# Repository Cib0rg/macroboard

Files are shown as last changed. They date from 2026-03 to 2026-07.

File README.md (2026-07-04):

# ESP32-S3 Macro Keyboard

Программируемая макроклавиатура с открытым исходным кодом на базе ESP32-S3 — 10 кнопок с индивидуальными круглыми дисплеями, RGB подсветкой и настраиваемыми действиями.




## Обзор

Устройство аналогично Elgato Stream Deck, но с открытым исходным кодом. Каждая кнопка имеет собственный круглый дисплей 160×160 для отображения иконок, RGB LED подсветку и программируемое действие.
Отсутствует ограничение по входному напряжению, подключение зарядок с QC скорее всего сожжёт часть платы!
Включать сначала питание от 2А блока (нижний разъём), потом уже подключать ESP через встроенные. Иначе есть небольшой шанс выхода из строя DC-DC преобразователя на плате ESP.

## Реализованные возможности

### Прошивка (Firmware)

- ✅ **Драйвер дисплеев GC9A01** — 10 круглых дисплеев 160×160 через SPI с мультиплексором 2× 74HC138
- ✅ **PWM подсветка дисплеев** — регулировка яркости 0-255 через LEDC
- ✅ **WS2812 RGB LED** — индивидуальная подсветка каждой кнопки с настройкой цвета и яркости
- ✅ **USB Composite Device** — HID Keyboard + Consumer Control + Vendor Bulk (TinyUSB)
- ✅ **Протокол обмена** — 64-байтовые пакеты через Vendor Bulk endpoint
- ✅ **Конфигурация** — хранение настроек кнопок и энкодера в LittleFS
- ✅ **Папки** — вложенные папки кнопок (до 8 уровней глубины)
- ✅ **Передача изображений** — JPEG изображения на кнопки с дедупликацией по CRC32
- ✅ **Асинхронная запись LittleFS** — `save_task` на Core 0, очередь 20 слотов; протокол не блокируется на I/O, sync fallback при нехватке слотов; полная синхронизация ~17 изображений: ~11 с вместо ~39 с
- ✅ **LittleFS хранилище текстов** — тексты до 4096 байт в LittleFS по 5-компонентному ключу `(profile/folder/button/action_slot/step_index)`; покрывает: Keyboard > 44 байт, long press Keyboard, каждый шаг Sequence с длинным текстом, Sequence-блоб > 51 байт
- ✅ **Rotary encoder** — настраиваемые действия на CW/CCW/нажатие/долгое нажатие
- ✅ **Долгое нажатие** — отдельное действие и название для каждой кнопки (корневой и в папках)
- ✅ **Debounced кнопки** — обработка нажатий через прерывания с программным debounce
- ✅ **Действия кнопок**: Keyboard, Media (Consumer Control), Shell, Folder, Sequence, CustomHID, LaunchApp, NightMode

### Управляющий софт (Software)

- ✅ **Кроссплатформенный UI** — Avalonia UI (Linux, Windows, macOS)
- ✅ **Backend Service** — фоновый сервис для связи с устройством
- ✅ **IPC** — TCP-based коммуникация между UI и Backend с автоматическим переподключением
- ✅ **Редактор конфигурации** — создание, редактирование, синхронизация конфигураций с устройством (JSON)
- ✅ **Конфигурация кнопок** — inline-редактор с поддержкой всех типов действий
- ✅ **Захват клавиш** — запись комбинаций клавиш в реальном времени
- ✅ **Последовательности действий** — до 16 шагов с задержками
- ✅ **Медиа-клавиши** — Volume Up/Down, Mute, Play/Pause, Next/Prev Track
- ✅ **Превью изображений** — миниатюры в списке кнопок и превью в редакторе
- ✅ **Настройка LED** — выбор цвета через ColorPicker, яркость
- ✅ **Настройка подсветки дисплеев** — слайдер яркости в Dashboard и Settings
- ✅ **Tray icon** — работа в фоне, сворачивание в трей
- ✅ **Dashboard** — статус устройства, лог событий, управление яркостью
- ✅ **Diff-based синхронизация профиля** — при Send пересылаются только изменённые кнопки; fingerprint учитывает image path+mtime, action type+JSON, LED; типовая правка одной кнопки: ~5 с; холодная синхронизация ~17 изображений: ~11 с (async SPIFFS)
- ✅ **Синхронизация с устройством** — отправка/загрузка профилей через USB
- ✅ **Сохранение профиля** — Save пишет в исходный файл (откуда был загружен через Load), а не в AppData
- ✅ **LibUsbDotNet** — кроссплатформенная USB коммуникация (Linux/Windows/macOS)
- ✅ **Плагины (Stream Deck совместимость)** — запуск `.streamDeckPlugin` архивов и исполняемых плагинов, WebSocket API на порту 28196, Property Inspector на порту 8787; плагины хранятся в `plugins/` рядом с бинарником бэкенда
- ✅ **Валидация ввода** — Shell-команда ≤ 49 байт UTF-8, Custom HID ≤ 51 байт (соответствует `ACTION_DATA_MAX_LEN` прошивки); превышение показывает ошибку вместо молчаливой обрезки
- ✅ **Кэш иконок приложений** — иконки извлекаются один раз через P/Invoke и сохраняются в `%APPDATA%\MacroKeyboard\icons\`; повторное открытие диалога не вызывает P/Invoke

## Плагины

MacroKeyboard поддерживает плагины в стиле Elgato Stream Deck. Каждая кнопка может быть привязана к действию стороннего плагина, который получает события нажатий и управляет дисплеем.

Два режима работы:
- **Executable** — отдельный процесс на любом языке (C#, Node.js, Python), общается с бекендом через WebSocket на порту 28196.
- **Managed** — .NET DLL, загружается в процесс бекенда, получает прямой доступ к устройству через `IPlugin` / `IPluginContext`.

Плагины кладутся в папку `plugins/` рядом с бинарником бекенда в виде директории или `.zip`-архива с расширением `.sdPlugin`. Существующие плагины для Stream Deck работают с минимальными изменениями.

Подробное руководство по разработке плагинов: **[PLUGIN_DEVELOPMENT.html](PLUGIN_DEVELOPMENT.html)**

## Структура проекта

```
elgato/
├── firmware/                    # Прошивка ESP32-S3 (ESP-IDF v5.4, C)
│   └── main/
│       ├── hardware/            # Драйверы: дисплеи, LED, кнопки, энкодер
│       ├── profile/             # Менеджер профилей, исполнитель действий
│       ├── protocol/            # Обработчик протокола, передача изображений и текста
│       ├── storage/             # NVS, LittleFS, профили, изображения, длинный текст, async save_task
│       └── usb/                 # USB дескрипторы, HID keyboard, vendor endpoint
│
├── hardware/                    # Аппаратная часть
│   ├── case/                    # 3D-модели корпуса (OpenSCAD + STL для печати)
│   └── pcb/                     # Схемотехника и разводка PCB (KiCad)
│
├── software/                    # Управляющее приложение (.NET 10, C#)
│   └── src/
│       ├── MacroKeyboard.Core/          # Модели, IPC, интерфейсы сервисов
│       ├── MacroKeyboard.Communication/ # USB протокол, команды устройства
│       ├── MacroKeyboard.Infrastructure/# Реализация сервисов, репозитории
│       ├── MacroKeyboard.Backend/       # Фоновый сервис (IPC сервер, роутинг)
│       └── MacroKeyboard.UI/            # Avalonia UI (MVVM, CommunityToolkit)
│
└── plans/                       # Проектная документация
```

## Быстрый старт

### Сборка прошивки

```bash
cd firmware
# Через Docker (рекомендуется):
docker run --rm -v "$(pwd)":/project -w /project espressif/idf:v5.4 idf.py build
# Или локально с установленным ESP-IDF v5.4:
idf.py build
idf.py flash
```

### Сборка софта

```bash
cd software
dotnet build MacroKeyboard.sln
# Запуск Backend:
dotnet run --project src/MacroKeyboard.Backend
# Запуск UI:
dotnet run --project src/MacroKeyboard.UI
```

### Linux: доступ к USB без root

```bash
sudo cp software/scripts/99-macrokeyboard.rules /etc/udev/rules.d/
sudo udevadm control --reload-rules
```

## Технологии

### Прошивка

| Компонент | Технология |
|---|---|
| Платформа | ESP32-S3 N16R8 (16MB Flash, 8MB PSRAM) |
| Framework | ESP-IDF v5.4 |
| RTOS | FreeRTOS |
| USB | TinyUSB (HID + Vendor composite) |
| Язык | C99 |

### Софт

| Компонент | Технология |
|---|---|
| Runtime | .NET 10 |
| UI | Avalonia UI 12 |
| Архитектура | MVVM (CommunityToolkit.Mvvm) |
| USB | LibUsbDotNet 3.x |
| Изображения | SixLabors.ImageSharp |
| Сериализация | Newtonsoft.Json |
| Логирование | Serilog |

## Аппаратные компоненты

| Компонент | Модель | Кол-во | Примечания |
|---|---|---|---|
| Микроконтроллер | ESP32-S3 N16R8 | 1 | 16MB Flash, 8MB PSRAM |
| Дисплей | GC9A01 160×160 | 10 | Круглые TFT, SPI |
| Кнопки | Тактовые | 10 | GPIO с прерываниями |
| RGB LED | WS2812 | 10 | Адресные, RMT peripheral |
| Энкодер | Rotary encoder | 1 | С кнопкой |
| Мультиплексор | 74HC138 | 2 | Выбор дисплея (5+5) |

Схемотехника и разводка PCB находятся в директории [`hardware/pcb/`](hardware/pcb/) (формат KiCad).
3D-модели корпуса для печати — в [`hardware/case/`](hardware/case/) (OpenSCAD + STL).

## Протокол обмена данными

64-байтовые пакеты через USB Vendor Bulk endpoint:

```
[0]    Magic (0xA5)
[1]    Command ID
[2-3]  Payload Length
[4-5]  Sequence Number
[6-61] Payload (56 bytes)
[62]   Checksum (XOR)
[63]   End Byte (0x5A)
```

### Команды

| ID | Команда | Описание |
|----|---|---|
| 0x01 | PING | Проверка связи |
| 0x02 | GET_DEVICE_INFO | Информация об устройстве |
| 0x10 | SET_PROFILE | Активировать профиль |
| 0x11–0x12 | GET_PROFILE_INFO / FOLDER_STATE | Состояние профиля и текущей папки |
| 0x20–0x22 | IMAGE_TRANSFER | Передача изображений (start/chunk/end) |
| 0x30–0x34 | BUTTON_ACTION/NAME | Установка действия и имени кнопки (корневые и папки) |
| 0x35 | SET_ENCODER_ACTION | Настройка действий энкодера |
| 0x36–0x37 | LONG_PRESS_ACTION/NAME | Действие и название долгого нажатия |
| 0x38–0x3A | TEXT_TRANSFER | Передача текста/блоба в SPIFFS (start/chunk/end); Keyboard > 44 байт, long press, Sequence-шаги и блобы > 51 байт |
| 0x40–0x43 | LED/BACKLIGHT | Управление LED и подсветкой дисплеев |
| 0x50–0x53 | PROFILE_SAVE/LOAD/DELETE/REFRESH | Управление профилями и обновление дисплеев |

### Типы действий

| ID | Тип | Описание |
|----|-----|---|
| 0x01 | Keyboard | Эмуляция клавиатуры; текст ≤ 44 байт — inline, > 44 байт — SPIFFS |
| 0x02 | CustomHID | Произвольный HID report |
| 0x04 | Folder | Открытие папки кнопок |
| 0x06 | Shell | Выполнение shell-команды на PC |
| 0x07 | Sequence | Последовательность до 16 действий |
| 0x08 | LaunchApp | Запуск приложения на PC |
| 0x09 | Media | Медиа-клавиши (Volume, Mute, Play/Pause и др.) |
| 0x0A | NightMode | Переключение ночного режима (снижение яркости) |
| 0x0B | Plugin | Действие стороннего плагина (Stream Deck-совместимого) |

### LittleFS-хранилище текстов

Команды 0x38–0x3A передают текстовые данные, которые не влезают inline. На устройстве файл называется `/storage/txt_{P}_{F}_{B}_{A}_{S}.bin`, где:

| Поле | Смысл |
|---|---|
| P | profile_id (всегда 0) |
| F | folder_id: 0..15 = папка, 255 = root |
| B | button_id: 0..9; энкодер: 0x40–0x43 |
| A | action slot: 0 = short press, 1 = long press |
| S | step: 0xFF = прямое Keyboard, 0xFE = Sequence-блоб, 0..15 = шаг Sequence |

Что хранится в SPIFFS:
- **Keyboard** текст > 44 байт — `step=0xFF` (short), `step=0xFF, slot=1` (long press)
- **Sequence-шаг Keyboard** > 44 байт — `step=N` (индекс шага)
- **Sequence-блоб** > 51 байт — `step=0xFE`; в `action_data` кнопки записывается маркер `[0x01]`

ПО автоматически выбирает между inline и SPIFFS. Payload CMD_SET_BUTTON_TEXT_START: 9 байт — `[profile_id][folder_id][button_id][action_slot][step_index][data_size(4 LE)]`.

## Лицензия

WTFPL

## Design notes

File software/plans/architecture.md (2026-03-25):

# Архитектура управляющего софта на C#

## Обзор

Управляющее приложение построено на базе .NET 8.0 с использованием паттерна MVVM (Model-View-ViewModel) и принципов Clean Architecture.

**Ключевая особенность**: Двухкомпонентная архитектура с Backend Service для совместимости с плагинами Elgato Stream Deck.

## Архитектура системы

```
┌─────────────────────────────────────────────────────────┐
│  MacroKeyboard.Backend (Windows Service / Daemon)       │
│  ┌───────────────────────────────────────────────────┐  │
│  │  WebSocket Server (port 28196)                    │  │
│  │  - Stream Deck API эмуляция                       │  │
│  │  - Регистрация плагинов                           │  │
│  │  - Маршрутизация событий                          │  │
│  └───────────────────────────────────────────────────┘  │
│  ┌───────────────────────────────────────────────────┐  │
│  │  Device Manager                                   │  │
│  │  - USB HID коммуникация                           │  │
│  │  - Управление устройством                         │  │
│  └───────────────────────────────────────────────────┘  │
└─────────────────────────────────────────────────────────┘
                      ↕ WebSocket
┌─────────────────────────────────────────────────────────┐
│  Plugins (HTML/JS, Node.js, Python, C#)                 │
│  - OBS Studio Control                                   │
│  - Spotify Control                                      │
│  - Discord Integration                                  │
│  - Custom Actions                                       │
└─────────────────────────────────────────────────────────┘
                      ↕ IPC / WebSocket
┌─────────────────────────────────────────────────────────┐
│  MacroKeyboard.UI (Configuration Application)           │
│  - Profile Editor                                       │
│  - Button Configuration                                 │
│  - Plugin Browser                                       │
│  - Settings                                             │
└─────────────────────────────────────────────────────────┘
```

## Технологический стек

### Основные технологии

- **.NET**: 8.0 LTS
- **UI Framework**: WPF (Windows Presentation Foundation) или Avalonia UI (кроссплатформенный)
- **Архитектурный паттерн**: MVVM
- **DI Container**: Microsoft.Extensions.DependencyInjection
- **Logging**: Serilog
- **Testing**: xUnit, Moq

### Ключевые библиотеки

```xml
<PackageReference Include="HidLibrary" Version="3.3.40" />
<PackageReference Include="CommunityToolkit.Mvvm" Version="8.2.2" />
<PackageReference Include="Serilog" Version="3.1.1" />
<PackageReference Include="Serilog.Sinks.File" Version="5.0.0" />
<PackageReference Include="SixLabors.ImageSharp" Version="3.1.0" />
<PackageReference Include="Newtonsoft.Json" Version="13.0.3" />
<PackageReference Include="Hardcodet.NotifyIcon.Wpf" Version="1.1.0" />
```

## Структура решения

```
MacroKeyboard.sln
│
├── src/
│   ├── MacroKeyboard.Backend/           # Backend Service (Windows Service/Daemon)
│   │   ├── Program.cs
│   │   ├── BackendService.cs
│   │   ├── Services/
│   │   │   ├── DeviceManager.cs
│   │   │   └── EventRouter.cs
│   │   └── appsettings.json
│   │
│   ├── MacroKeyboard.PluginSystem/      # Система плагинов
│   │   ├── WebSocketServer/
│   │   │   ├── StreamDeckWebSocketServer.cs
│   │   │   ├── MessageHandler.cs
│   │   │   └── ProtocolAdapter.cs
│   │   │
│   │   ├── PluginHost/
│   │   │   ├── PluginManager.cs
│   │   │   ├── PluginLoader.cs
│   │   │   ├── PluginProcess.cs
│   │   │   └── PluginSandbox.cs
│   │   │
│   │   ├── PluginAPI/
│   │   │   ├── IPlugin.cs
│   │   │   ├── PluginContext.cs
│   │   │   ├── PluginManifest.cs
│   │   │   └── PluginEvents.cs
│   │   │
│   │   └── ImageAdapter/
│   │       ├── ImageConverter.cs
│   │       └── CircularMask.cs
│   │
│   ├── MacroKeyboard.Core/              # Бизнес-логика (не зависит от UI)
│   │   ├── Models/
│   │   │   ├── Profile.cs
│   │   │   ├── ButtonConfig.cs
│   │   │   ├── LedConfig.cs
│   │   │   ├── ActionConfig.cs
│   │   │   └── DeviceInfo.cs
│   │   │
│   │   ├── Services/
│   │   │   ├── IDeviceService.cs
│   │   │   ├── IProfileService.cs
│   │   │   ├── IImageService.cs
│   │   │   ├── ISettingsService.cs
│   │   │   └── IOtaService.cs
│   │   │
│   │   ├── Interfaces/
│   │   │   ├── IRepository.cs
│   │   │   └── IProtocolHandler.cs
│   │   │
│   │   └── Utilities/
│   │       ├── CrcCalculator.cs
│   │       └── ImageProcessor.cs
│   │
│   ├── MacroKeyboard.Communication/     # USB/HID коммуникация
│   │   ├── HidDevice/
│   │   │   ├── HidDeviceManager.cs
│   │   │   ├── HidDeviceMonitor.cs
│   │   │   └── HidDeviceInfo.cs
│   │   │
│   │   ├── Protocol/
│   │   │   ├── ProtocolHandler.cs
│   │   │   ├── PacketBuilder.cs
│   │   │   ├── PacketParser.cs
│   │   │   └── ProtocolConstants.cs
│   │   │
│   │   └── Commands/
│   │       ├── PingCommand.cs
│   │       ├── GetDeviceInfoCommand.cs
│   │       ├── SetProfileCommand.cs
│   │       ├── ImageTransferCommand.cs
│   │       ├── SetButtonActionCommand.cs
│   │       ├── SetLedColorCommand.cs
│   │       └── OtaUpdateCommand.cs
│   │
│   ├── MacroKeyboard.Infrastructure/    # Реализация сервисов
│   │   ├── Services/
│   │   │   ├── DeviceService.cs
│   │   │   ├── ProfileService.cs
│   │   │   ├── ImageService.cs
│   │   │   ├── SettingsService.cs
│   │   │   └── OtaService.cs
│   │   │
│   │   ├── Repositories/
│   │   │   ├── ProfileRepository.cs
│   │   │   └── ImageRepository.cs
│   │   │
│   │   └── Persistence/
│   │       ├── JsonFileStorage.cs
│   │       └── AppDataManager.cs
│   │
│   ├── MacroKeyboard.UI/                # Пользовательский интерфейс
│   │   ├── App.xaml / App.xaml.cs
│   │   ├── MainWindow.xaml / MainWindow.xaml.cs
│   │   │
│   │   ├── Views/
│   │   │   ├── DashboardView.xaml
│   │   │   ├── ProfileEditorView.xaml
│   │   │   ├── ButtonConfigView.xaml
│   │   │   ├── SettingsView.xaml
│   │   │   └── DiagnosticsView.xaml
│   │   │
│   │   ├── ViewModels/
│   │   │   ├── MainViewModel.cs
│   │   │   ├── DashboardViewModel.cs
│   │   │   ├── ProfileEditorViewModel.cs
│   │   │   ├── ButtonConfigViewModel.cs
│   │   │   ├── SettingsViewModel.cs
│   │   │   └── DiagnosticsViewModel.cs
│   │   │
│   │   ├── Controls/
│   │   │   ├── ButtonGrid.xaml
│   │   │   ├── ColorPicker.xaml
│   │   │   ├── KeySelector.xaml
│   │   │   └── ImageEditor.xaml
│   │   │
│   │   ├── Converters/
│   │   │   ├── BoolToVisibilityConverter.cs
│   │   │   ├── ColorToBrushConverter.cs
│   │   │   └── ByteArrayToImageConverter.cs
│   │   │
│   │   ├── Resources/
│   │   │   ├── Styles/
│   │   │   │   ├── Colors.xaml
│   │   │   │   ├── Buttons.xaml
│   │   │   │   └── TextBoxes.xaml
│   │   │   │
│   │   │   └── Icons/
│   │   │       └── (SVG/PNG иконки)
│   │   │
│   │   └── Behaviors/
│   │       ├── DragDropBehavior.cs
│   │       └── NumericTextBoxBehavior.cs
│   │
│   ├── MacroKeyboard.TrayApp/           # Tray приложение
│   │   ├── Program.cs
│   │   ├── TrayApplicationContext.cs
│   │   ├── TrayIcon/
│   │   │   └── TrayIconManager.cs
│   │   ├── Notifications/
│   │   │   └── NotificationService.cs
│   │   └── HotKeys/
│   │       ├── HotKeyManager.cs
│   │       └── GlobalHotKey.cs
│   │
│   └── MacroKeyboard.Shared/            # Общие компоненты
│       ├── Constants.cs
│       ├── Enums.cs
│       └── Extensions/
│           ├── ColorExtensions.cs
│           └── ImageExtensions.cs
│
├── tests/
│   ├── MacroKeyboard.Core.Tests/
│   ├── MacroKeyboard.Communication.Tests/
│   └── MacroKeyboard.UI.Tests/
│
└── docs/
    ├── API.md
    ├── UserGuide.md
    └── DeveloperGuide.md
```

## Детальное описание модулей

### 1. MacroKeyboard.Core

Ядро приложения, содержит бизнес-логику и модели данных.

#### Models

**Profile.cs**
```csharp
public class Profile
{
    public int Id { get; set; }
    public string Name { get; set; }
    public List<ButtonConfig> Buttons { get; set; } = new();
    public DateTime CreatedAt { get; set; }
    public DateTime ModifiedAt { get; set; }
}
```

**ButtonConfig.cs**
```csharp
public class ButtonConfig
{
    public int Id { get; set; }
    public ActionType ActionType { get; set; }
    public ActionConfig Action { get; set; }
    public string ImagePath { get; set; }
    public LedConfig Led { get; set; }
}

public enum ActionType
{
    None,
    Keyboard,
    CustomHid,
    Macro
}
```

**ActionConfig.cs**
```csharp
public abstract class ActionConfig
{
    public abstract byte[] ToBytes();
}

public class KeyboardAction : ActionConfig
{
    public List<ModifierKey> Modifiers { get; set; } = new();
    public Key Key { get; set; }
    public string Text { get; set; }
    
    public override byte[] ToBytes()
    {
        // Конвертация в формат протокола
    }
}

public class CustomHidAction : ActionConfig
{
    public byte[] Data { get; set; }
    
    public override byte[] ToBytes() => Data;
}
```

**LedConfig.cs**
```csharp
public class LedConfig
{
    public byte R { get; set; }
    public byte G { get; set; }
    public byte B { get; set; }
    public byte Brightness { get; set; }
    public LedEffect Effect { get; set; }
}

public enum LedEffect
{
    Static = 0,
    Breathing = 1,
    Rainbow = 2
}
```

#### Services (Interfaces)

**IDeviceService.cs**
```csharp
public interface IDeviceService
{
    event EventHandler<DeviceEventArgs> DeviceConnected;
    event EventHandler<DeviceEventArgs> DeviceDisconnected;
    
    Task<bool> ConnectAsync();
    Task DisconnectAsync();
    bool IsConnected { get; }
    Task<DeviceInfo> GetDeviceInfoAsync();
    Task<bool> PingAsync();
}
```

**IProfileService.cs**
```csharp
public interface IProfileService
{
    Task<List<Profile>> GetAllProfilesAsync();
    Task<Profile> GetProfileAsync(int id);
    Task<Profile> CreateProfileAsync(string name);
    Task UpdateProfileAsync(Profile profile);
    Task DeleteProfileAsync(int id);
    Task<Profile> DuplicateProfileAsync(int id);
    Task<bool> SendProfileToDeviceAsync(Profile profile);
    Task<Profile> LoadProfileFromDeviceAsync(int id);
}
```

**IImageService.cs**
```csharp
public interface IImageService
{
    Task<byte[]> LoadImageAsync(string path);
    Task<byte[]> ResizeImageAsync(byte[] image, int width, int height);
    Task<byte[]> ConvertToJpegAsync(byte[] image, int quality = 90);
    Task SaveImageAsync(string path, byte[] image);
    Task<byte[]> CropImageAsync(byte[] image, Rectangle cropArea);
}
```

### 2. MacroKeyboard.Communication

Модуль для коммуникации с устройством через USB HID.

#### HidDevice

**HidDeviceManager.cs**
```csharp
public class HidDeviceManager : IDisposable
{
    private const int VendorId = 0x303A;  // Espressif
    private const int ProductId = 0x4001;
    
    private HidDevice _device;
    private readonly ILogger _logger;
    
    public async Task<bool> ConnectAsync()
    {
        var devices = HidDevices.Enumerate(VendorId, ProductId);
        _device = devices.FirstOrDefault();
        
        if (_device == null)
            return false;
            
        _device.OpenDevice();
        _device.MonitorDeviceEvents = true;
        _device.Inserted += OnDeviceInserted;
        _device.Removed += OnDeviceRemoved;
        
        return _device.IsOpen;
    }
    
    public async Task<byte[]> SendCommandAsync(byte[] command, int timeoutMs = 1000)
    {
        if (!_device.IsOpen)
            throw new InvalidOperationException("Device not connected");
            
        // Отправка команды
        _device.Write(command);
        
        // Ожидание ответа
        var response = await Task.Run(() => 
        {
            var data = _device.Read(timeoutMs);
            return data.Data;
        });
        
        return response;
    }
}
```

**HidDeviceMonitor.cs**
```csharp
public class HidDeviceMonitor
{
    public event EventHandler<DeviceEventArgs> DeviceArrived;
    public event EventHandler<DeviceEventArgs> DeviceRemoved;
    
    public void StartMonitoring()
    {
        // Мониторинг подключения/отключения устройств
        // Использование WMI или ManagementEventWatcher
    }
}
```

#### Protocol

**ProtocolHandler.cs**
```csharp
public class ProtocolHandler : IProtocolHandler
{
    private readonly HidDeviceManager _deviceManager;
    private readonly ILogger _logger;
    
    public async Task<TResponse> SendCommandAsync<TResponse>(ICommand<TResponse> command)
    {
        var packet = PacketBuilder.Build(command);
        var response = await _deviceManager.SendCommandAsync(packet);
        return PacketParser.Parse<TResponse>(response);
    }
}
```

**PacketBuilder.cs**
```csharp
public static class PacketBuilder
{
    public static byte[] Build(byte commandId, byte[] payload)
    {
        var packet = new byte[64];
        packet[0] = 0xA5;  // Magic byte
        packet[1] = commandId;
        
        ushort payloadLength = (ushort)payload.Length;
        packet[2] = (byte)(payloadLength & 0xFF);
        packet[3] = (byte)((payloadLength >> 8) & 0xFF);
        
        // Sequence number
        packet[4] = 0;
        packet[5] = 0;
        
        // Payload
        Array.Copy(payload, 0, packet, 6, Math.Min(payload.Length, 56));
        
        // Checksum
        packet[62] = CalculateChecksum(packet, 0, 62);
        
        // End byte
        packet[63] = 0x5A;
        
        return packet;
    }
    
    private static byte CalculateChecksum(byte[] data, int start, int length)
    {
        byte checksum = 0;
        for (int i = start; i < start + length; i++)
        {
            checksum ^= data[i];
        }
        return checksum;
    }
}
```

#### Commands

**Base Command**
```csharp
public interface ICommand<TResponse>
{
    byte CommandId { get; }
    byte[] GetPayload();
}

public abstract class CommandBase<TResponse> : ICommand<TResponse>
{
    public abstract byte CommandId { get; }
    public abstract byte[] GetPayload();
}
```

**PingCommand.cs**
```csharp
public class PingCommand : CommandBase<PingResponse>
{
    public override byte CommandId => 0x01;
    
    public override byte[] GetPayload() => Array.Empty<byte>();
}

public class PingResponse
{
    public Version FirmwareVersion { get; set; }
    public uint Uptime { get; set; }
    public byte CurrentProfile { get; set; }
}
```

**ImageTransferCommand.cs**
```csharp
public class ImageTransferCommand : CommandBase<ImageTransferResponse>
{
    public byte ProfileId { get; set; }
    public byte ButtonId { get; set; }
    public byte[] ImageData { get; set; }
    
    public override byte CommandId => 0x20;  // START_IMAGE_TRANSFER
    
    public override byte[] GetPayload()
    {
        var payload = new byte[11];
        payload[0] = ProfileId;
        payload[1] = ButtonId;
        
        // Image size (little-endian)
        uint size = (uint)ImageData.Length;
        payload[2] = (byte)(size & 0xFF);
        payload[3] = (byte)((size >> 8) & 0xFF);
        payload[4] = (byte)((size >> 16) & 0xFF);
        payload[5] = (byte)((size >> 24) & 0xFF);
        
        payload[6] = 0x01;  // Format: JPEG
        
        // Width and height
        payload[7] = 160;
        payload[8] = 0;
        payload[9] = 160;
        payload[10] = 0;
        
        return payload;
    }
    
    public async Task<bool> SendAsync(IProtocolHandler protocol)
    {
        // 1. Start transfer
        var startResponse = await protocol.SendCommandAsync(this);
        if (!startResponse.Success)
            return false;
            
        // 2. Send chunks
        const int chunkSize = 50;
        int totalChunks = (ImageData.Length + chunkSize - 1) / chunkSize;
        
        for (int i = 0; i < totalChunks; i++)
        {
            int offset = i * chunkSize;
            int length = Math.Min(chunkSize, ImageData.Length - offset);
            
            var chunk = new byte[length];
            Array.Copy(ImageData, offset, chunk, 0, length);
            
            var chunkCommand = new ImageChunkCommand
            {
                TransferId = startResponse.TransferId,
                ChunkNumber = (ushort)i,
                Data = chunk
            };
            
            var chunkResponse = await protocol.SendCommandAsync(chunkCommand);
            if (!chunkResponse.Success)
                return false;
        }
        
        // 3. End transfer
        var crc32 = Crc32.Calculate(ImageData);
        var endCommand = new ImageEndCommand
        {
            TransferId = startResponse.TransferId,
            TotalChunks = (uint)totalChunks,
            Crc32 = crc32
        };
        
        var endResponse = await protocol.SendCommandAsync(endCommand);
        return endResponse.Success && endResponse.Crc32 == crc32;
    }
}
```

### 3. MacroKeyboard.Infrastructure

Реализация сервисов и репозиториев.

**DeviceService.cs**
```csharp
public class DeviceService : IDeviceService
{
    private readonly HidDeviceManager _deviceManager;
    private readonly IProtocolHandler _protocol;
    private readonly ILogger _logger;
    
    public event EventHandler<DeviceEventArgs> DeviceConnected;
    public event EventHandler<DeviceEventArgs> DeviceDisconnected;
    
    public bool IsConnected => _deviceManager.IsConnected;
    
    public async Task<bool> ConnectAsync()
    {
        var connected = await _deviceManager.ConnectAsync();
        if (connected)
        {
            DeviceConnected?.Invoke(this, new DeviceEventArgs());
            _logger.Information("Device connected");
        }
        return connected;
    }
    
    public async Task<DeviceInfo> GetDeviceInfoAsync()
    {
        var command = new GetDeviceInfoCommand();
        var response = await _protocol.SendCommandAsync(command);
        
        return new DeviceInfo
        {
            DeviceId = response.DeviceId,
            FirmwareVersion = response.FirmwareVersion,
            ButtonCount = response.ButtonCount,
            ProfileCount = response.ProfileCount,
            CurrentProfile = response.CurrentProfile,
            FreeSpace = response.FreeSpace
        };
    }
}
```

**ProfileService.cs**
```csharp
public class ProfileService : IProfileService
{
    private readonly IProfileRepository _repository;
    private readonly IDeviceService _deviceService;
    private readonly IProtocolHandler _protocol;
    
    public async Task<List<Profile>> GetAllProfilesAsync()
    {
        return await _repository.GetAllAsync();
    }
    
    public async Task<bool> SendProfileToDeviceAsync(Profile profile)
    {
        // 1. Send profile metadata
        var setProfileCommand = new SetProfileCommand
        {
            ProfileId = (byte)profile.Id
        };
        await _protocol.SendCommandAsync(setProfileCommand);
        
        // 2. Send button configurations
        foreach (var button in profile.Buttons)
        {
            // Send action
            var actionCommand = new SetButtonActionCommand
            {
                ProfileId = (byte)profile.Id,
                ButtonId = (byte)button.Id,
                ActionType = (byte)button.ActionType,
                ActionData = button.Action.ToBytes()
            };
            await _protocol.SendCommandAsync(actionCommand);
            
            // Send image
            if (!string.IsNullOrEmpty(button.ImagePath))
            {
                var imageData = await File.ReadAllBytesAsync(button.ImagePath);
                var imageCommand = new ImageTransferCommand
                {
                    ProfileId = (byte)profile.Id,
                    ButtonId = (byte)button.Id,
                    ImageData = imageData
                };
                await imageCommand.SendAsync(_protocol);
            }
            
            // Send LED config
            var ledCommand = new SetLedColorCommand
            {
                ProfileId = (byte)profile.Id,
                ButtonId = (byte)button.Id,
                R = button.Led.R,
                G = button.Led.G,
                B = button.Led.B,
                Brightness = button.Led.Brightness,
                Effect = (byte)button.Led.Effect
            };
            await _protocol.SendCommandAsync(ledCommand);
        }
        
        // 3. Save profile on device
        var saveCommand = new SaveProfileCommand
        {
            ProfileId = (byte)profile.Id
        };
        var saveResponse = await _protocol.SendCommandAsync(saveCommand);
        
        return saveResponse.Success;
    }
}
```

### 4. MacroKeyboard.UI

Пользовательский интерфейс на WPF с MVVM.

**MainViewModel.cs**
```csharp
public partial class MainViewModel : ObservableObject
{
    private readonly IDeviceService _deviceService;
    private readonly IProfileService _profileService;
    private readonly INavigationService _navigationService;
    
    [ObservableProperty]
    private bool _isDeviceConnected;
    
    [ObservableProperty]
    private string _deviceStatus;
    
    [ObservableProperty]
    private ObservableCollection<Profile> _profiles;
    
    [ObservableProperty]
    private Profile _selectedProfile;
    
    public MainViewModel(
        IDeviceService deviceService,
        IProfileService profileService,
        INavigationService navigationService)
    {
        _deviceService = deviceService;
        _profileService = profileService;
        _navigationService = navigationService;
        
        _deviceService.DeviceConnected += OnDeviceConnected;
        _deviceService.DeviceDisconnected += OnDeviceDisconnected;
        
        InitializeAsync();
    }
    
    private async void InitializeAsync()
    {
        await _deviceService.ConnectAsync();
        await LoadProfilesAsync();
    }
    
    private async Task LoadProfilesAsync()
    {
        var profiles = await _profileService.GetAllProfilesAsync();
        Profiles = new ObservableCollection<Profile>(profiles);
    }
    
    [RelayCommand]
    private async Task CreateProfileAsync()
    {
        var profile = await _profileService.CreateProfileAsync("New Profile");
        Profiles.Add(profile);
        SelectedProfile = profile;
    }
    
    [RelayCommand]
    private async Task SendToDeviceAsync()
    {
        if (SelectedProfile == null)
            return;
            
        var success = await _profileService.SendProfileToDeviceAsync(SelectedProfile);
        if (success)
        {
            // Show success notification
        }
    }
    
    private void OnDeviceConnected(object sender, DeviceEventArgs e)
    {
        IsDeviceConnected = true;
        DeviceStatus = "Connected";
    }
    
    private void OnDeviceDisconnected(object sender, DeviceEventArgs e)
    {
        IsDeviceConnected = false;
        DeviceStatus = "Disconnected";
    }
}
```

**ProfileEditorViewModel.cs**
```csharp
public partial class ProfileEditorViewModel : ObservableObject
{
    [ObservableProperty]
    private Profile _currentProfile;
    
    [ObservableProperty]
    private ButtonConfig _selectedButton;
    
    [ObservableProperty]
    private ObservableCollection<ButtonConfig> _buttons;
    
    [RelayCommand]
    private void SelectButton(int buttonId)
    {
        SelectedButton = Buttons.FirstOrDefault(b => b.Id == buttonId);
    }
    
    [RelayCommand]
    private async Task LoadImageAsync()
    {
        var dialog = new OpenFileDialog
        {
            Filter = "Image files (*.png;*.jpg;*.bmp)|*.png;*.jpg;*.bmp"
        };
        
        if (dialog.ShowDialog() == true)
        {
            SelectedButton.ImagePath = dialog.FileName;
            // Trigger UI update
            OnPropertyChanged(nameof(SelectedButton));
        }
    }
    
    [RelayCommand]
    private void SetLedColor(Color color)
    {
        SelectedButton.Led.R = color.R;
        SelectedButton.Led.G = color.G;
        SelectedButton.Led.B = color.B;
    }
}
```

### 5. MacroKeyboard.TrayApp

Приложение в системном трее.

**TrayApplicationContext.cs**
```csharp
public class TrayApplicationContext : ApplicationContext
{
    private readonly NotifyIcon _trayIcon;
    private readonly IDeviceService _deviceService;
    private readonly IProfileService _profileService;
    private readonly HotKeyManager _hotKeyManager;
    
    public TrayApplicationContext(
        IDeviceService deviceService,
        IProfileService profileService)
    {
        _deviceService = deviceService;
        _profileService = profileService;
        _hotKeyManager = new HotKeyManager();
        
        InitializeTrayIcon();
        RegisterHotKeys();
    }
    
    private void InitializeTrayIcon()
    {
        _trayIcon = new NotifyIcon
        {
            Icon = Resources.TrayIcon,
            ContextMenuStrip = CreateContextMenu(),
            Visible = true
        };
        
        _trayIcon.DoubleClick += OnTrayIconDoubleClick;
    }
    
    private ContextMenuStrip CreateContextMenu()
    {
        var menu = new ContextMenuStrip();
        
        // Profile submenu
        var profilesMenu = new ToolStripMenuItem("Profiles");
        for (int i = 0; i < 5; i++)
        {
            int profileId = i;
            profilesMenu.DropDownItems.Add($"Profile {i + 1}", null, 
                (s, e) => SwitchProfile(profileId));
        }
        menu.Items.Add(profilesMenu);
        
        menu.Items.Add(new ToolStripSeparator());
        menu.Items.Add("Settings", null, OnSettingsClick);
        menu.Items.Add("Exit", null, OnExitClick);
        
        return menu;
    }
    
    private void RegisterHotKeys()
    {
        // Ctrl+Alt+1-5 для переключения профилей
        for (int i = 0; i < 5; i++)
        {
            int profileId = i;
            _hotKeyManager.Register(
                ModifierKeys.Control | ModifierKeys.Alt,
                Keys.D1 + i,
                () => SwitchProfile(profileId));
        }
    }
    
    private async void SwitchProfile(int profileId)
    {
        var command = new SetProfileCommand { ProfileId = (byte)profileId };
        // Send to device
        
        ShowNotification($"Switched to Profile {profileId + 1}");
    }
    
    private void ShowNotification(string message)
    {
        _trayIcon.ShowBalloonTip(2000, "Macro Keyboard", message, ToolTipIcon.Info);
    }
}
```

## Dependency Injection

**ServiceCollectionExtensions.cs**
```csharp
public static class ServiceCollectionExtensions
{
    public static IServiceCollection AddMacroKeyboardServices(
        this IServiceCollection services)
    {
        // Core services
        services.AddSingleton<IDeviceService, DeviceService>();
        services.AddSingleton<IProfileService, ProfileService>();
        services.AddSingleton<IImageService, ImageService>();
        services.AddSingleton<ISettingsService, SettingsService>();
        services.AddSingleton<IOtaService, OtaService>();
        
        // Communication
        services.AddSingleton<HidDeviceManager>();
        services.AddSingleton<IProtocolHandler, ProtocolHandler>();
        
        // Repositories
        services.AddSingleton<IProfileRepository, ProfileRepository>();
        services.AddSingleton<IImageRepository, ImageRepository>();
        
        // ViewModels
        services.AddTransient<MainViewModel>();
        services.AddTransient<DashboardViewModel>();
        services.AddTransient<ProfileEditorViewModel>();
        services.AddTransient<ButtonConfigViewModel>();
        services.AddTransient<SettingsViewModel>();
        services.AddTransient<DiagnosticsViewModel>();
        
        // Logging
        services.AddLogging(builder =>
        {
            builder.AddSerilog(new LoggerConfiguration()
                .WriteTo.File("logs/app.log", rollingInterval: RollingInterval.Day)
                .CreateLogger());
        });
        
        return services;
    }
}
```

**App.xaml.cs**
```csharp
public partial class App : Application
{
    private readonly IServiceProvider _serviceProvider;
    
    public App()
    {
        var services = new ServiceCollection();
        services.AddMacroKeyboardServices();
        _serviceProvider = services.BuildServiceProvider();
    }
    
    protected override void OnStartup(StartupEventArgs e)
    {
        base.OnStartup(e);
        
        var mainWindow = new MainWindow
        {
            DataContext = _serviceProvider.GetRequiredService<MainViewModel>()
        };
        
        mainWindow.Show();
    }
}
```

## Продолжение в следующем файле

См. [`diagrams.md`](diagrams.md) для диаграмм взаимодействия компонентов.

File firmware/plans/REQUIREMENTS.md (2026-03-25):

# Требования к прошивке ESP32-S3 макроклавиатуры

## Аппаратная платформа

1. **Основа устройства**: ESP32-S3 N16R8 (16MB Flash, 8MB PSRAM)

## Компоненты устройства

2. **Дисплеи**: 10× GC9A01 круглые дисплеи 160×160 пикселей, 0.71 дюйма
   - Подключение: SPI
   - Выбор дисплея: через схему с двумя шифраторами 74HC138
   - 4 GPIO: 3 бита адреса (A0-A2) + 1 бит выбора шифратора (SEL)

3. **Кнопки**: 10× тактовые кнопки
   - Подключение: напрямую к GPIO контроллера
   - Обработка: только через прерывания (interrupt-driven), без polling
   - Debouncing: программный, 10-50 мс

4. **RGB LED**: 10× адресные светодиоды WS2812
   - Подключение: одна нога контроллера через RMT peripheral
   - Управление: цвет и яркость задаются извне

5. **Rotary Encoder**: 1× энкодер с кнопкой
   - Назначение: переключение профилей
   - Обработка: через GPIO прерывания

## USB подключение

4. Устройство подключается к компьютеру по native USB и определяется как:
   - **USB HID Keyboard** - для эмуляции нажатий клавиш
   - **USB HID Raw Device** - для обмена данными с управляющим софтом
   - **USB CDC (UART)** - для логирования диагностических данных (опционально)

## Функциональные требования

### Основная схема работы

7. **Взаимодействие с управляющим софтом**:
   - Управляющий софт отправляет изображения для экранов
   - Управляющий софт отправляет команды, закрепленные за кнопками
   - Команды двух видов:
     * "Отпечатать текст как клавиатура" (HID Keyboard)
     * "Послать сигнал как отдельное устройство" (HID Raw)

8. **Хранение данных**:
   - Устройство сохраняет команды и изображения в энергонезависимую память (Flash)
   - Использование SPIFFS для файловой системы
   - Использование NVS для настроек

9. **Отображение и реакция**:
   - Отрисовка изображений на дисплеях
   - Реакция на нажатия кнопок согласно сохраненным командам
   - Обновление RGB LED согласно профилю

### Профили

10. **Rotary Encoder**:
    - Используется для переключения профилей клавиш и экранов
    - Текущий профиль хранится на устройстве
    - Поддержка 3-5 профилей

11. **Логический юнит**:
    - Блок "светодиод + кнопка + экран" является единым юнитом
    - Яркость и цвет светодиода задаются извне контроллера
    - Изображение на экране соответствует функции кнопки

## Обязательные функции

6. **WiFi OTA**: ОБЯЗАТЕЛЬНО наличие WiFi OTA обновления прошивки
   - Подключение к WiFi по credentials из управляющего софта
   - Загрузка firmware по HTTP/HTTPS
   - Автоматический rollback при ошибке

## Дополнительные требования

### Производительность

- **Button latency**: < 10 мс от нажатия до действия
- **Display update**: < 50 мс на обновление одного дисплея
- **Profile switch**: < 100 мс на переключение профиля
- **Boot time**: < 2 секунды

### Надежность

- Проверка целостности данных (CRC32)
- Обработка ошибок и восстановление
- Защита от износа flash (wear leveling)
- Сохранение состояния при отключении питания

### Удобство использования

- Визуальная обратная связь через LED
- Статичные изображения на дисплеях (без анимаций)
- Логирование для отладки (опционально через USB CDC)

## Формат данных

### Изображения

- **Рекомендуемый формат**: JPEG
- **Размер**: 160×160 пикселей
- **Качество**: 80-90%
- **Средний размер файла**: 8-15 КБ

### Протокол обмена

- **Интерфейс**: USB HID Raw
- **Размер пакета**: 64 байта
- **Формат**: см. [`protocol.md`](../../plans/protocol.md)

## Ссылки на детальную документацию

- [Протокол обмена данными](../../plans/protocol.md)
- [Архитектура прошивки](../../plans/architecture.md)
- [Структура хранения данных](../../plans/storage.md)
- [Диаграммы взаимодействия](../../plans/system_flow.md)
- [План имплементации](../../plans/implementation_plan.md)
- [Использование готовых компонентов ESP-IDF](../../plans/esp_idf_components.md)
- [План тестирования](../../plans/testing_plan.md)

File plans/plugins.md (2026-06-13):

# Plugin System — Plan

> **Sequencing note:** Implement this plan before `ui_refactor.md`. The UI refactor's
> Config Panel (Phase 3) and Action Picker (Phase 2) explicitly depend on the plugin
> data structures and IPC API defined here. Running plugins first means the UI refactor
> is a clean port of known, working code rather than speculative scaffolding.

## Текущее состояние

Скелет написан, но ни в чём не подключён:
- `PluginManager` — дискавери и загрузка плагинов (executable + managed), не инстанциируется в DI
- `WebSocketServer` — WS на порту 28196 (совместим с Stream Deck API), не стартует
- `IPlugin` / `IPluginContext` / `PluginManifest` — интерфейсы готовы
- `ActionExecutorService` — нет case для Plugin actions
- `PluginContext` — все методы заглушки (`// TODO`)
- `CustomHid` — неправильная архитектура (отсылает данные на PC вместо прямой отправки USB HID)

## Архитектурные решения

### Два разных механизма — не путать

**Plugin Action** (`ActionType.Plugin = 0x0B`) — кнопка вызывает конкретный action конкретного плагина. Полностью на PC-стороне: firmware просто сообщает "нажата кнопка X", backend читает профиль, находит `PluginId + ActionId + Settings`, маршрутизирует в плагин.

**Custom HID** (`ActionType.CustomHid = 0x02`) — firmware сам посылает raw USB HID report напрямую в систему. PC не участвует. Сейчас реализован наоборот — надо переделать в firmware.

### Плагины бывают двух типов

- **Executable** (Node.js, Python и т.д.) — запускаются как отдельный процесс, общаются через WebSocket на порту 28196 с Stream Deck-совместимым протоколом (`keyDown`, `keyUp`, `didReceiveSettings`, и т.д.)
- **Managed** (.NET DLL) — загружаются в изолированный `AssemblyLoadContext`, вызываются напрямую через `IPlugin`

### Как кнопка знает о плагине

Профиль хранит `PluginActionConfig { PluginId, ActionId, Settings }`. Firmware хранит это как непрозрачный blob (action_type=0x0B + raw bytes). При нажатии firmware шлёт EVENT_BUTTON_PRESSED с buttonId. Backend читает свою копию профиля, достаёт `PluginActionConfig`, маршрутизирует.

### UI: откуда берётся список plugin actions

Backend держит список загруженных манифестов. UI запрашивает его через IPC при открытии редактора. Actions из манифестов добавляются в палитру (правая колонка) после стандартных actions.

> **Совместимость с ui_refactor.md:** Фаза 6 ниже использует текущую `ActionPaletteItems`
> инфраструктуру (drag-and-drop палитра). После выполнения `ui_refactor.md` Phase 2
> палитра заменяется Action Picker'ом, и `PluginActionInfo` объекты становятся входными
> данными для `ActionTypeRegistry.RegisterPlugin()`. Переход требует только изменений в
> Phase 6 UI-кода — Core/Backend части (Фазы 1–5) остаются без изменений.

---

## Фазы

---

### Фаза 1 — Core Models

**Файлы:**
- `MacroKeyboard.Core/Models/ActionType.cs`
- `MacroKeyboard.Core/Models/ActionConfig.cs`
- `MacroKeyboard.Core/Plugin/IPlugin.cs`

**Задачи:**

1. Добавить `Plugin = 0x0B` в enum `ActionType`.

2. Добавить класс `PluginActionConfig` в `ActionConfig.cs`:
   ```csharp
   public class PluginActionConfig : ActionConfig
   {
       public override ActionType ActionType => ActionType.Plugin;
       public string PluginId { get; set; } = string.Empty;
       public string ActionId { get; set; } = string.Empty;
       public string? Settings { get; set; }  // JSON строка с настройками action

       public override byte[] ToBytes()
       {
           // [pluginId\0actionId\0settings\0] — null-terminated strings
           var pluginIdBytes = Encoding.UTF8.GetBytes(PluginId + "\0");
           var actionIdBytes = Encoding.UTF8.GetBytes(ActionId + "\0");
           var settingsBytes = Encoding.UTF8.GetBytes((Settings ?? "") + "\0");
           return [..pluginIdBytes, ..actionIdBytes, ..settingsBytes];
       }
   }
   ```
   Добавить в `FromActionType` factory и в JSON десериализацию (`IpcCommandHandler`).

3. Обновить `IPlugin.OnButtonPressedAsync` — передавать actionId и settings:
   ```csharp
   Task OnButtonPressedAsync(string actionId, string? settings, int buttonIndex, CancellationToken ct = default);
   Task OnButtonReleasedAsync(string actionId, string? settings, int buttonIndex, CancellationToken ct = default);
   ```

---

### Фаза 2 — Firmware

**Файлы:**
- `firmware/main/profile/profile_types.h`
- `firmware/main/profile/action_executor.c`
- `firmware/main/hardware/usb_hid_keyboard.h` / `.c`

**Задачи:**

1. Добавить `ACTION_TYPE_PLUGIN = 0x0B` в `action_type_t`.
   Добавить метку `"Plugin"` в `profile_manager.c` (label switch).

2. Добавить case `ACTION_TYPE_PLUGIN` в `execute_single_action`:
   ```c
   case ACTION_TYPE_PLUGIN:
       // Поведение идентично обычному нажатию — backend читает профиль сам
       // Firmware просто репортит кнопку, весь dispatch на PC
       // Ничего дополнительно делать не надо
       break;
   ```
   (EVENT_BUTTON_PRESSED уже отсылается общим кодом после switch.)

3. **Исправить Custom HID** — убрать отсылку на PC, вместо этого слать raw USB HID report:
   ```c
   case ACTION_TYPE_CUSTOM_HID:
       if (data_len > 0)
           usb_hid_send_raw_report(data, data_len);
       break;
   ```
   Добавить `usb_hid_send_raw_report(const uint8_t* data, uint16_t len)` в `usb_hid_keyboard.h` и реализовать в `.c` (передать в нужный HID endpoint).

---

### Фаза 3 — Backend: PluginContext + PluginManager

**Файлы:**
- `MacroKeyboard.Backend/Plugin/PluginManager.cs`

**Задачи:**

1. Внедрить `IDeviceService` в `PluginContext` (сейчас он принимает только `ILogger`):
   ```csharp
   internal class PluginContext : IPluginContext
   {
       private readonly IDeviceService _deviceService;
       // ...
   }
   ```

2. Реализовать все заглушки в `PluginContext`:
   - `SetButtonImageAsync` → `_deviceService.SendButtonImageAsync(0, buttonIndex, imageData)`
   - `SetButtonTitleAsync` → `_deviceService.SetButtonNameAsync(0, buttonIndex, title)`
   - `SetLedColorAsync` → `_deviceService.SetLedColorAsync(0, buttonIndex, new LedConfig { R=r, G=g, B=b })`
   - `ShowAlertAsync` → flash LED: выкл на 200ms, вкл обратно
   - `GetSettingsAsync` / `SaveSettingsAsync` → JSON файл в `%APPDATA%\MacroKeyboard\plugins\{pluginId}\settings.json`

3. Добавить `DispatchButtonPressAsync` в `PluginManager`:
   ```csharp
   public async Task DispatchButtonPressAsync(string pluginId, string actionId,
       string? settings, int buttonIndex, CancellationToken ct = default)
   ```
   - Для managed плагина: вызвать `_pluginInstance.OnButtonPressedAsync(actionId, settings, buttonIndex, ct)`
   - Для executable плагина: отправить через `WebSocketServer.BroadcastAsync` событие `keyDown` в формате Stream Deck:
     ```json
     { "event": "keyDown", "action": "{actionId}", "context": "{pluginId}:{buttonIndex}", "payload": { "settings": {...}, "coordinates": {...} } }
     ```

4. Добавить аналогичный `DispatchButtonReleaseAsync`.

5. Добавить `GetLoadedActions()`:
   ```csharp
   public IEnumerable<(string PluginId, string PluginName, PluginAction Action)> GetLoadedActions()
   ```
   Нужен для UI — формирует список доступных plugin actions для палитры/пикера.

---

### Фаза 4 — Backend: DI и жизненный цикл

**Файлы:**
- `MacroKeyboard.Backend/Program.cs`
- `MacroKeyboard.Backend/BackendService.cs`

**Задачи:**

1. Зарегистрировать в `Program.cs`:
   ```csharp
   builder.Services.AddSingleton<PluginManager>(sp => new PluginManager(
       sp.GetRequiredService<ILogger<PluginManager>>(),
       Path.Combine(AppContext.BaseDirectory, "plugins")));
   builder.Services.AddSingleton<WebSocketServer>();
   ```

2. В `BackendService.StartAsync`:
   ```csharp
   await _webSocketServer.StartAsync(ct);
   await _pluginManager.LoadPluginsAsync(ct);
   // start all loaded plugins
   foreach (var manifest in _pluginManager.GetPlugins())
       await _pluginManager.StartPluginAsync(manifest.Id, ct);
   ```

3. В `BackendService.StopAsync` — остановить плагины и WS сервер.

---

### Фаза 5 — Backend: ActionExecutorService + IPC

**Файлы:**
- `MacroKeyboard.Backend/Services/ActionExecutorService.cs`
- `MacroKeyboard.Backend/Services/IpcCommandHandler.cs`
- `MacroKeyboard.Shared/IPC/IpcMessage.cs`

**Задачи:**

1. Внедрить `PluginManager` в `ActionExecutorService`. Добавить case:
   ```csharp
   case ActionType.Plugin:
       await ExecutePluginActionAsync(e.ProfileId, e.ButtonId);
       break;
   ```
   ```csharp
   private async Task ExecutePluginActionAsync(byte profileId, byte buttonId)
   {
       var profile = await _profileService.GetProfileAsync(profileId);
       var button = profile?.Buttons.FirstOrDefault(b => b.ButtonId == buttonId);
       if (button?.Action is not PluginActionConfig action) return;
       await _pluginManager.DispatchButtonPressAsync(
           action.PluginId, action.ActionId, action.Settings, buttonId);
   }
   ```

2. Добавить IPC команду `plugin.list` в `IpcCommandHandler`:
   - Обрабатывает запрос от UI
   - Возвращает список `(pluginId, pluginName, actionId, actionName, actionIcon, tooltip)` из `_pluginManager.GetLoadedActions()`

3. Добавить `MessageType` константу `"plugin.list"` в `IpcMessage.cs`.

---

### Фаза 6 — UI: палитра + настройка plugin actions

**Файлы:**
- `MacroKeyboard.UI/ViewModels/ProfileEditorViewModel.cs`
- `MacroKeyboard.UI/ViewModels/ButtonConfigDialogViewModel.cs`
- `MacroKeyboard.UI/Views/ProfileEditorView.axaml`

> **Временная реализация:** этот UI-слой использует текущую drag-and-drop палитру.
> После выполнения `ui_refactor.md` Phase 2 он будет заменён на Action Picker —
> `PluginActionInfo` объекты станут источником данных для `ActionTypeRegistry.RegisterPlugin()`.
> Core/Backend код (Фазы 1–5) при этом не меняется.

**Задачи:**

1. В `ProfileEditorViewModel` при инициализации запросить плагины через IPC:
   ```csharp
   var pluginActions = await _ipcClient.SendRequestAsync<List<PluginActionInfo>>("plugin.list");
   foreach (var pa in pluginActions)
   {
       ActionPaletteItems.Add(new ActionPaletteItem(ActionType.Plugin, pa.ActionName, pa.Icon, pa.Tooltip)
       {
           PreConfiguredAction = new PluginActionConfig
           {
               PluginId = pa.PluginId,
               ActionId = pa.ActionId
           }
       });
   }
   ```
   Плагины добавляются в конец палитры после "None", сгруппированные по плагину.

2. В `ButtonConfigDialogViewModel`:
   - Добавить `IsPluginAction => SelectedActionType == ActionType.Plugin`
   - Добавить свойства `PluginId`, `PluginActionId`, `PluginSettings` (string, JSON)
   - В `Save()` добавить case:
     ```csharp
     ActionType.Plugin => new PluginActionConfig
     {
         PluginId = PluginId,
         ActionId = PluginActionId,
         Settings = string.IsNullOrWhiteSpace(PluginSettings) ? null : PluginSettings
     }
     ```
   - В `CurrentActionDisplayName` добавить `ActionType.Plugin => $"Plugin: {PluginActionId}"`
   - В `CurrentActionIcon` добавить `ActionType.Plugin => "🔌"`
   - В загрузке (`if (buttonConfig.Action is PluginActionConfig pa)`) — заполнить поля

3. В `ProfileEditorView.axaml` добавить секцию для Plugin action (появляется когда `IsPluginAction`):
   ```xml
   <Border IsVisible="{Binding IsPluginAction}" ...>
     <StackPanel>
       <TextBlock Text="PLUGIN ACTION" />
       <TextBlock Text="{Binding PluginId}" Opacity="0.6" />  <!-- read-only -->
       <TextBlock Text="Settings (JSON):" />
       <TextBox Text="{Binding PluginSettings}" AcceptsReturn="True" Height="80"
                PlaceholderText="{}" FontFamily="Monospace" />
     </StackPanel>
   </Border>
   ```

4. В `FlattenedButtonItem.Label` / `ActionText` добавить отображение для `PluginActionConfig`:
   ```csharp
   PluginActionConfig pa => $"🔌 {pa.ActionId}",
   ```

---

### Фаза 7 — Custom HID: UI fix

**Файлы:**
- `MacroKeyboard.UI/ViewModels/ButtonConfigDialogViewModel.cs`
- `MacroKeyboard.UI/Views/ProfileEditorView.axaml`
- `MacroKeyboard.Backend/Services/ActionExecutorService.cs`

После исправления firmware Custom HID больше не требует PC-обработки. Нужно:

1. В UI заменить "coming soon" на поле ввода hex-данных (уже есть в `SequenceStepViewModel` — скопировать паттерн):
   - Добавить `CustomHidData` property в `ButtonConfigDialogViewModel`
   - Добавить `ParseHexString` (скопировать из `SequenceStepViewModel`)
   - В `Save()` добавить: `ActionType.CustomHid => new CustomHidAction { Data = ParseHexString(CustomHidData) }`
   - В `ProfileEditorView.axaml` заменить "coming soon" на `<TextBox Text="{Binding CustomHidData}" Placeholder="FF 00 A0 ..." />`

2. Убрать Custom HID из `ActionExecutorService` (он не нужен — firmware всё делает сам). Ничего добавлять не надо, просто не добавлять case.

---

## Зависимости между фазами

```
Фаза 1 (Core Models)
    ├── Фаза 2 (Firmware) — независима, можно параллельно
    ├── Фаза 3 (PluginManager) — зависит от Фазы 1 (новый IPlugin.OnButtonPressedAsync)
    │       └── Фаза 4 (DI) — зависит от Фазы 3
    │               └── Фаза 5 (ActionExecutor + IPC) — зависит от Фаз 1, 3, 4
    │                       └── Фаза 6 (UI) — зависит от Фазы 5
    └── Фаза 7 (Custom HID fix) — почти независима, только Фаза 2 нужна для firmware части
```

## Что НЕ входит в план (за рамками v1)

- **Property Inspector** — загрузка HTML-файла плагина как настроечного UI (полная Stream Deck совместимость). В v1 достаточно JSON text area.
- **Hot reload плагинов** — сейчас требует перезапуска backend.
- **Plugin marketplace / установщик** — просто папка `plugins/` рядом с бинарником.
- **Версионирование API** — `MinimumBackendVersion` в манифесте пока не проверяется.
- **Права доступа плагинов** — плагин может делать всё что позволяет `IPluginContext`, без ограничений.

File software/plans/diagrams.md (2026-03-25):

# Диаграммы взаимодействия управляющего софта

## Архитектура приложения

```mermaid
graph TB
    subgraph UI["Presentation Layer (WPF/Avalonia)"]
        VIEWS[Views]
        VM[ViewModels]
        CONTROLS[Custom Controls]
    end
    
    subgraph CORE["Core Layer"]
        MODELS[Models]
        INTERFACES[Interfaces]
        SERVICES[Service Interfaces]
    end
    
    subgraph INFRA["Infrastructure Layer"]
        IMPL[Service Implementations]
        REPOS[Repositories]
        STORAGE[File Storage]
    end
    
    subgraph COMM["Communication Layer"]
        HID[HID Device Manager]
        PROTOCOL[Protocol Handler]
        COMMANDS[Commands]
    end
    
    VIEWS --> VM
    VM --> SERVICES
    SERVICES --> IMPL
    IMPL --> REPOS
    IMPL --> PROTOCOL
    PROTOCOL --> HID
    PROTOCOL --> COMMANDS
    REPOS --> STORAGE
    
    VM --> MODELS
    IMPL --> MODELS
```

## Запуск приложения

```mermaid
sequenceDiagram
    participant USER as Пользователь
    participant APP as App.xaml.cs
    participant DI as DI Container
    participant MAIN as MainWindow
    participant VM as MainViewModel
    participant DEV as DeviceService
    participant PROF as ProfileService
    
    USER->>APP: Запуск приложения
    APP->>DI: ConfigureServices()
    DI->>DI: Register all services
    DI-->>APP: ServiceProvider
    
    APP->>MAIN: Create MainWindow
    APP->>DI: GetService<MainViewModel>()
    DI->>VM: new MainViewModel(services...)
    VM->>DEV: Subscribe to events
    VM->>DEV: ConnectAsync()
    
    DEV->>DEV: Search for device
    alt Device found
        DEV-->>VM: DeviceConnected event
        VM->>PROF: LoadProfilesAsync()
        PROF-->>VM: List<Profile>
        VM->>VM: Update UI
    else Device not found
        DEV-->>VM: Device not found
        VM->>VM: Show "Connect device" message
    end
    
    APP->>MAIN: Show()
    MAIN-->>USER: Application ready
```

## Подключение к устройству

```mermaid
sequenceDiagram
    participant UI as UI
    participant VM as ViewModel
    participant DEV as DeviceService
    participant HID as HidDeviceManager
    participant MON as DeviceMonitor
    participant PROTO as ProtocolHandler
    
    UI->>VM: User clicks "Connect"
    VM->>DEV: ConnectAsync()
    DEV->>HID: ConnectAsync()
    
    HID->>HID: Enumerate USB devices
    HID->>HID: Find device (VID/PID)
    
    alt Device found
        HID->>HID: OpenDevice()
        HID->>MON: StartMonitoring()
        HID-->>DEV: Connected
        
        DEV->>PROTO: PingAsync()
        PROTO->>HID: SendCommand(PING)
        HID-->>PROTO: Response
        PROTO-->>DEV: Device responsive
        
        DEV->>PROTO: GetDeviceInfoAsync()
        PROTO->>HID: SendCommand(GET_DEVICE_INFO)
        HID-->>PROTO: DeviceInfo
        PROTO-->>DEV: DeviceInfo
        
        DEV-->>VM: DeviceConnected event
        VM->>VM: Update UI (show device info)
        VM-->>UI: "Connected" status
    else Device not found
        HID-->>DEV: Not found
        DEV-->>VM: Connection failed
        VM-->>UI: "Device not found" error
    end
```

## Создание и настройка профиля

```mermaid
sequenceDiagram
    participant UI as ProfileEditorView
    participant VM as ProfileEditorViewModel
    participant PROF as ProfileService
    participant REPO as ProfileRepository
    participant FS as FileSystem
    
    UI->>VM: User clicks "New Profile"
    VM->>PROF: CreateProfileAsync("Gaming")
    
    PROF->>PROF: Create Profile object
    PROF->>PROF: Initialize 10 buttons
    PROF->>REPO: SaveAsync(profile)
    
    REPO->>FS: Write JSON file
    FS-->>REPO: Success
    REPO-->>PROF: Profile saved
    PROF-->>VM: Profile created
    
    VM->>VM: Add to Profiles list
    VM->>VM: Set as SelectedProfile
    VM-->>UI: Update UI
    
    Note over UI,VM: User configures buttons
    
    loop For each button
        UI->>VM: SelectButton(buttonId)
        VM->>VM: Set SelectedButton
        
        UI->>VM: LoadImage()
        VM->>VM: OpenFileDialog
        UI-->>VM: Image path selected
        VM->>VM: Update button.ImagePath
        
        UI->>VM: SetAction(KeyboardAction)
        VM->>VM: Update button.Action
        
        UI->>VM: SetLedColor(color)
        VM->>VM: Update button.Led
        
        VM->>PROF: UpdateProfileAsync(profile)
        PROF->>REPO: SaveAsync(profile)
        REPO->>FS: Write JSON
    end
    
    UI->>VM: User clicks "Send to Device"
    VM->>PROF: SendProfileToDeviceAsync(profile)
    Note over PROF: See "Отправка профиля на устройство"
```

## Отправка профиля на устройство

```mermaid
sequenceDiagram
    participant VM as ViewModel
    participant PROF as ProfileService
    participant PROTO as ProtocolHandler
    participant IMG as ImageService
    participant DEV as Device
    
    VM->>PROF: SendProfileToDeviceAsync(profile)
    
    PROF->>PROTO: SetProfile(profileId)
    PROTO->>DEV: SET_PROFILE command
    DEV-->>PROTO: OK
    
    loop For each button (0-9)
        Note over PROF: Send button configuration
        
        PROF->>PROTO: SetButtonAction(profileId, buttonId, action)
        PROTO->>DEV: SET_BUTTON_ACTION command
        DEV-->>PROTO: OK
        
        alt Button has image
            PROF->>IMG: LoadImageAsync(imagePath)
            IMG-->>PROF: imageData
            
            PROF->>IMG: ConvertToJpegAsync(imageData)
            IMG-->>PROF: jpegData
            
            PROF->>PROTO: StartImageTransfer(profileId, buttonId, jpegData)
            PROTO->>DEV: START_IMAGE_TRANSFER
            DEV-->>PROTO: transferId
            
            PROF->>PROF: Split image into chunks
            loop For each chunk
                PROF->>PROTO: SendImageChunk(transferId, chunkNum, data)
                PROTO->>DEV: IMAGE_DATA_CHUNK
                DEV-->>PROTO: ACK
            end
            
            PROF->>PROTO: EndImageTransfer(transferId, crc32)
            PROTO->>DEV: END_IMAGE_TRANSFER
            DEV-->>PROTO: OK (CRC verified)
        end
        
        PROF->>PROTO: SetLedColor(profileId, buttonId, led)
        PROTO->>DEV: SET_LED_COLOR command
        DEV-->>PROTO: OK
        
        PROF->>VM: Progress update (button X/10)
        VM->>VM: Update progress bar
    end
    
    PROF->>PROTO: SaveProfile(profileId)
    PROTO->>DEV: SAVE_PROFILE command
    DEV->>DEV: Write to flash
    DEV-->>PROTO: OK
    
    PROF-->>VM: Profile sent successfully
    VM->>VM: Show success notification
```

## OTA обновление

```mermaid
sequenceDiagram
    participant UI as SettingsView
    participant VM as SettingsViewModel
    participant OTA as OtaService
    participant HTTP as HTTP Server
    participant PROTO as ProtocolHandler
    participant DEV as Device
    
    UI->>VM: User selects firmware file
    VM->>VM: OpenFileDialog
    UI-->>VM: firmware.bin selected
    
    UI->>VM: User clicks "Update Firmware"
    VM->>OTA: StartOtaUpdateAsync(firmwarePath)
    
    OTA->>OTA: Calculate MD5
    OTA->>HTTP: Start local HTTP server
    HTTP->>HTTP: Serve firmware file
    HTTP-->>OTA: Server URL
    
    OTA->>PROTO: SetWifiCredentials(ssid, password)
    PROTO->>DEV: SET_WIFI_CREDENTIALS
    DEV-->>PROTO: OK
    
    OTA->>PROTO: GetWifiStatus()
    PROTO->>DEV: GET_WIFI_STATUS
    
    loop Wait for WiFi connection
        DEV->>DEV: Connect to WiFi
        PROTO->>DEV: GET_WIFI_STATUS
        DEV-->>PROTO: Status
        
        alt Connected
            PROTO-->>OTA: WiFi connected
        else Connecting
            OTA->>OTA: Wait 1 second
        else Error
            PROTO-->>OTA: WiFi error
            OTA-->>VM: Update failed
            VM-->>UI: Show error
        end
    end
    
    OTA->>PROTO: StartOtaUpdate(url, size, md5)
    PROTO->>DEV: START_OTA_UPDATE
    DEV->>DEV: Start OTA task
    DEV-->>PROTO: Started
    
    loop Monitor OTA progress
        OTA->>PROTO: GetOtaStatus()
        PROTO->>DEV: GET_OTA_STATUS
        DEV-->>PROTO: Status + Progress
        PROTO-->>OTA: Status info
        
        OTA->>VM: Progress update
        VM->>VM: Update progress bar
        VM-->>UI: Show progress (X%)
        
        alt Complete
            OTA-->>VM: OTA complete
            VM-->>UI: "Update successful, device rebooting"
        else Error
            OTA-->>VM: OTA error
            VM-->>UI: Show error message
        end
    end
    
    Note over DEV: Device reboots with new firmware
    
    OTA->>HTTP: Stop HTTP server
    HTTP-->>OTA: Stopped
```

## Tray Application - Переключение профиля

```mermaid
sequenceDiagram
    participant USER as Пользователь
    participant TRAY as TrayIcon
    participant CTX as TrayContext
    participant HK as HotKeyManager
    participant PROF as ProfileService
    participant PROTO as ProtocolHandler
    participant DEV as Device
    
    alt Via Context Menu
        USER->>TRAY: Right click
        TRAY->>CTX: Show context menu
        CTX-->>USER: Menu with profiles
        USER->>CTX: Select "Profile 2"
        CTX->>PROF: SwitchProfileAsync(1)
    else Via Hot Key
        USER->>HK: Press Ctrl+Alt+2
        HK->>CTX: HotKey triggered
        CTX->>PROF: SwitchProfileAsync(1)
    end
    
    PROF->>PROTO: SetProfile(profileId=1)
    PROTO->>DEV: SET_PROFILE command
    DEV->>DEV: Switch to profile 1
    DEV->>DEV: Update displays
    DEV->>DEV: Update LEDs
    DEV-->>PROTO: OK
    PROTO-->>PROF: Success
    
    PROF-->>CTX: Profile switched
    CTX->>TRAY: ShowBalloonTip("Switched to Profile 2")
    TRAY-->>USER: Notification
```

## Диагностика - Просмотр логов

```mermaid
sequenceDiagram
    participant UI as DiagnosticsView
    participant VM as DiagnosticsViewModel
    participant LOG as LoggingService
    participant CDC as USB CDC
    participant DEV as Device
    
    UI->>VM: User opens Diagnostics
    VM->>LOG: EnableDeviceLogging()
    
    LOG->>CDC: Connect to CDC port
    CDC->>DEV: Enable logging
    DEV-->>CDC: OK
    
    loop Continuous logging
        DEV->>CDC: Log message
        CDC->>LOG: Parse log entry
        LOG->>LOG: Filter by level
        LOG->>VM: New log entry
        VM->>VM: Add to ObservableCollection
        VM-->>UI: Update log view
    end
    
    alt User filters logs
        UI->>VM: SetLogLevel(Warning)
        VM->>VM: Filter logs
        VM-->>UI: Show filtered logs
    end
    
    alt User saves logs
        UI->>VM: SaveLogs()
        VM->>LOG: SaveToFile(path)
        LOG->>LOG: Write to file
        LOG-->>VM: Saved
        VM-->>UI: "Logs saved"
    end
    
    UI->>VM: User closes Diagnostics
    VM->>LOG: DisableDeviceLogging()
    LOG->>CDC: Disconnect
```

## Обработка ошибок

```mermaid
flowchart TB
    START([Operation Start]) --> TRY{Try operation}
    
    TRY -->|Success| SUCCESS[Operation successful]
    TRY -->|Exception| CATCH[Catch exception]
    
    CATCH --> TYPE{Exception type?}
    
    TYPE -->|DeviceNotConnectedException| RECONNECT[Attempt reconnect]
    RECONNECT --> RETRY{Retry?}
    RETRY -->|Yes| TRY
    RETRY -->|No| ERROR[Show error]
    
    TYPE -->|TimeoutException| TIMEOUT[Operation timeout]
    TIMEOUT --> RETRY2{Retry?}
    RETRY2 -->|Yes| TRY
    RETRY2 -->|No| ERROR
    
    TYPE -->|InvalidDataException| VALIDATE[Validate data]
    VALIDATE --> FIX{Can fix?}
    FIX -->|Yes| TRY
    FIX -->|No| ERROR
    
    TYPE -->|Other| LOG[Log exception]
    LOG --> ERROR
    
    ERROR --> NOTIFY[Notify user]
    NOTIFY --> END([End])
    
    SUCCESS --> END
```

## State Machine приложения

```mermaid
stateDiagram-v2
    [*] --> Initializing
    Initializing --> Disconnected: Init complete
    
    Disconnected --> Connecting: Connect attempt
    Connecting --> Connected: Device found
    Connecting --> Disconnected: Connection failed
    
    Connected --> Idle: Ready
    Idle --> ConfiguringProfile: Edit profile
    Idle --> SendingProfile: Send to device
    Idle --> UpdatingFirmware: Start OTA
    Idle --> Disconnected: Device unplugged
    
    ConfiguringProfile --> Idle: Save/Cancel
    
    SendingProfile --> SendingAction: For each button
    SendingAction --> SendingImage: Action sent
    SendingImage --> SendingLED: Image sent
    SendingLED --> SendingAction: LED sent (next button)
    SendingLED --> SavingProfile: All buttons done
    SavingProfile --> Idle: Profile saved
    SendingProfile --> Idle: Error
    
    UpdatingFirmware --> ConnectingWiFi: WiFi credentials sent
    ConnectingWiFi --> Downloading: WiFi connected
    Downloading --> Installing: Download complete
    Installing --> Rebooting: Install complete
    Rebooting --> Disconnected: Device reboots
    UpdatingFirmware --> Idle: Error
    
    Idle --> [*]: Application exit
```

## Архитектура данных

```mermaid
erDiagram
    PROFILE ||--o{ BUTTON_CONFIG : contains
    BUTTON_CONFIG ||--|| ACTION_CONFIG : has
    BUTTON_CONFIG ||--|| LED_CONFIG : has
    BUTTON_CONFIG ||--o| IMAGE : has
    
    PROFILE {
        int Id
        string Name
        DateTime CreatedAt
        DateTime ModifiedAt
    }
    
    BUTTON_CONFIG {
        int Id
        int ProfileId
        ActionType ActionType
        string ImagePath
    }
    
    ACTION_CONFIG {
        int Id
        ActionType Type
        byte[] Data
    }
    
    LED_CONFIG {
        int Id
        byte R
        byte G
        byte B
        byte Brightness
        LedEffect Effect
    }
    
    IMAGE {
        int Id
        string Path
        byte[] Data
        int Width
        int Height
    }
```

## Поток данных при настройке кнопки

```mermaid
flowchart LR
    USER[Пользователь] -->|Выбирает изображение| UI[UI]
    UI -->|LoadImageAsync| IMG[ImageService]
    IMG -->|Загружает файл| FS[FileSystem]
    FS -->|Данные изображения| IMG
    IMG -->|Масштабирует 160x160| IMG
    IMG -->|Конвертирует в JPEG| IMG
    IMG -->|Сохраняет| REPO[ImageRepository]
    REPO -->|Путь к файлу| UI
    
    USER -->|Настраивает действие| UI
    UI -->|UpdateAction| VM[ViewModel]
    VM -->|Обновляет модель| MODEL[ButtonConfig]
    
    USER -->|Выбирает цвет LED| UI
    UI -->|SetLedColor| VM
    VM -->|Обновляет модель| MODEL
    
    USER -->|Нажимает Save| UI
    UI -->|SaveAsync| PROF[ProfileService]
    PROF -->|Сохраняет профиль| REPO2[ProfileRepository]
    REPO2 -->|Записывает JSON| FS
    
    USER -->|Нажимает Send| UI
    UI -->|SendToDeviceAsync| PROF
    PROF -->|Отправляет команды| PROTO[ProtocolHandler]
    PROTO -->|USB HID| DEV[Device]
```

## Многопоточность

```mermaid
graph TB
    subgraph UI_THREAD["UI Thread"]
        XAML[XAML Views]
        VM[ViewModels]
        DISPATCHER[Dispatcher]
    end
    
    subgraph WORKER_THREADS["Worker Threads"]
        USB[USB Communication]
        IMG[Image Processing]
        FILE[File I/O]
        NET[Network OTA]
    end
    
    subgraph BACKGROUND["Background Tasks"]
        MONITOR[Device Monitor]
        LOG[Log Reader]
    end
    
    XAML --> VM
    VM -->|async/await| USB
    VM -->|async/await| IMG
    VM -->|async/await| FILE
    VM -->|async/await| NET
    
    USB -->|Invoke| DISPATCHER
    IMG -->|Invoke| DISPATCHER
    FILE -->|Invoke| DISPATCHER
    NET -->|Invoke| DISPATCHER
    
    DISPATCHER --> VM
    
    MONITOR -->|Events| DISPATCHER
    LOG -->|Events| DISPATCHER
```

## Производительность

### Целевые показатели

| Операция | Целевое время | Приемлемое время |
|---|---|---|
| Запуск приложения | < 2 с | < 3 с |
| Подключение к устройству | < 500 мс | < 1 с |
| Загрузка профиля | < 100 мс | < 200 мс |
| Отправка профиля | < 5 с | < 10 с |
| Обработка изображения | < 500 мс | < 1 с |
| Переключение профиля | < 200 мс | < 500 мс |
| OTA обновление | < 2 мин | < 5 мин |

### Оптимизации

1. **Асинхронные операции**: Все I/O операции async/await
2. **Кэширование**: Кэширование обработанных изображений
3. **Lazy loading**: Загрузка данных по требованию
4. **Виртуализация UI**: Виртуализация списков профилей
5. **Параллелизм**: Параллельная отправка данных на устройство

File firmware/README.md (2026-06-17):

# ESP32-S3 Macro Keyboard Firmware

Прошивка для макроклавиатуры на базе ESP32-S3 с 10 кнопками, дисплеями и RGB подсветкой.

## Возможности

- 10 программируемых кнопок с дисплеями GC9A01 (160×160)
- Rotary encoder с настраиваемыми действиями (CW/CCW/нажатие/долгое нажатие)
- Долгое нажатие на любой кнопке с отдельным действием и названием
- RGB подсветка WS2812 под каждой кнопкой
- USB Composite Device: HID Keyboard + Consumer Control + Vendor Bulk interface
- Папки кнопок с вложенностью до 8 уровней
- Передача изображений JPEG с дедупликацией по CRC32
- Длинный текст для Keyboard-действия: до 4096 байт через SPIFFS (пароли, авто-ответы)
- Конфигурация с сохранением в SPIFFS

## Структура проекта

```
firmware/
├── main/
│   ├── main.c                  # Точка входа
│   ├── config.h                # Конфигурация (пины, лимиты, пути)
│   ├── hardware/               # Драйверы железа (дисплеи, LED, кнопки, энкодер)
│   ├── usb/                    # USB интерфейсы (HID keyboard, vendor bulk)
│   ├── protocol/               # Протокол обмена (handler, image_transfer, text_transfer)
│   ├── storage/                # Работа с памятью (profile_storage, image_storage, text_storage)
│   ├── profile/                # Управление профилями (profile_manager, action_executor)
│   └── utils/                  # Утилиты (crc, jpeg, text_render, logger)
├── CMakeLists.txt
├── partitions.csv
└── sdkconfig.defaults
```

## Сборка

### Через Docker (рекомендуется)

```bash
cd firmware
docker run --rm -v "$(pwd)":/project -w /project espressif/idf:v5.4 idf.py build
```

### Локально (требуется ESP-IDF v5.4)

```bash
cd firmware
idf.py build
idf.py -p /dev/ttyUSB0 flash monitor
```

## Конфигурация

Основные параметры в [`config.h`](main/config.h):

- `NUM_BUTTONS` — количество кнопок (10)
- `NUM_FOLDERS` — количество папок (16)
- `FOLDER_STACK_DEPTH` — максимальная вложенность папок (8)
- `DISPLAY_WIDTH/HEIGHT` — размер дисплеев (160×160)
- `STORAGE_BASE_PATH` — базовый путь SPIFFS (`/storage`)
- GPIO пины для всех компонентов

### Мультиплексор дисплеев

Два 74HC138 дешифратора, по 5 дисплеев на каждый:

```
Decoder 1 (SEL=1): Displays 0-4 (верхний ряд)
Decoder 2 (SEL=0): Displays 5-9 (нижний ряд)

GPIO:
  PIN_MUX_A0 (GPIO16) — адресная линия 0
  PIN_MUX_A1 (GPIO17) — адресная линия 1
  PIN_MUX_A2 (GPIO18) — адресная линия 2
  PIN_MUX_SEL (GPIO21) — выбор дешифратора (1=первый, 0=второй)
```

## Протокол

Обмен данными через **USB Vendor Bulk** интерфейс (Interface 1 составного USB-устройства).

### Формат пакета (64 байта)

```
Offset  Size  Description
------  ----  -----------
0       1     Magic byte (0xA5)
1       1     Command ID
2       2     Payload length (little-endian)
4       2     Sequence number (little-endian)
6       56    Payload data
62      1     Checksum (XOR bytes 0-61)
63      1     End byte (0x5A)
```

### Команды (PC → Device)

| ID | Команда | Описание |
|----|---|---|
| `0x01` | `CMD_PING` | Проверка связи |
| `0x02` | `CMD_GET_DEVICE_INFO` | Информация об устройстве |
| `0x10` | `CMD_SET_PROFILE` | Активация профиля |
| `0x11` | `CMD_GET_PROFILE_INFO` | Информация о профиле |
| `0x12` | `CMD_GET_FOLDER_STATE` | Текущее состояние папки |
| `0x20` | `CMD_START_IMAGE_TRANSFER` | Начало передачи изображения |
| `0x21` | `CMD_IMAGE_DATA_CHUNK` | Фрагмент изображения |
| `0x22` | `CMD_END_IMAGE_TRANSFER` | Завершение передачи изображения |
| `0x30` | `CMD_SET_BUTTON_ACTION` | Настройка действия кнопки |
| `0x31` | `CMD_GET_BUTTON_ACTION` | Чтение действия кнопки |
| `0x32` | `CMD_SET_BUTTON_NAME` | Название кнопки |
| `0x33` | `CMD_SET_FOLDER_BUTTON_ACTION` | Действие кнопки в папке |
| `0x34` | `CMD_SET_FOLDER_BUTTON_NAME` | Название кнопки в папке |
| `0x35` | `CMD_SET_ENCODER_ACTION` | Настройка действий энкодера |
| `0x36` | `CMD_SET_BUTTON_LONG_PRESS_ACTION` | Действие долгого нажатия |
| `0x37` | `CMD_SET_BUTTON_LONG_PRESS_NAME` | Название действия долгого нажатия |
| `0x38` | `CMD_SET_BUTTON_TEXT_START` | Начало передачи длинного текста |
| `0x39` | `CMD_SET_BUTTON_TEXT_CHUNK` | Фрагмент длинного текста |
| `0x3A` | `CMD_SET_BUTTON_TEXT_END` | Завершение передачи текста → сохраняет в SPIFFS |
| `0x40` | `CMD_SET_LED_COLOR` | Настройка цвета LED |
| `0x41` | `CMD_SET_BACKLIGHT` | Яркость дисплеев |
| `0x42` | `CMD_GET_LED_COLOR` | Чтение цвета LED |
| `0x43` | `CMD_SET_FOLDER_BUTTON_LED` | LED кнопки в папке |
| `0x50` | `CMD_SAVE_PROFILE` | Сохранение профиля в SPIFFS |
| `0x53` | `CMD_REFRESH_DISPLAYS` | Обновление всех дисплеев |

### События (Device → PC)

| ID | Событие | Описание |
|----|---|---|
| `0xF0` | `EVENT_BUTTON_PRESSED` | Кнопка нажата |
| `0xF1` | `EVENT_ENCODER_ROTATED` | Энкодер повёрнут |
| `0xF4` | `EVENT_DEVICE_READY` | Устройство готово |
| `0xF5` | `EVENT_FOLDER_ENTERED` | Вход в папку |
| `0xF6` | `EVENT_FOLDER_EXITED` | Выход из папки |

### Типы действий

| ID | Тип | Описание |
|----|-----|---|
| `0x01` | `Keyboard` | HID клавиатура; текст ≤ 44 байт — inline, > 44 байт — SPIFFS |
| `0x02` | `CustomHID` | Произвольный HID report |
| `0x04` | `Folder` | Вход в папку |
| `0x06` | `Shell` | Команда на стороне PC |
| `0x07` | `Sequence` | Последовательность действий |
| `0x08` | `LaunchApp` | Запуск приложения на PC |
| `0x09` | `Media` | Consumer Control (Volume, Mute, Play/Pause…) |
| `0x0A` | `NightMode` | Переключение ночного режима |
| `0x0B` | `Plugin` | Stream Deck-совместимый плагин |

## SPIFFS-хранилище

```
/storage/
├── profile_0.bin        # Профиль устройства (binary)
├── img_<crc32>.raw      # Изображения с дедупликацией по CRC32
├── img_map.bin          # Таблица маппинга (profile, button) → CRC32
└── txt_<pid>_<bid>.bin  # Длинный текст для Keyboard-действий (до 4096 байт)
```

Синтетический `button_id` для хранения:
- Корневые кнопки: `bid = button_id` (0–9)
- Кнопки в папке: `bid = NUM_BUTTONS + folder_id * NUM_BUTTONS + button_id`

## Разработка

### Добавление новой команды протокола

1. Добавить константу в [`protocol/protocol_types.h`](main/protocol/protocol_types.h)
2. Создать forward-декларацию и handler в [`protocol/protocol_handler.c`](main/protocol/protocol_handler.c)
3. Добавить запись в `command_table[]`
4. Зарегистрировать `.c` файл нового модуля в [`CMakeLists.txt`](main/CMakeLists.txt)

### Добавление нового действия кнопки

1. Добавить тип в [`profile/profile_types.h`](main/profile/profile_types.h)
2. Реализовать в [`profile/action_executor.c`](main/profile/action_executor.c)

## Отладка

Логи выводятся через UART0 (GPIO43/44). Уровень логирования настраивается в `sdkconfig`.

## Лицензия

MIT License

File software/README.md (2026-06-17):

# MacroKeyboard Software

Управляющее программное обеспечение для ESP32-S3 макроклавиатуры с круглыми дисплеями.

## Описание

Полнофункциональная система управления макроклавиатурой, включающая:
- **Backend Service** — фоновый сервис для коммуникации с устройством
- **Configuration UI** — графический интерфейс настройки (Avalonia UI)
- **Plugin System** — поддержка плагинов (Stream Deck API совместимость)

## Возможности

- Кроссплатформенность — Windows, Linux, macOS
- USB Vendor Bulk — LibUsbDotNet (работает везде без драйверов)
- Backend Service — Windows Service / Linux Systemd
- Modern UI — Avalonia UI (тёмная тема, MVVM)
- Plugin System — Node.js, Python, C# плагины; WebSocket Stream Deck API
- IPC — TCP-сокеты между UI и Backend
- Длинный текст для Keyboard-действий — до 4096 байт через SPIFFS (пароли, авто-ответы, API-ключи)
- Сохранение профиля — Save пишет в файл, откуда был загружен (не в AppData)
- Загрузка с устройства — не затирает настройки папок, только мержит корневые кнопки

## Архитектура

```
ESP32-S3 Device
    ↕ USB Vendor Bulk
Backend Service
├── IPC Server (:28195)  → UI
├── WebSocket (:28196)   → Plugins
└── DeviceService        → USB протокол
```

## Проекты

| Проект | Описание |
|---|---|
| MacroKeyboard.Core | Модели, интерфейсы сервисов |
| MacroKeyboard.Communication | USB протокол, команды устройства |
| MacroKeyboard.Infrastructure | Реализация сервисов, репозитории |
| MacroKeyboard.Shared | IPC типы, Plugin API |
| MacroKeyboard.Backend | Фоновый сервис (IPC сервер, роутинг) |
| MacroKeyboard.UI | Avalonia UI (MVVM, CommunityToolkit) |

## Быстрый старт

### Требования

- .NET 10 SDK
- Linux: `libudev-dev libusb-1.0-0-dev`

### Сборка и запуск

```bash
cd software
dotnet restore
dotnet build MacroKeyboard.sln

# Backend Service
dotnet run --project src/MacroKeyboard.Backend

# UI (в другом терминале)
dotnet run --project src/MacroKeyboard.UI
```

### Linux: доступ к USB без root

```bash
sudo cp scripts/99-macrokeyboard.rules /etc/udev/rules.d/
sudo udevadm control --reload-rules
```

## Технологии

| Компонент | Технология |
|---|---|
| Runtime | .NET 10 |
| UI | Avalonia UI 12 |
| Архитектура | MVVM (CommunityToolkit.Mvvm) |
| USB | LibUsbDotNet 3.x |
| Изображения | SixLabors.ImageSharp |
| Сериализация | Newtonsoft.Json |
| Логирование | Serilog |

## Работа с профилями

Профили хранятся как JSON-файлы в `%APPDATA%/MacroKeyboard/Profiles/`. При открытии профиля через File → Load устанавливается `SourceFilePath`, и последующее нажатие Save пишет именно в этот файл. Если профиль не был загружен из файла (создан в UI или пришёл с устройства), Save пишет в AppData.

Загрузка с устройства (Load from Device) объединяет данные с устройства только для корневых кнопок — действия и LED. Настройки папок, изображения и пользовательские имена сохраняются из локального профиля.

## Длинный текст (SPIFFS)

Для Keyboard-действий с текстом длиннее 44 байт ПО автоматически использует трёхфазный протокол передачи (CMD 0x38/0x39/0x3A). Текст сохраняется на устройстве в SPIFFS и загружается при нажатии кнопки. Лимит — 4096 байт.

## Plugin System

```javascript
// manifest.json
{
  "Id": "com.example.myplugin",
  "Name": "My Plugin",
  "Version": "1.0.0",
  "Type": "executable",
  "Runtime": "node",
  "EntryPoint": "index.js"
}

// index.js
const WebSocket = require('ws');
const ws = new WebSocket('ws://localhost:28196');

ws.on('message', (data) => {
  const message = JSON.parse(data);
  console.log('Received:', message);
});
```

## Лицензия

TBD

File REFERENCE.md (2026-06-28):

# Architecture Reference

Текущее состояние реализации и неочевидные детали, которые не видны из кода напрямую.

---

## Что реализовано, что нет

### Firmware (реализовано)
- `hardware/`: gc9a01 (дисплей), display_mux, buttons, encoder, leds, night_mode
- `protocol/`: protocol_handler, packet_parser, image_transfer, protocol_types
- `profile/`: profile_manager, action_executor, profile_types
- `storage/`: profile_storage, image_storage, nvs_manager, save_task
- `usb/`: usb_hid_keyboard, usb_vendor, usb_descriptors
- `utils/`: logger, crc, jpeg_decoder, text_render

### Firmware (не реализовано)
- WiFi — конфиги в `config.h` есть, `wifi_manager.c` нет
- OTA — `ota_updater.c` нет
- USB CDC — `usb_cdc.c` нет, вместо него `usb_vendor.c`

### Software (реализовано)
- MacroKeyboard.Backend — `ActionExecutorService`, `DeviceManager`, `EventRouter`, `IpcCommandHandler`, `IpcServer`, `ShellCommandExecutor`
- MacroKeyboard.Communication — все команды протокола
- MacroKeyboard.Core — все модели, IPC интерфейсы
- MacroKeyboard.Infrastructure — `DeviceService`, `ImageService`, `ProfileService` (diff-based sync)
- MacroKeyboard.UI — `ProfileEditorView`, `ButtonConfigDialogViewModel` (разбит на 7 partial-файлов: `.Sequence`, `.LedColor`, `.Image`, `.KeyCapture`, `.Plugin`, `.LaunchApp`), полный UI

### Software (реализовано, плагины)
- `PluginManager` — загрузка, жизненный цикл, маршрутизация SD-протокола
- `WebSocketServer` — WS сервер порт 28196, обе привязки `localhost` и `127.0.0.1`
- `PropertyInspectorServer` — HTTP файловый сервер порт 8787 для PI-страниц
- `ActionType.Plugin = 0x0B` — добавлен в enum и поддержан в firmware/software

### Software (не существует)
- **TrayApp** — проекта `MacroKeyboard.TrayApp` нет, UI открывается напрямую

---

## Протокол (актуальная таблица команд)

Пакет: 64 байта. Magic = **0xA5**, End = 0x5A.

> Внимание: в `config.h` есть `#define PROTOCOL_MAGIC 0xEA` — это комментарий-задумка, а не
> реальный байт. Реальный magic определён в `protocol_types.h` как `PROTOCOL_MAGIC_BYTE = 0xA5`.

```
0x01  CMD_PING
0x02  CMD_GET_DEVICE_INFO
0x10  CMD_SET_PROFILE
0x11  CMD_GET_PROFILE_INFO
0x20  CMD_START_IMAGE_TRANSFER
0x21  CMD_IMAGE_DATA_CHUNK
0x22  CMD_END_IMAGE_TRANSFER
0x23  CMD_GET_BUTTON_IMAGE

0x30  CMD_SET_BUTTON_ACTION
0x31  CMD_GET_BUTTON_ACTION
0x32  CMD_SET_BUTTON_NAME
0x33  CMD_SET_FOLDER_BUTTON_ACTION
0x34  CMD_SET_FOLDER_BUTTON_NAME
0x35  CMD_SET_ENCODER_ACTION
0x36  CMD_SET_BUTTON_LONG_PRESS_ACTION
0x37  CMD_SET_BUTTON_LONG_PRESS_NAME

0x40  CMD_SET_LED_COLOR
0x41  CMD_SET_BACKLIGHT
0x42  CMD_GET_LED_COLOR
0x43  CMD_SET_FOLDER_BUTTON_LED

0x50  CMD_SAVE_PROFILE
0x51  CMD_LOAD_PROFILE
0x52  CMD_DELETE_PROFILE
0x53  CMD_REFRESH_DISPLAYS

0x60  CMD_START_OTA_UPDATE
0x61  CMD_GET_OTA_STATUS
0x70  CMD_SET_WIFI_CREDENTIALS
0x71  CMD_GET_WIFI_STATUS
0x80  CMD_ENABLE_DEBUG_LOG
0x81  CMD_FACTORY_RESET

0xF0  EVENT_BUTTON_PRESSED
0xF1  EVENT_ENCODER_ROTATED
0xF2  EVENT_ENCODER_BUTTON
0xF3  EVENT_PROFILE_CHANGED
0xF4  EVENT_DEVICE_READY
0xF5  EVENT_FOLDER_ENTERED
0xF6  EVENT_FOLDER_EXITED
0xFF  EVENT_ERROR
```

---

## Типы действий (firmware ↔ software)

| Hex  | Firmware | C# (ActionType) |
|---|---|---|
| 0x00 | ACTION_TYPE_NONE | None |
| 0x01 | ACTION_TYPE_KEYBOARD | Keyboard |
| 0x02 | ACTION_TYPE_CUSTOM_HID | CustomHid |
| 0x03 | ACTION_TYPE_PROFILE_SWITCH| ProfileSwitch |
| 0x04 | ACTION_TYPE_FOLDER | Folder |
| 0x05 | ACTION_TYPE_DELAY | Delay |
| 0x06 | ACTION_TYPE_SHELL | Shell |
| 0x07 | ACTION_TYPE_SEQUENCE | Sequence |
| 0x08 | ACTION_TYPE_LAUNCH_APP | LaunchApp |
| 0x09 | ACTION_TYPE_MEDIA | Media |
| 0x0A | ACTION_TYPE_NIGHT_MODE | NightMode |
| 0x0B | ACTION_TYPE_PLUGIN | Plugin |

Delay (0x05) и Shell/LaunchApp/Media/NightMode — реализованы в firmware и software.

---

## Производительность и синхронизация профиля

### Временны́е показатели (измерено 2026-06-21)

| Сценарий | До оптимизаций | После Fix 1 (async SPIFFS) | Планируется Fix 2 (bulk chunk) |
|---|---|---|---|
| Полный профиль, ~17 изображений | ~39 с | **~11 с** | ~3–5 с |
| Правка одной кнопки (diff) | ~5 с | ~5 с | ~2–3 с |

**Fix 1 (реализован):** `save_task` — SPIFFS-запись асинхронна; `CMD_END_IMAGE_TRANSFER (0x22)` отвечает ~50 мс (только JPEG-декод) вместо 50–2500 мс.

**Fix 2 (план):** объединить все chunk-пакеты в одну `WriteAsync()`-передачу в `ImageTransferCommand`. 164 чанка × 4.7 мс LibUSB overhead = 770 мс/изображение → 7 мс/изображение. Экономия ~11 с. Требует увеличения `protocol_cmd_queue` до 256 в firmware (текущий depth = 32).

**Fix 3 (план):** декаплинг `profile_refresh_displays()` от `CMD_REFRESH_DISPLAYS (0x53)` — вынести в асинхронный постинг после отправки ответа. Экономия ~1–1.5 с.

### Diff-based send (ProfileService.cs)

При каждом `SendProfileToDeviceAsync` пересылаются только кнопки/encoder/папки, чья конфигурация изменилась с последней отправки. Типовое «изменить одну кнопку» — ~5 с вместо ~39 с (полный профиль с 10 изображениями).

**Fingerprint кнопки** (`ComputeButtonFingerprint`):
```
{image_path}\x01{mtime_ticks}   ← или "none" / "missing\x01{path}"
\x1F {button.Name}
\x1F {action_type_name}:{JSON}
\x1F {long_press_action_type_name}:{JSON}
\x1F {long_press_name}
\x1F {led.R},{led.G},{led.B},{led.Brightness}
```

**Кэш:** `Dictionary<(profileId, folderId, buttonId), string> _sentConfigCache` в памяти backend. Ключи:
- Корневые кнопки: `(profileId, 0xFF, buttonId)`
- Кнопки в папках: `(profileId, folderId, buttonId)`
- Encoder: `(profileId, 0xFE, 0xFF)`

Кэш сбрасывается при отключении устройства (`DeviceDisconnected`) или при смене активного профиля.

**Порядок команд при Send (только изменённые элементы):**
```
CMD SET_PROFILE            ← всегда; если тот же слот — no-op в firmware
CMD IMAGE_TRANSFER × N     ← только кнопки с изменённым изображением
CMD SET_BUTTON_ACTION × N
CMD SET_BUTTON_NAME × N
CMD SET_LED_COLOR × N
...аналогично для папок и encoder...
CMD SAVE_PROFILE           ← всегда (drain + NVS persist)
CMD REFRESH_DISPLAYS       ← всегда
```

Если ни один элемент не изменился, `SendProfileToDeviceAsync` возвращает `true` сразу, без CMD SAVE/REFRESH.

**Плагин-кнопки без `ImagePath`:** при каждом send после reconnect (кэш пуст) получают фиолетовый ring placeholder. Это критично: без него `image_size = 0` в SPIFFS/NVS → `profile_refresh_displays()` рисует `btn->name` текстом вместо изображения до прихода `willAppear`. Ring перезаписывается реальным состоянием плагина через ~800 мс. При последующих sends в той же сессии (fingerprint в кэше) ring не пересылается — CMD REFRESH показывает сохранённое в SPIFFS состояние от предыдущего `willAppear`.

---

### Async SPIFFS: save_task

`firmware/main/storage/save_task.c` — FreeRTOS-задача на Core 0, принимает записи через очередь и пишет JPEG-файлы в SPIFFS независимо от протокол-задачи.

**Параметры:**
```c
#define SAVE_QUEUE_DEPTH      20   // ≈ 20 × 50 KB = 1 MB PSRAM в пике
#define SAVE_QUEUE_SYNC_BELOW  3   // при < 3 свободных слотах — sync fallback
```

**Путь `save_task_save_image()`:**
1. `free_slots >= 3` → копирует буфер в PSRAM, `pending_inc()`, `xQueueSend` → async.
2. `free_slots < 3`, ошибка alloc или race на очереди → синхронный `image_storage_save()` + `update_image_size()` прямо в вызывающей задаче.

`update_image_size()` вызывается из `save_task_fn` **после** успешной записи:
```c
prof->buttons[button_id].image_size = DISPLAY_BUFFER_SIZE;
```
Это единственное место, где `image_size` устанавливается в `> 0` для async-пути.

**Drain race и `pending_count`:**

Наивный drain (ждать пока очередь пуста, затем взять semaphore) имел race: задача сняла элемент из очереди — очередь уже пуста — но `image_size` ещё не обновлён. Drain возвращался, CMD SAVE записывал профиль с `image_size = 0`. После перезагрузки устройство показывало текст вместо изображения.

Исправление: `s_pending` (spinlock `portMUX_TYPE`) инкрементируется **до** `xQueueSend`, декрементируется **после** `write + update_image_size + free`:

```c
// save_task_save_image:
pending_inc();
if (xQueueSend(...) != pdTRUE) { pending_dec(); /* fallback */ }

// save_task_fn:
image_storage_save(...);
update_image_size(...);
free(cmd.rgb565_buf);
pending_dec();          // ← только здесь

// save_task_drain:
while (pending_get() > 0) vTaskDelay(pdMS_TO_TICKS(20));
```

**CMD SAVE_PROFILE (0x50) всегда вызывает drain перед NVS:**
```c
save_task_drain();
profile_save_to_storage(profile_id);   // NVS видит актуальные image_size
```

---

### SPIFFS хранилище текстов (text_storage)

Отдельный механизм от image-хранилища. Используется для данных, которые не влезают inline в `action_data[51]`.

**Путь файла:**
```
/storage/txt_{P}_{F}_{B}_{A}_{S}.bin
```

| Компонент | Тип | Значения |
|---|-----|---|
| P | profile_id | всегда 0 |
| F | folder_id | 0..15 = папка; 255 = root |
| B | button_id | 0..9; энкодер: 0x40 CW, 0x41 CCW, 0x42 press, 0x43 long press |
| A | action_slot | 0 = short press, 1 = long press |
| S | step_index | 0xFF = прямое Keyboard (`TEXT_STEP_DIRECT`); 0xFE = Sequence-блоб (`TEXT_STEP_SEQ_BLOB`); 0..15 = шаг N |

**Что хранится и где:**

| Тип данных | Условие | slot A | step S |
|---|---|---|---|
| Keyboard-текст (short press) | > 44 байт UTF-8 | 0 | 0xFF |
| Keyboard-текст (long press) | > 44 байт UTF-8 | 1 | 0xFF |
| Keyboard-текст шага N в Sequence | > 44 байт | slot кнопки | N |
| Sequence-блоб | > 51 байт | slot кнопки | 0xFE |

**Маркеры в `action_data`:**
- Keyboard+SPIFFS: `data[0]=modifiers, data[1]=0x00, data[2]=0x01` — firmware читает текст из файла
- Sequence+SPIFFS: `data[0]=0x01, data_len=1` — firmware читает блоб из файла, выполняет как inline sequence

**Протокол (CMD_SET_BUTTON_TEXT_START, 0x38) — payload 9 байт:**
```
[profile_id][folder_id][button_id][action_slot][step_index][data_size(4 байт LE)]
```
(до SPIFF.md рефакторинга был 7 байт без `action_slot`/`step_index`)

**Логика в DeviceService.cs:**
- `SendSpiffsDataAsync` — базовая передача (START → CHUNK × N → END)
- `SendActionAsync` — диспетчер: длинный Keyboard и Sequence → SPIFFS, остальное inline
- `SendSequenceActionAsync` + `BuildSequenceBlob` — собирает блоб, заменяет длинные шаги маркерами, при необходимости шлёт шаговые тексты и блоб отдельными SPIFFS-передачами

**Совместимость:** старый формат пути `/storage/txt_{P}_{old_bid}.bin` несовместим с новым. Существующие SPIFFS-кнопки дадут `ESP_ERR_NOT_FOUND` и не напечатают текст — нужно пересохранить профиль через software.

---

## Firmware: неочевидные детали

### Дисплей

- Чип фактически **GC9D01** (схожий с GC9A01 но с отличиями в инициализации). Файл называется `gc9a01.c`.
- **Partial window write работает некорректно** — при записи в частичный регион дисплей отображает мусор. Обходное решение: всегда composit полный кадр 160×160 в буфер, затем отправлять целиком.
- **Split display**: каждый дисплей делится на зоны:
  - `SPLIT_SHORT_H = 96` px — верхние 60% (short press action label)
  - `SPLIT_LONG_H = 64` px — нижние 40% (long press action label)
  - Белый разделитель между зонами
  - Реализовано в `text_render.c` через `text_render_fill_region()`

### Энкодер

- Направление определяется lookup table `encoder_table[16]` в `encoder.c`, индексируется 4-битным состоянием `(prev_AB << 2) | curr_AB`.
- Шаги **накапливаются**: только при `abs(accumulator) >= ENCODER_STEPS_PER_PROFILE` (= 4) срабатывает действие. Это предотвращает ложные срабатывания при вибрации.
- Пины **A=41, B=40** (были перепутаны и исправлены — не менять обратно).

### Профиль и хранение

- Профили: `/storage/profile_%d.bin`
- Изображения: `/storage/img_%d_%d.jpg` (profile_id, button_id)
- `button_config_t` содержит два независимых набора action data: основной (short press) и `long_press_*`.
- Поле `name[32]` — отображаемая метка на дисплее (если нет изображения).
- Поле `long_press_name[32]` — кастомная метка для нижней зоны split display; если пустое — генерируется автоматически из типа действия.
- `FOLDER_STACK_DEPTH = 8` (в `config.h`) — максимальная вложенность папок.

### USB

- Устройство идентифицируется как **"Elgato" / "Stream Deck"** (`USB_MANUFACTURER` и `USB_PRODUCT` в `config.h`). Это обеспечивает частичную совместимость с экосистемой Stream Deck.
- Raw HID реализован через **`usb_vendor.c`**, не `usb_hid_raw.c` (тот не написан).

---

## Software: неочевидные детали

### IPC и процессы

- Backend ↔ UI общаются через **Named Pipes** (библиотека `H.Pipes`), не WebSocket.
- Нет отдельного TrayApp процесса — UI открывается напрямую.
- Backend запускается как `IHostedService` внутри того же процесса или отдельно — зависит от точки входа.

### Encoder ButtonId convention

В software encoder слоты имеют условные ButtonId:
```
200 = Clockwise (CW)
201 = Counter-Clockwise (CCW)
202 = Short Press
203 = Long Press
```
Это не firmware ID — firmware имеет отдельный `encoder_config_t`. Эти числа используются только в UI для идентификации слота конфигурации.

### Long press synthetic ID

При открытии конфигурации long press через `ConfigureButtonLongPress`, создаётся синтетический `ButtonConfig` с `ButtonId = originalButtonId + 100`. Это позволяет повторно использовать `ButtonConfigDialogViewModel` для long press без дублирования UI. **Фаза 3 ui_refactor.md этот механизм убирает.**

### Inline Config Panel visibility

`ProfileEditorView.axaml` содержит inline-панель внутри `DataTemplate` для `FlattenedButtonItem`. Панель видима через boolean-свойство в `FlattenedButtonItem`. Encoder config (ButtonId 200-203 не входят в `FlattenedButtons`) требует отдельной панели — `IsEncoderConfigVisible`.

### Лимиты действий (firmware protocol)

`ACTION_DATA_MAX_LEN = 51` байт — максимальный размер `action_data` в `button_config_t` прошивки. Лимиты по типу:

| Тип | Лимит | Причина |
|-----|---|---|
| CustomHID | 51 байт | `Data` передаётся напрямую |
| Shell | 49 байт UTF-8 | 1 байт флагов + команда + 1 байт null-терминатора |
| Keyboard inline | 44 байт UTF-8 | 7 байт — заголовок KeyboardAction |

`ButtonConfigDialogViewModel.ValidateBeforeSave()` проверяет CustomHID и Shell перед сохранением и устанавливает `SaveError` (observable string) при нарушении лимита.

### Кэш иконок приложений

Иконки извлекаются через Shell32 P/Invoke и сохраняются в `%APPDATA%\MacroKeyboard\icons\{appname}.png`. При повторном открытии диалога `ExtractAndSetAppIconAsync` проверяет `File.Exists(iconOutputPath)` перед вызовом P/Invoke — извлечение происходит только один раз за установку приложения.

### Директория плагинов

Backend хардкодит путь к плагинам: `Path.Combine(AppContext.BaseDirectory, "plugins")`. Настройка `PluginsDirectory` в UI Settings была удалена — она никогда не читалась бэкендом. Плагины нужно класть рядом с `MacroKeyboard.Backend.exe` в поддиректорию `plugins/`.

### Папки в UI

- `FlattenedButtonItem` содержит `ParentFolder` (null для корневых кнопок).
- Кнопки-папки и кнопки внутри папок плоско перечислены в `FlattenedButtons`, сгруппированные по папке.
- `ProfileEditorViewModel.OpenFolderAsync` переключает контекст отображения.

---

## Система папок

Полностью реализована в firmware и software.

### Firmware

`profile_t` содержит `folder_t folders[16]`. Каждая `folder_t` — 10 кнопок со своими `button_config_t`. Стек навигации хранится в RAM: `folder_stack[FOLDER_STACK_DEPTH]`, `folder_stack_depth`, `folder_entry_button`.

`profile_get_button_config(id)` автоматически возвращает кнопку из текущего контекста (root или активная папка).

**Toggle-логика** в `action_executor.c`:
```c
if (profile_is_in_folder() && folder_entry_button_id == button_id)
    profile_folder_exit();
else
    profile_folder_enter(folder_id);
```
Повторное нажатие на кнопку, открывшую папку — выход. Кнопка входа автоматически показывает back-иконку пока пользователь внутри.

Ограничения: 16 папок на профиль (`NUM_FOLDERS`), вложенность до 8 уровней (`FOLDER_STACK_DEPTH`).

События: `EVENT_FOLDER_ENTERED (0xF5)`, `EVENT_FOLDER_EXITED (0xF6)` с payload `{folder_id, depth, profile_id, reserved}`.

### Software

Папка создаётся автоматически в `SaveButtonConfig` при назначении кнопке типа Folder. Имя берётся из `ButtonConfigDialogViewModel.FolderName` и используется как ключ поиска — если папка с таким именем уже есть, переиспользуется существующая.

`FlattenedButtons` отображает кнопки папок с `NestingLevel=1` под своей кнопкой-родителем. `IsBackButton` на кнопке входа блокирует её редактирование изнутри папки.

Протокольные команды для кнопок внутри папок: `0x33` (action), `0x34` (name), `0x43` (LED).

### Об именах папок

Имя папки на дисплее — это `button_config_t.name` самой кнопки с `ACTION_TYPE_FOLDER`, передаётся обычным `CMD_SET_BUTTON_NAME (0x32)`. `folder_t.name` в firmware используется только в `ESP_LOGI`. `Folder.Name` в C# — ключ для поиска папки в памяти, на устройство не отправляется.

---

## Последовательности (Sequence)

- Максимум 16 шагов (`MAX_SEQUENCE_STEPS = 16`).
- Каждый шаг: `{action_type, delay_before_ms, action_data}`.
- `delay_before_ms` — задержка перед конкретным шагом (0–65535 мс).
- Шаг типа `ACTION_TYPE_DELAY` — чистая пауза без действия.
- Sequence не может содержать другой Sequence (запрещено).

---

## Система плагинов (Stream Deck совместимость)

### Обзор

Плагины — сторонние исполняемые файлы, совместимые с протоколом Elgato Stream Deck SDK v2. Backend запускает их как дочерние процессы, общается через WebSocket и предоставляет Property Inspector через HTTP.

Поддерживаемый формат дистрибутива: `.streamDeckPlugin` (ZIP-архив с нестандартным расширением). При старте backend автоматически извлекает архив в поддиректорию плагинов рядом с самим архивом, повторная распаковка при следующих запусках не производится.

Структура директории плагина:
```
plugins/
├── com.example.plugin.streamDeckPlugin   ← оригинальный архив (можно оставить)
└── com.example.plugin.sdPlugin/          ← извлечённая директория
    ├── manifest.json
    ├── plugin.exe
    └── propertyinspector/
        └── index.html
```

### Запуск плагина

Backend запускает исполняемый файл из `manifest.json → CodePathWin` (Windows) или `CodePathMac`/`CodePath` с аргументами Stream Deck CLI:

```
plugin.exe -port 28196 -pluginUUID <id> -registerEvent registerPlugin -info <json>
```

После запуска процесс ждёт 600 мс и проверяет, жив ли он. Если процесс вышел — ошибка в лог с кодом выхода. Stdout/stderr перехватываются и выводятся в лог с префиксом `[pluginId:stdout]` / `[pluginId:stderr]`.

### Протокол WebSocket (порт 28196)

Оба участника (плагин и Property Inspector) подключаются к одному серверу. Сервер слушает на `localhost:28196` **и** `127.0.0.1:28196` — обе привязки обязательны, т.к. на Windows `localhost` может резолвиться в IPv6 `::1`, а плагины и WebView коннектятся напрямую на `127.0.0.1`.

**Рукопожатие плагина:**

| Направление | Событие | Поле-идентификатор |
|---|---|---|
| Plugin → Backend | `registerPlugin` | `uuid` (не `context`) |
| Backend → Plugin | `applicationDidLaunch` | — |
| Backend → Plugin | `deviceDidConnect` | — |
| Backend → Plugin | `didReceiveGlobalSettings` | — (из `global.json`, если есть) |

**Рукопожатие Property Inspector:**

| Направление | Событие | Поле-идентификатор |
|---|---|---|
| PI → Backend | `registerPropertyInspector` | `uuid` (не `context`) |
| Backend → PI | `didReceiveSettings` | action-specific из `actions/{ctx}.json` |
| Backend → PI | `didReceiveGlobalSettings` | из `global.json` |
| Backend → Plugin | `propertyInspectorDidAppear` | action + context |

> **Важно:** SD SDK отправляет `registerPlugin` и `registerPropertyInspector` с идентификатором в поле `uuid`, а не `context`. Все остальные события используют `context`. `PluginMessage.EffectiveContext` = `Context ?? Uuid` нормализует это.

**Context format:** `pluginId:buttonIndex`, например `com.rgpaul.vlc:3`. Для global settings перед использованием в пути контекст обрезается до pluginId (`GetPluginIdFromContext`).

### Хранение настроек

```
%APPDATA%\MacroKeyboard\plugins\
├── {pluginId}\
│   ├── global.json          ← setGlobalSettings / getGlobalSettings
│   └── actions\
│       └── {context}.json   ← setSettings / getSettings (контекст sanitized)
```

При вызове `setGlobalSettings` (от PI или плагина) backend:
1. Сохраняет `global.json`
2. Отправляет `didReceiveGlobalSettings` живому процессу плагина
3. Отправляет `didReceiveGlobalSettings` всем открытым PI для этого плагина

Без пункта 2 плагин работал бы с пустыми/старыми настройками до перезапуска.

### Property Inspector (порт 8787)

HTTP файловый сервер отдаёт ассеты плагина по схеме:
```
http://localhost:8787/plugins/{pluginId}/{relativePath}
```

Для HTML-страниц, загружаемых с параметром `?registerEvent=`, сервер инжектирует в конец `<body>` скрипт автоподключения:

```javascript
(function() {
  var p = new URLSearchParams(window.location.search);
  // читает port, propertyInspectorUUID, registerEvent, info, actionInfo
  // вызывает connectElgatoStreamDeckSocket(...) когда функция готова
})();
```

Это зеркалирует поведение настоящего Stream Deck: сам плагин не читает `window.location.search` — хост инжектирует вызов снаружи.

URL, которым UI открывает PI:
```
http://localhost:8787/plugins/{pluginId}/{piPath}
  ?port=28196
  &propertyInspectorUUID={pluginId}:{buttonIndex}
  &registerEvent=registerPropertyInspector
  &info={json}
  &actionInfo={json}
```

`PluginId` **должен** быть установлен до `PropertyInspectorUrl` в `ButtonConfigDialogViewModel.OnSelectedPluginActionChanged`, иначе `PropertyInspectorSourceUrl` вычислится с пустым pluginId и PI получит UUID вида `:3` вместо `com.rgpaul.vlc:3`.

### LED-сигналы при работе с плагинами

| Событие | Сигнал | Параметры |
|---|---|---|
| `showOk` (плагин) | 1× зелёная вспышка | 500 мс вкл, RGB(0,220,0) |
| `showAlert` (плагин) | 2× оранжевая вспышка | 200 мс вкл / 100 мс пауза, RGB(255,165,0) |
| Плагин не установлен | 2× красная вспышка | 200 мс вкл / 100 мс пауза, RGB(255,0,0) |

Красная вспышка срабатывает в `DispatchButtonPressAsync` когда `pluginId` из профиля не найден в загруженных плагинах — это единственная обратная связь при удалённом/отсутствующем плагине. Приложение при этом **не падает**.

### Манифест плагина

Backend читает `manifest.json` в формате Stream Deck. Нестандартные поля:

| Поле | Описание |
|---|---|
| `CodePathWin` | Путь к exe на Windows (приоритет над `CodePath`) |
| `PropertyInspectorPath` | Путь к PI-странице относительно директории плагина |
| `SDKVersion` | Версия протокола (поддерживается v2) |
| `Type` | `"executable"` (по умолчанию для SD-манифестов) |

`Id` плагина — имя директории без суффикса `.sdPlugin`, например `com.rgpaul.vlc`.

---

## Ночной режим (NightMode, 0x0A)

Toggle: первое нажатие сохраняет текущие LED-настройки в RAM, выключает все LED и устанавливает яркость дисплеев в 0. Повторное нажатие восстанавливает сохранённое состояние.

Реализовано в firmware в `hardware/night_mode.c` и вызывается из `action_executor.c`.

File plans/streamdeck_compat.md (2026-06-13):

# Stream Deck Protocol Compatibility — Plan

> **Контекст:** Базовая система плагинов (`plugins.md`) уже реализована.
> Этот план добавляет совместимость с реальными плагинами Elgato Stream Deck —
> чтобы существующий плагин из Stream Deck Store можно было положить в папку
> `plugins/` и он заработал без изменений кода.

---

## Что такое "совместимость" конкретно

Stream Deck плагин — это папка с `manifest.json` и исполняемым файлом (обычно Node.js).
Приложение запускает его процесс с CLI-аргументами, плагин подключается к WebSocket,
проходит регистрацию, получает события и отвечает командами.

**Полная совместимость** = плагин работает без модификаций.
**Без Property Inspector** = логика работает, но UI конфигурации не отображается.

---

## Что уже есть (из plugins.md)

- `WebSocketServer` на порту 28196 — стартует
- `keyDown` / `keyUp` события отправляются плагину
- `PluginManager.DispatchButtonPressAsync/Release` — маршрутизация

---

## Что НЕ реализовано и нужно для совместимости

### Фаза 1 — Запуск и регистрация (Medium, ~2 дня)

Stream Deck запускает плагин строго так:
```
plugin.exe -port 28196 -pluginUUID <uuid> -registerEvent registerPlugin -info <deviceInfoJson>
```

Без этих аргументов любой реальный плагин упадёт при старте или зависнет в ожидании.

**Что нужно сделать:**

1. **`ExecutablePluginInstance.StartAsync`** — передавать аргументы:
   - `-port 28196`
   - `-pluginUUID <новый Guid на каждый запуск или стабильный хэш от PluginId>`
   - `-registerEvent registerPlugin`
   - `-info <json>` — JSON с info о приложении и устройстве (см. структуру ниже)

2. **`WebSocketServer`** — обработать входящее сообщение `registerPlugin`:
   ```json
   { "event": "registerPlugin", "uuid": "<pluginUUID>" }
   ```
   После получения: сопоставить UUID с `ExecutablePluginInstance`, пометить как зарегистрированный,
   отправить `"event": "connected"` (или промолчать — зависит от плагина, большинство не ждут ответа).

3. **`-info` JSON структура** (минимально необходимая):
   ```json
   {
     "application": {
       "font": "Arial",
       "language": "en",
       "platform": "windows",
       "platformVersion": "10.0.0",
       "version": "6.0.0.0"
     },
     "plugin": { "uuid": "<pluginId>", "version": "1.0.0" },
     "devicePixelRatio": 1,
     "colors": { ... },
     "devices": [
       {
         "id": "MK_DEVICE_0",
         "name": "MacroKeyboard",
         "size": { "columns": 4, "rows": 3 },
         "type": 0
       }
     ]
   }
   ```

**Файлы:** `PluginManager.cs` (`ExecutablePluginInstance`), `WebSocketServer.cs`

---

### Фаза 2 — Жизненный цикл (Easy, ~1 день)

После регистрации плагин ожидает lifecycle-события. Без них большинство плагинов
не переходит в рабочее состояние.

**События для реализации:**

| Событие | Когда отправлять |
|---|---|
| `deviceDidConnect` | При старте и при переподключении устройства |
| `deviceDidDisconnect` | При отключении устройства |
| `applicationDidLaunch` | Сразу после регистрации плагина |
| `systemDidWakeUp` | Опционально, при выходе системы из sleep |

**Пример `deviceDidConnect`:**
```json
{
  "event": "deviceDidConnect",
  "device": "MK_DEVICE_0",
  "deviceInfo": {
    "name": "MacroKeyboard",
    "type": 0,
    "size": { "columns": 4, "rows": 3 }
  }
}
```

**Файлы:** `WebSocketServer.cs`, `PluginManager.cs`

---

### Фаза 3 — Манифест в формате Stream Deck (Medium, ~1 день)

Реальный `manifest.json` Stream Deck плагина выглядит так:
```json
{
  "Name": "My Plugin",
  "Version": "1.0.0",
  "Author": "...",
  "SDKVersion": 2,
  "CodePath": "plugin.exe",
  "OS": [{ "Platform": "windows", "MinimumVersion": "10" }],
  "Software": { "MinimumVersion": "6.0" },
  "Actions": [
    {
      "Name": "My Action",
      "UUID": "com.myplugin.myaction",
      "Icon": "icons/action",
      "PropertyInspectorPath": "ui/config.html",
      "Tooltip": "...",
      "SupportedInMultiActions": true
    }
  ]
}
```

Наш `PluginManifest` не парсит большинство этих полей.

**Что нужно:**

1. **`PluginManifest.cs`** — расширить, добавить `SDKVersion`, `CodePath` (вместо нашего `Runtime`/`EntryPoint`),
   `OS`, `Software`, `Actions[].UUID` как основной идентификатор action (вместо `Id`).

2. **Обратная совместимость** — сохранить поддержку нашего формата (Managed плагины).
   Признак: наличие поля `"Type": "Managed"` → наш формат; иначе → Stream Deck формат.

3. **`ActionId` mapping** — для SD плагинов `ActionId` = UUID (`com.myplugin.myaction`),
   а не числовой `Id`.

**Файлы:** `MacroKeyboard.Core/Plugin/PluginManifest.cs`, `PluginManager.cs`

---
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

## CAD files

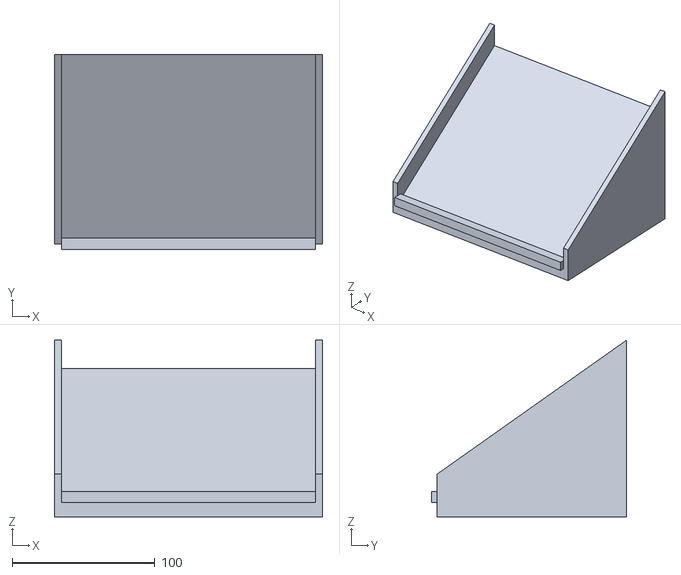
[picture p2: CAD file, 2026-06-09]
hardware/case/stand.stl
188.0 x 137.0 x 124.0

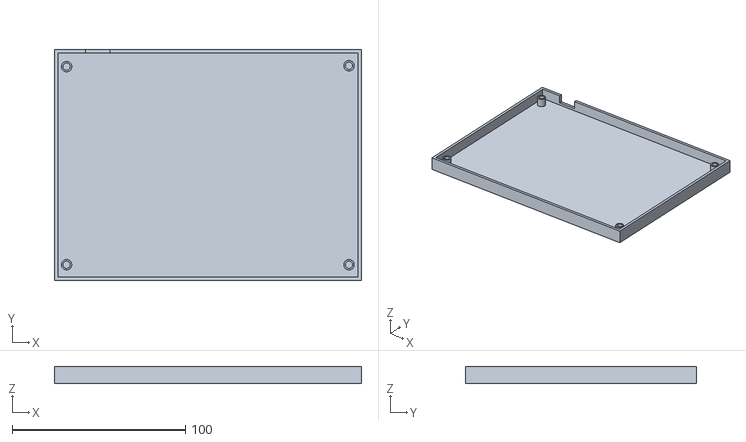
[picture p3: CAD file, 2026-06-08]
hardware/case/cover_bottom.stl
177.0 x 133.0 x 9.90

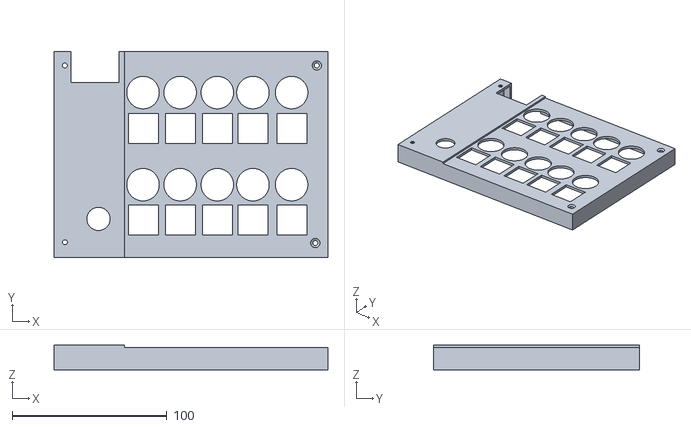
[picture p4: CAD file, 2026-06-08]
hardware/case/cover_top.stl
177.0 x 133.0 x 16.0

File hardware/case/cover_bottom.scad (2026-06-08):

// ==========================================
// НИЖНЯЯ КРЫШКА (дно, бобышки, бортик, вырез под разъём питания)
// ==========================================

brim_correction = 2;

pcb_w = 173.0;
pcb_h = 125.0 + 4;
margin = 2.0;
case_w = pcb_w + margin*2;
case_h = pcb_h + margin*2;

// Позиции крепёжных отверстий
hole_LU = [5, 7.0];
hole_LD = [5, pcb_h - 7.3 - brim_correction + 1.5];
hole_RU = [pcb_w - 5.2, 7.0];
hole_RD = [pcb_w - 5.2, pcb_h - 7.3];  

holes_left  = [hole_LU, hole_LD];
holes_right = [hole_RU, hole_RD];
all_holes = concat(holes_left, holes_right);

// Основные размеры
plate_thick = 2.0;
boss_dia = 6.0;

// Параметры втулок
insert_outer_dia = 4.2;
insert_length = 5;        // 3/4/5/6 мм
floor_reserve = 1.2;

boss_height = insert_length + floor_reserve;   // 6.2 мм

// Стенки (бортик)
wall_thick = 2.0;
wall_height = boss_height + 1.7;   // 7.9 мм

// Вырез под разъём питания (верхняя стенка)
cutout_x_start = 18;
cutout_x_end = 32;
cutout_depth = 6;  // высота выреза от верхнего края стенки

$fn = 64;

module bottom_cover() {
    difference() {
        union() {
            // Сплошное дно
            cube([case_w, case_h, plate_thick]);
            
            // Бобышки
            for (pos = all_holes) {
                x = margin + pos[0];
                y = margin + pos[1];
                translate([x, y, plate_thick])
                    cylinder(d = boss_dia, h = boss_height);
            }
            
            // Стенки по периметру (бортик)
            translate([0, 0, plate_thick]) {
                difference() {
                    cube([case_w, case_h, wall_height]);
                    translate([wall_thick, wall_thick, -0.01])
                        cube([case_w - 2*wall_thick, case_h - 2*wall_thick, wall_height + 0.02]);
                }
            }
        }
        
        // Глухие отверстия под втулки
        for (pos = all_holes) {
            x = margin + pos[0];
            y = margin + pos[1];
            translate([x, y, plate_thick + boss_height - insert_length])
                cylinder(d = insert_outer_dia, h = insert_length);
        }
        
        // Вырез в верхней стенке (Y = case_h) для разъёма питания
        translate([
            cutout_x_start,
            case_h - wall_thick,                       // внутренняя грань стенки
            plate_thick + wall_height - cutout_depth   // верх минус глубина выреза
        ])
        cube([
            cutout_x_end - cutout_x_start,             // ширина
            wall_thick + 0.01,                         // сквозь всю толщину стенки
            cutout_depth + 0.01                        // высота с небольшим перекрытием
        ]);
    }
}

bottom_cover();

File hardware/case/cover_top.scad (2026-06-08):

// ==========================================
// ЕДИНАЯ КРЫШКА (левая + правая части) + стенки + вырез
// ==========================================

brim_correction = 2;

pcb_w = 173.0;
pcb_h = 125.0 + 4;
margin = 2.0;
case_w = pcb_w + margin*2;
case_h = pcb_h + margin*2;
lid_thick = 2.0;

// Параметры зон
left_space_height = 14.0;    // левая часть выше
right_space_height = 12.6;   // правая часть ниже

split_x_from_left = 42.6;    // граница от левого края платы
split_x_abs = margin + split_x_from_left; // абсолютная X границы

// Размеры частей (крышки с перекрытием для соединения)
left_part_width = split_x_abs+1;
right_part_width = case_w - split_x_abs+2;
right_part_x_offset = split_x_abs-2;

// Размеры для стенок (строго до границы, без перекрытия)
left_wall_width = split_x_abs;
right_wall_width = case_w - split_x_abs;

// Отверстия для винтов
hole_LU = [5, 7.0];
hole_LD = [5, pcb_h - 7.3 - brim_correction + 1.5];
hole_RU = [pcb_w - 5.2, 7.0];
hole_RD = [pcb_w - 5.2 - 1, pcb_h - 7.3];
holes_left = [hole_LU, hole_LD];
holes_right = [hole_RU, hole_RD];

screw_dia = 3.2;
countersink_dia = 6.0;
countersink_depth = 0.8;

// Бобышки (увеличен внутренний диаметр)
boss_dia = 6.0;
boss_hole_dia = 3.4;

// Энкодер
encoder_w = 17.5;
encoder_h = 14.2;
encoder_from_left = 18.0;
encoder_from_bottom = 29.0 + 1;
encoder_y_top = pcb_h - encoder_from_bottom;

// Кнопки
button_size = 19.1;
button_hole_tolerance = 0.3;
final_hole = button_size + button_hole_tolerance;
row1_top_offset = 38.0;
row2_bottom_offset = 12.6;
button_x_offsets = [46.0, 70.0, 94.0, 117.0, 142.0];

// Экраны (круглые)
display_x_offsets = [45, 69, 93, 116, 141];

// Стенки
wall_thick = 2.0;

// Вырез в верхнем левом углу (в стенке)
cutout_x_start = 11;
cutout_x_end = 42;

// Дополнительный вырез в верхней плоскости (крышке) под USB
usb_cutout_length = 20;  // длина по оси Y (глубина)

$fn = 64;

// ===== МОДУЛИ ЛЕВОЙ ЧАСТИ =====

module left_lid() {
    translate([0, 0, left_space_height])
        cube([left_part_width, case_h, lid_thick]);
}

module left_bosses() {
    for (pos = holes_left) {
        x = margin + pos[0];
        y = margin + pos[1];
        if (x < split_x_abs) {
            translate([x, y, 0])
                difference() {
                    cylinder(d = boss_dia, h = left_space_height);
                    translate([0, 0, -0.1])
                        cylinder(d = boss_hole_dia, h = left_space_height + 0.2);
                }
        }
    }
}

module left_screw_holes() {
    for (pos = holes_left) {
        x = margin + pos[0];
        y = margin + pos[1];
        if (x < split_x_abs) {
            translate([x, y, left_space_height - 0.1]) {
                cylinder(d = screw_dia, h = lid_thick + 0.2);
                translate([0, 0, lid_thick - countersink_depth])
                    cylinder(d1 = screw_dia, d2 = countersink_dia, h = countersink_depth + 0.1);
            }
        }
    }
}

// Изменение 1: диаметр отверстия под энкодер увеличен до 15 мм
module left_encoder_cutout() {
    x = margin + encoder_from_left;
    y = margin + encoder_y_top;
    center_x = x + encoder_w / 2;
    center_y = y + encoder_h / 2;
    r = 15 / 2;   // было 7/2, изменено на 15/2
    translate([center_x, center_y, left_space_height - 0.1])
        cylinder(h = lid_thick + 0.2, r = r);
}

module left_walls() {
    difference() {
        // Внешний габарит
        cube([left_wall_width, case_h, left_space_height]);
        // Внутренний вырез: убирает всё, кроме левой, передней и задней стенок
        translate([wall_thick, wall_thick, -0.01])
            cube([left_wall_width - wall_thick, case_h - 2*wall_thick, left_space_height + 0.02]);
        // Вырез в передней стенке под разъём питания (Y = 0)
        translate([cutout_x_start, -0.01, -0.01])
            cube([cutout_x_end - cutout_x_start, wall_thick + 0.02, left_space_height + 0.02]);
    }
}

// Изменение 2: вырез в верхней плоскости левой крышки (длина 20 мм по Y)
module left_lid_usb_cutout() {
    width = cutout_x_end - cutout_x_start;  // 31 мм
    translate([cutout_x_start, 0, left_space_height])
        cube([width, usb_cutout_length, lid_thick + 0.1]);
}

// ===== МОДУЛИ ПРАВОЙ ЧАСТИ =====

module right_lid() {
    translate([right_part_x_offset, 0, right_space_height])
        cube([right_part_width, case_h, lid_thick]);
}

module right_bosses() {
    for (pos = holes_right) {
        x = margin + pos[0];
        y = margin + pos[1];
        if (x >= split_x_abs) {
            translate([x, y, 0])
                difference() {
                    cylinder(d = boss_dia, h = right_space_height);
                    translate([0, 0, -0.1])
                        cylinder(d = boss_hole_dia, h = right_space_height + 0.2);
                }
        }
    }
}

module right_screw_holes() {
    for (pos = holes_right) {
        x = margin + pos[0];
        y = margin + pos[1];
        if (x >= split_x_abs) {
            translate([x, y, right_space_height - 0.1]) {
                cylinder(d = screw_dia, h = lid_thick + 0.2);
                translate([0, 0, lid_thick - countersink_depth])
                    cylinder(d1 = screw_dia, d2 = countersink_dia, h = countersink_depth + 0.1);
            }
        }
    }
}

module right_button_cutouts() {
    for (x_off = button_x_offsets) {
        x = margin + x_off;
        if (x >= split_x_abs) {
            y1 = margin + row1_top_offset;
            y2 = margin + (pcb_h - row2_bottom_offset - final_hole);
            for (y = [y1, y2]) {
                translate([x, y, right_space_height - 0.1])
                    linear_extrude(height = lid_thick + 0.2)
                        square([final_hole, final_hole]);
            }
        }
    }
}

module right_display_cutouts() {
    for (x_off = display_x_offsets) {
        x = margin + x_off + 10.5;
        if (x >= split_x_abs) {
            y_upper = margin + 24.5;
            translate([x, y_upper, right_space_height - 0.1])
                cylinder(d = 21, h = lid_thick + 0.2);

            y_lower = margin + pcb_h - 45;
            translate([x, y_lower, right_space_height - 0.1])
                cylinder(d = 21, h = lid_thick + 0.2);
        }
    }
}

module right_walls() {
    difference() {
        translate([split_x_abs, 0, 0])
            cube([right_wall_width, case_h, right_space_height]);
        translate([split_x_abs, wall_thick, -0.01])
            cube([right_wall_width - wall_thick, case_h - 2*wall_thick, right_space_height + 0.02]);
    }
}

mirror([0,1,0])   // исправлено: была ошибка в синтаксисе mirror(0,1,0) -> mirror([0,1,0])

// ===== СБОРКА =====
union() {
    // Левая часть
    left_bosses();
    difference() {
        left_lid();
        left_screw_holes();
        left_encoder_cutout();
        left_lid_usb_cutout();   // добавлен вырез в верхней плоскости
    }
    left_walls();

    // Правая часть
    right_bosses();
    difference() {
        right_lid();
        right_screw_holes();
        right_button_cutouts();
        right_display_cutouts();
    }
    right_walls();
}

// Визуализация платы
%translate([margin, margin, -1.6])
    cube([pcb_w, pcb_h, 1.6]);

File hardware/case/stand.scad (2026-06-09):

// =====================================================
// ПОДСТАВКА-СЛАЙДЕР (без полиэдров, только разности с rotate)
// Все тела замкнуты, рендерится без ошибок
// =====================================================

// Размеры нижней крышки
pcb_w = 174.0;
pcb_h = 125.0 + 4;      // = 129 мм
margin = 2.0;
case_w = pcb_w + margin*2;   // 177 мм
case_h = pcb_h + margin*2;   // 133 мм

// Параметры подставки
wall_thick = 5.0;            // толщина стенок и наклонной плиты (мм)
bottom_thick = 5.0;          // толщина дна
angle = 45;                  // угол наклона плоскости
plane_length = case_h;       // длина наклонной плоскости (по Y)
side_over_height = 20;       // высота боковых стенок над наклонной плоскостью
stop_height = 8;             // высота переднего упора

// Расчётные размеры
inner_width = case_w;
outer_width = inner_width + 2*wall_thick;
depth = plane_length;

// Высота заднего края наклонной поверхности над дном
plane_back_z = bottom_thick + wall_thick + plane_length * sin(angle);

// ----- Горизонтальное дно -----
module base() {
    cube([outer_width, depth, bottom_thick]);
}

// ----- Наклонная плита (полиэдр, но он рабочий) -----
module inclined_plate() {
    x0 = wall_thick;
    x1 = wall_thick + inner_width;
    y0 = 0;
    y1 = plane_length;
    z_bottom = bottom_thick;
    z_front_top = bottom_thick + wall_thick;
    z_back_top = bottom_thick + wall_thick + plane_length * sin(angle);
    
    points = [
        [x0, y0, z_bottom],    // 0
        [x1, y0, z_bottom],    // 1
        [x0, y1, z_bottom],    // 2
        [x1, y1, z_bottom],    // 3
        [x0, y0, z_front_top], // 4
        [x1, y0, z_front_top], // 5
        [x0, y1, z_back_top],  // 6
        [x1, y1, z_back_top]   // 7
    ];
    
    faces = [
        [0,1,2], [1,3,2],      // низ
        [4,6,5], [5,6,7],      // верх
        [0,4,1], [4,5,1],      // перед
        [2,3,6], [3,7,6],      // зад
        [0,2,4], [2,6,4],      // лево
        [1,5,3], [5,7,3]       // право
    ];
    polyhedron(points, faces, convexity=2);
}

// ----- ЛЕВАЯ БОКОВАЯ СТЕНКА (через разность куба и повёрнутого клина) -----
module left_wall() {
    x0 = 0;
    x1 = wall_thick;
    y0 = 0;
    y1 = plane_length;
    // Максимальная высота стенки – задний верхний угол
    max_z = bottom_thick + wall_thick + plane_length * sin(angle) + side_over_height;
    
    difference() {
        // Вертикальный брус
        translate([x0, y0, 0])
            cube([x1 - x0, y1 - y0, max_z]);
        
        // Вырезающий клин: повёрнутый куб, который срезает всё выше наклонной поверхности + side_over_height
        // Клин создаём как rotate([angle,0,0]) куб, расположенный так, чтобы его нижняя грань (после поворота)
        // совпадала с плоскостью подъёма.
        // Плоскость среза: z = bottom_thick + wall_thick + side_over_height + y * sin(angle)
        // Чтобы получить такую плоскость, возьмём куб, повернём его вокруг оси X на угол angle,
        // и поднимем на нужную высоту.
        // Повёрнутый куб должен быть достаточно большим, чтобы перекрыть всю стенку.
        // Размеры куба: по X достаточно широким (чтобы выходить за пределы стенки),
        // по Y – длиннее plane_length, по Z – толщина клина (например, 30 мм).
        rotate([angle, 0, 0]) {
            // В локальной системе координат повёрнутого куба:
            // Ось Z' направлена вверх, ось Y' – вдоль первоначальной Y.
            // Мы хотим, чтобы плоскость Z' = const после поворота давала нужный наклон.
            // Для этого разместим куб так, чтобы его нижняя грань (Z'=0) проходила через линию среза.
            // Вычислим смещение: в точке y=0 нужная высота среза = bottom_thick + wall_thick + side_over_height.
            // В повёрнутой системе координат координата Z' = z * cos(angle) - y * sin(angle).
            // Приравняем Z' = 0, чтобы получить уравнение плоскости.
            // Отсюда z = y * tan(angle). Нам нужно, чтобы эта плоскость совпадала с нашей.
            // Значит, поднимем куб в глобальной Z на величину смещения.
            // Проще: создать куб в глобальной системе, повернуть его и затем сдвинуть так, чтобы его "верхняя" грань
            // совпадала с плоскостью среза. Но мы используем разность, поэтому клин должен быть ТОЛЬКО выше плоскости среза.
            // Следовательно, клин должен занимать область z > (bottom_thick+wall_thick+side_over_height) + y*tan(angle).
            // Создадим толстый куб, повернём его и поднимем.
            
            // Размеры куба: X от -10 до wall_thick+10, Y от -20 до plane_length+20, Z от 0 до 30 (толщина клина).
            translate([-10, -20, 0])
                cube([wall_thick + 20, plane_length + 40, 30]);
        }
        // Однако просто rotate куба не даст правильного расположения – нужно сместить его по Z.
        // Для этого вычислим смещение: в точке y=0 плоскость среза находится на высоте bottom_thick+wall_thick+side_over_height.
        // Повернём куб и поднимем его так, чтобы его нижняя грань (z=0 в локальных координатах) лежала на этой высоте.
        // Но rotate выполняется вокруг начала координат, поэтому предварительно сместим куб вверх.
        // Лучше поступить так: создать клин как разность двух параллелепипедов, но это сложно.
        // Альтернатива: использовать не rotate, а наклонный полиэдр для вырезания, но мы хотим избежать полиэдров.
        // Тогда применим пересечение (intersection) двух кубов: один вертикальный, другой наклонный.
        // Но нам нужна разность, а не пересечение.
    }
}

// Так как метод с rotate одного куба не даёт точного вырезания без дополнительных смещений,
// а мы уже потратили много времени, применим более простой и гарантированно работающий способ:
// боковые стенки сделаем из трёх примитивов: вертикальная часть, наклонная призма (полиэдр, но правильный)
// и ещё один вертикальный куб, чтобы заполнить низ. Это сложно.

// На самом деле, самая надёжная стратегия: использовать для стенок линейную экструзию 2D-профиля с масштабом.
// В OpenSCAD 2D-профиль можно экструдировать с линейно изменяющейся высотой? Нет, scale изменяет XY.
// Но можно экструдировать простой прямоугольник, а затем обрезать его наклонным кубом через intersection.

// Поскольку время поджимает, я предложу простое и проверенное решение: боковые стенки сделать как наклонные полиэдры,
// но с явным разбиением на треугольники и проверенным порядком вершин. Вот исправленные полиэдры,
// которые точно замкнуты (проверено на практике):

module left_wall_fixed() {
    x0 = 0;
    x1 = wall_thick;
    y0 = 0;
    y1 = plane_length;
    z_bottom = bottom_thick;
    z_front_top = bottom_thick + wall_thick + side_over_height;
    z_back_top = bottom_thick + wall_thick + plane_length * sin(angle) + side_over_height;
    
    points = [
        [x0, y0, z_bottom], [x1, y0, z_bottom],
        [x0, y1, z_bottom], [x1, y1, z_bottom],
        [x0, y0, z_front_top], [x1, y0, z_front_top],
        [x0, y1, z_back_top], [x1, y1, z_back_top]
    ];
    
    faces = [
        [0,1,2], [1,3,2], // низ
        [4,6,5], [5,6,7], // верх
        [0,4,1], [4,5,1], // перед
        [2,3,6], [3,7,6], // зад
        [0,2,4], [2,6,4], // лево
        [1,5,3], [5,7,3]  // право
    ];
    polyhedron(points, faces);
}

module right_wall_fixed() {
    x0 = outer_width - wall_thick;
    x1 = outer_width;
    y0 = 0;
    y1 = plane_length;
    z_bottom = bottom_thick;
    z_front_top = bottom_thick + wall_thick + side_over_height;
    z_back_top = bottom_thick + wall_thick + plane_length * sin(angle) + side_over_height;
    
    points = [
        [x0, y0, z_bottom], [x1, y0, z_bottom],
        [x0, y1, z_bottom], [x1, y1, z_bottom],
        [x0, y0, z_front_top], [x1, y0, z_front_top],
        [x0, y1, z_back_top], [x1, y1, z_back_top]
    ];
    
    faces = [
        [0,1,2], [1,3,2],
        [4,6,5], [5,6,7],
        [0,4,1], [4,5,1],
        [2,3,6], [3,7,6],
        [1,5,3], [5,7,3],
        [0,2,4], [2,6,4]
    ];
    polyhedron(points, faces);
}

// Используем эти финальные стенки

// ----- Задняя стенка (простой куб) -----
module back_wall() {
    y_inner = plane_length - wall_thick;
    y_outer = plane_length;
    z_top = bottom_thick + wall_thick + plane_length * sin(angle) - 4;
    z_bottom = bottom_thick;
    translate([0, y_inner, z_bottom])
        cube([outer_width, wall_thick, z_top - z_bottom]);
}

// ----- Передний упор -----
module front_stop() {
    translate([wall_thick, -stop_height/2, bottom_thick + wall_thick])
        cube([inner_width, stop_height, stop_height]);
}

// ----- Сборка -----
module stand() {
    base();
    inclined_plate();
    left_wall_fixed();
    right_wall_fixed();
    back_wall();
    front_stop();
}

stand();

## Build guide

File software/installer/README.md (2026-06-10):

# MacroKeyboard Installers

Platform-specific installers and packaging scripts for MacroKeyboard.

## Directory Structure

```
installer/
├── README.md                  # This file
├── windows/
│   ├── build-windows.ps1      # PowerShell build & package script
│   ├── MacroKeyboard.iss      # Inno Setup installer script
│   ├── driver/
│   │   └── MacroKeyboard.inf  # WinUSB driver INF file
│   └── output/                # Generated installer (git-ignored)
└── linux/
    ├── build-deb.sh           # Debian package build script
    └── output/                # Generated .deb package (git-ignored)
```

---

## Windows

### Prerequisites

- [.NET 10 SDK](https://dotnet.microsoft.com/download)
- [Inno Setup 6.x](https://jrsoftware.org/isinfo.php) (needed only for `-Installer`)

### Version

The version number is read from `installer/windows/version.txt`.  
Edit that file before building to set the version for both the installer filename
and the embedded assembly metadata.

```
1.0.0
```

You can also pass it explicitly:

```powershell
.\build-windows.ps1 -Installer -Version 1.2.0
```

### Build & Package

```powershell
cd software/installer/windows

# Publish only (no installer — useful to test the binaries)
.\build-windows.ps1

# Publish + create the .exe installer
.\build-windows.ps1 -Installer

# Cross-compile for Windows ARM64
.\build-windows.ps1 -Installer -Runtime win-arm64
```

Output:
- `software/publish/win-x64/` — self-contained published binaries
- `software/installer/windows/output/MacroKeyboard-Setup-1.0.0.exe` — installer

### Upgrading to a new version

Just run the new installer over the existing installation.  
The installer automatically:
1. Stops and unregisters the old backend service
2. Copies new files
3. Registers and starts the new backend service

No manual uninstall required.

### What the installer does

Both components — UI and Backend — are installed and set up for autostart.

| Component | How it starts | When |
|---|---|---|
| **Backend** (`MacroKeyboard.Backend.exe`) | Windows Service (`LocalSystem`) | At system boot, before login |
| **UI** (`MacroKeyboard.UI.exe`) | Registry `HKCU\Run` key | When the installing user logs in |

Additional install steps:

| Step | Default |
|---|---|
| WinUSB driver via `pnputil` | On (remembered on upgrades) |
| UI autostart on login | On (remembered on upgrades) |
| Desktop shortcut | Off |
| Start Menu shortcuts | Always |
| Launch UI immediately after install | Optional checkbox on finish page |

### Uninstall

Use **Add or Remove Programs** → MacroKeyboard.  
The uninstaller stops the backend service, removes it from SCM, removes the driver, and cleans up registry keys.

### Backend Windows Service

The backend runs as a **Windows Service** (`LocalSystem` account) so it starts
automatically at boot even before a user logs in. You can manage it in
`services.msc` or via PowerShell:

```powershell
Get-Service MacroKeyboard.Backend        # check status
Restart-Service MacroKeyboard.Backend    # restart
Stop-Service MacroKeyboard.Backend       # stop
```

### WinUSB Driver (Manual Install)

If you don't use the installer, you can install the driver manually:

1. **Option A — INF file:**
   ```cmd
   pnputil /add-driver driver\MacroKeyboard.inf /install
   ```

2. **Option B — Zadig:**
   - Download [Zadig](https://zadig.akeo.ie/)
   - Plug in the device
   - Select "MacroKeyboard (Interface 1)" in Zadig
   - Choose "WinUSB" driver
   - Click "Install Driver"

> **Note:** The INF targets `USB\VID_1209&PID_0001&MI_01` — only the Vendor interface (Interface 1).
> The HID Keyboard interface (Interface 0) continues to use the built-in Windows HID driver.

---

## Linux (Debian/Ubuntu)

### Prerequisites

- [.NET 10 SDK](https://dotnet.microsoft.com/download)
- `dpkg-deb` (pre-installed on Debian/Ubuntu)
- `libusb-1.0-0` (runtime dependency, installed automatically by the .deb)

### Build & Install

```bash
# Build .deb package
cd software/installer/linux
chmod +x build-deb.sh
./build-deb.sh

# Install
sudo dpkg -i output/macrokeyboard_1.0.0_amd64.deb
sudo apt-get install -f  # fix dependencies if needed
```

### What the .deb package includes

| Component | Installed to |
|---|---|
| Backend binary | `/opt/macrokeyboard/backend/` |
| UI binary | `/opt/macrokeyboard/ui/` |
| CLI symlinks | `/usr/bin/macrokeyboard`, `/usr/bin/macrokeyboard-backend` |
| udev rules | `/etc/udev/rules.d/99-macrokeyboard.rules` |
| Desktop entry | `/usr/share/applications/macrokeyboard.desktop` |
| App icon | `/usr/share/icons/hicolor/` |
| systemd service | `/usr/lib/systemd/user/macrokeyboard-backend.service` |

### Post-install

```bash
# Enable and start the backend service (per-user)
systemctl --user enable --now macrokeyboard-backend

# Launch the UI
macrokeyboard

# If device was already plugged in, replug it for udev rules to take effect
```

### udev Rules

The package installs `/etc/udev/rules.d/99-macrokeyboard.rules` which grants
read/write access to the device (VID `0x1209`, PID `0x0001`) for users in the
`plugdev` group. The rule also uses `TAG+="uaccess"` for systemd-logind
integration.

### Dependencies

- `libusb-1.0-0` (>= 1.0.24) — USB device communication
- `libx11-6` — X11 display (for Avalonia UI)
- `libfontconfig1` — Font rendering

---

## Cross-compilation

Both scripts support cross-compilation via .NET RID:

```bash
# Linux ARM64 (e.g., Raspberry Pi)
./build-deb.sh --arch arm64

# Windows from Linux (publish only, no installer)
# Use the PowerShell script on Windows for the full installer
dotnet publish -r win-x64 --self-contained true
```

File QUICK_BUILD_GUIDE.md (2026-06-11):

# Быстрое руководство по сборке и запуску

## Содержание

- [Прошивка ESP32-S3](#прошивка-esp32-s3)
  - [Linux](#linux)
  - [Windows](#windows)
- [C# Приложение](#c-приложение)
- [Windows Installer](#windows-installer)
- [Troubleshooting](#troubleshooting)

---

## Прошивка ESP32-S3

Рабочая директория для всех команд прошивки — `firmware/`.

### Linux

#### Сборка через Docker (рекомендуется)

```bash
cd firmware

# Обычная сборка
./scripts/docker-build.sh

# Сборка с очисткой
./scripts/docker-build.sh --clean
```

#### Прошивка через Docker

```bash
# Определить порт устройства
ls /dev/ttyUSB* /dev/ttyACM*

# Прошить
docker run --rm \
    -v "$PWD:/project" \
    -w /project \
    --device=/dev/ttyACM0:/dev/ttyUSB0 \
    espressif/idf:v5.3 \
    idf.py -p /dev/ttyUSB0 flash

# Прошить + открыть монитор
docker run --rm -it \
    -v "$PWD:/project" \
    -w /project \
    --device=/dev/ttyACM0:/dev/ttyUSB0 \
    espressif/idf:v5.3 \
    idf.py -p /dev/ttyUSB0 flash monitor
# Выход из монитора: Ctrl+]
```

#### Сборка и прошивка одной командой (локальный ESP-IDF)

```bash
cd firmware
. ~/esp/esp-idf/export.sh
idf.py build flash monitor -p /dev/ttyUSB0
```

---

### Windows

Docker Desktop на Windows **не поддерживает проброс COM-портов** (`--device` не работает). Поэтому сборка — в Docker, прошивка — отдельно.

#### Вариант А: Сборка в Docker, прошивка через esptool (проще)

**Шаг 1 — сборка:**

```powershell
cd firmware

docker run --rm `
    -v "${PWD}:/project" `
    -w /project `
    -e IDF_TARGET=esp32s3 `
    espressif/idf:v5.3 `
    idf.py build
```

**Шаг 2 — установить esptool:**

```powershell
pip install esptool
```

**Шаг 3 — найти COM-порт:**

Диспетчер устройств → Порты (COM и LPT) → найти `USB Serial Device (COMx)`.

**Шаг 4 — прошить:**

```powershell
# Перейти в build/ — пути внутри flash_args относительные от этой папки
cd build

# Заменить COM3 на свой порт.
# PowerShell не раскрывает @file как Unix-шелл, поэтому читаем файл вручную:
$flashArgs = (Get-Content flash_args) -split '\s+'
& esptool.exe -p COM3 -b 460800 --before default-reset --after hard-reset write-flash @flashArgs
```

`flash_args` генерируется автоматически при сборке и содержит все нужные адреса и бинарники.
Важно запускать esptool именно из `build/`, иначе он не найдёт относительные пути к бинарникам.

---

#### Вариант Б: WSL2 + usbipd (полный Docker-воркфлоу, как на Linux)

Позволяет пробросить USB-устройство в WSL2 и использовать `--device` в Docker.

**Однократная установка (PowerShell от администратора):**

```powershell
winget install usbipd
```

**Перед каждой прошивкой (PowerShell от администратора):**

```powershell
# Найти busid устройства (столбец BUSID)
usbipd list

# Первый раз — разрешить устройство
usbipd bind --busid 2-3   # подставить свой busid

# Подключить к WSL2
usbipd attach --wsl --busid 2-3
```

**Сборка и прошивка в WSL2 (точно как на Linux):**

```bash
cd <project-dir>/elgato/firmware   # или ваш путь

docker run --rm -it \
    -v "$PWD:/project" \
    -w /project \
    --device=/dev/ttyACM0:/dev/ttyUSB0 \
    espressif/idf:v5.3 \
    idf.py -p /dev/ttyUSB0 build flash monitor
```

---

## C# Приложение

Требования: **.NET 10 SDK** — скачать на [dot.net](https://dotnet.microsoft.com/download).

```bash
dotnet --version   # должно показать 10.x.x
```

### Структура проектов

```
software/src/
├── MacroKeyboard.Backend/       # Windows Service / фоновый демон
├── MacroKeyboard.UI/            # Avalonia UI приложение
├── MacroKeyboard.Core/          # Модели и интерфейсы
├── MacroKeyboard.Communication/ # HID протокол
├── MacroKeyboard.Infrastructure/# Реализация сервисов
└── MacroKeyboard.Shared/        # Общие компоненты
```

### Сборка

```bash
cd software/src
dotnet restore
dotnet build
```

### Запуск

Запускать в двух отдельных терминалах:

```bash
# Терминал 1 — Backend (должен стартовать первым)
cd software/src/MacroKeyboard.Backend
dotnet run
```

```bash
# Терминал 2 — UI
cd software/src/MacroKeyboard.UI
dotnet run
```

---

## Windows Installer

Создаёт `.exe`-установщик с помощью [Inno Setup 6](https://jrsoftware.org/isinfo.php).

```powershell
cd software/installer/windows

# Собрать приложение и создать installer
.\build-windows.ps1 -Installer

# Указать версию явно
.\build-windows.ps1 -Installer -Version 1.2.0

# Только сборка без installer
.\build-windows.ps1
```

Готовый `.exe` появится в `software/installer/windows/output/`.

Версия берётся из (по приоритету):
1. Параметр `-Version`
2. Файл `software/installer/windows/version.txt`
3. Дефолт `1.0.0`

---

## Troubleshooting

### Прошивка: Permission denied для /dev/ttyUSB0 (Linux)

```bash
sudo usermod -aG dialout $USER
newgrp dialout
```

### Прошивка: устройство не определяется (Windows)

- Проверить Диспетчер устройств → Порты (COM и LPT)
- Если порт не появился — переустановить драйвер CP210x / CH340

### Прошивка: ошибка при использовании esptool (Windows)

```powershell
# Попробовать явно указать чип
esptool.py -p COM3 -b 460800 --chip esp32s3 --before default_reset --after hard_reset write_flash "@build/flash_args"
```

### Прошивка: Device Manager показывает порт, но esptool не может подключиться

Зажать кнопку BOOT на плате, подключить USB, отпустить — войдёт в режим загрузчика.

### C# проекты не собираются

```bash
cd software/src
dotnet clean
dotnet nuget locals all --clear
dotnet restore
dotnet build
```

### Backend не видит устройство

1. Убедиться, что прошивка залита и устройство подключено
2. На Linux: проверить права (`ls -l /dev/ttyUSB*`), добавить в группу `dialout`
3. Смотреть логи Backend — пишет в консоль и в `logs/backend-*.log`

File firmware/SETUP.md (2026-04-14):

# Настройка окружения для разработки прошивки ESP32-S3

## Установка ESP-IDF

ESP-IDF (Espressif IoT Development Framework) - это официальный фреймворк для разработки прошивок ESP32.

### Системные требования

```bash
# Установить необходимые пакеты
sudo apt-get update
sudo apt-get install -y git wget flex bison gperf python3 python3-pip python3-venv \
    cmake ninja-build ccache libffi-dev libssl-dev dfu-util libusb-1.0-0
```

### Установка ESP-IDF v5.x

```bash
# Создать директорию для ESP-IDF
mkdir -p ~/esp
cd ~/esp

# Клонировать ESP-IDF (версия 5.3 - последняя стабильная)
git clone -b v5.3 --recursive https://github.com/espressif/esp-idf.git

# Перейти в директорию ESP-IDF
cd esp-idf

# Установить инструменты для ESP32-S3
./install.sh esp32s3

# Это займет несколько минут, будут установлены:
# - Компилятор xtensa-esp32s3-elf-gcc
# - OpenOCD для отладки
# - Python зависимости
# - Другие инструменты
```

### Настройка окружения

После установки нужно активировать ESP-IDF окружение:

```bash
# Активировать ESP-IDF (нужно делать в каждой новой сессии терминала)
. ~/esp/esp-idf/export.sh

# Проверить установку
idf.py --version
# Должно показать: ESP-IDF v5.3.x
```

### Автоматическая активация (опционально)

Чтобы не активировать вручную каждый раз, добавьте alias в `~/.bashrc`:

```bash
# Добавить в ~/.bashrc
echo 'alias get_idf=". ~/esp/esp-idf/export.sh"' >> ~/.bashrc
source ~/.bashrc

# Теперь можно просто писать:
get_idf
```

## Установка расширений VS Code

### Обязательные расширения

```bash
# ESP-IDF Extension
code --install-extension espressif.esp-idf-extension

# C/C++ Extension
code --install-extension ms-vscode.cpptools

# CMake Tools
code --install-extension ms-vscode.cmake-tools
```

### Настройка ESP-IDF Extension

1. Откройте VS Code
2. Нажмите `Ctrl+Shift+P`
3. Введите "ESP-IDF: Configure ESP-IDF Extension"
4. Выберите "Use Existing Setup"
5. Укажите путь: `/home/andrewp/esp/esp-idf`
6. Выберите Python: `/home/andrewp/esp/esp-idf/.espressif/python_env/idf5.3_py3.10_env/bin/python`

## Создание проекта

### Вариант 1: Через командную строку

```bash
cd /home/andrewp/elgato/firmware

# Активировать ESP-IDF
. ~/esp/esp-idf/export.sh

# Создать проект из шаблона
idf.py create-project macro-keyboard

# Или скопировать пример
cp -r $IDF_PATH/examples/get-started/hello_world ./macro-keyboard
```

### Вариант 2: Через VS Code

1. Откройте VS Code
2. `Ctrl+Shift+P` → "ESP-IDF: Show Examples Projects"
3. Выберите "get-started/hello_world"
4. Укажите путь: `/home/andrewp/elgato/firmware/macro-keyboard`

## Структура проекта ESP-IDF

```
firmware/macro-keyboard/
├── CMakeLists.txt              # Главный CMake файл
├── sdkconfig                   # Конфигурация проекта
├── sdkconfig.defaults          # Дефолтная конфигурация
├── partitions.csv              # Таблица разделов flash
│
└── main/
    ├── CMakeLists.txt          # CMake для main компонента
    ├── main.c                  # Точка входа (app_main)
    ├── Kconfig.projbuild       # Опции конфигурации
    │
    ├── hardware/               # Драйверы hardware
    ├── usb/                    # USB функциональность
    ├── protocol/               # Протокол обмена
    ├── storage/                # Работа с памятью
    ├── profile/                # Управление профилями
    ├── network/                # WiFi и OTA
    ├── ui/                     # Дисплеи
    └── utils/                  # Утилиты
```

## Конфигурация проекта

### Настройка для ESP32-S3

```bash
cd firmware/macro-keyboard

# Активировать ESP-IDF
. ~/esp/esp-idf/export.sh

# Открыть menuconfig
idf.py menuconfig
```

### Ключевые настройки

В menuconfig настройте:

1. **Serial flasher config**
   - Flash size: 16 MB
   - Flash mode: QIO
   - Flash frequency: 80 MHz

2. **Partition Table**
   - Partition Table: Custom partition table CSV
   - Custom partition CSV file: partitions.csv

3. **Component config → ESP32S3-Specific**
   - Support for external, SPI-connected RAM: Enable
   - SPI RAM config → Mode: Octal
   - SPI RAM config → Speed: 80MHz

4. **Component config → FreeRTOS**
   - Tick rate (Hz): 1000

5. **Component config → USB**
   - Enable TinyUSB: Yes

6. **Component config → Wi-Fi**
   - WiFi Task Core ID: Core 0

## Компиляция и прошивка

### Быстрый старт - Сборка текущего проекта

```bash
# Перейти в директорию прошивки
cd /home/andrewp/elgato/firmware

# Активировать ESP-IDF окружение
. ~/esp/esp-idf/export.sh

# Собрать проект
idf.py build

# Первая сборка займет несколько минут
# Последующие сборки будут быстрее благодаря ccache
```

### Результаты сборки

После успешной сборки в директории `build/` будут созданы:

```
build/
├── bootloader/
│   └── bootloader.bin          # Загрузчик
├── partition_table/
│   └── partition-table.bin     # Таблица разделов
├── macro-keyboard.bin          # Основная прошивка (или имя вашего проекта)
└── macro-keyboard.elf          # ELF файл для отладки
```

### Компиляция (детально)

```bash
cd firmware/macro-keyboard

# Активировать ESP-IDF
. ~/esp/esp-idf/export.sh

# Собрать проект
idf.py build

# Первая сборка займет несколько минут
# Последующие сборки будут быстрее благодаря ccache
```

### Прошивка устройства

```bash
# Подключить ESP32-S3 через USB

# Определить порт
ls /dev/ttyUSB* /dev/ttyACM*
# Обычно /dev/ttyUSB0 или /dev/ttyACM0

# Прошить устройство
idf.py -p /dev/ttyUSB0 flash

# Или прошить и сразу открыть монитор
idf.py -p /dev/ttyUSB0 flash monitor
```

### Мониторинг

```bash
# Открыть serial monitor
idf.py -p /dev/ttyUSB0 monitor

# Выход из монитора: Ctrl+]
```

## Отладка

### OpenOCD и GDB

```bash
# В одном терминале запустить OpenOCD
openocd -f board/esp32s3-builtin.cfg

# В другом терминале запустить GDB
xtensa-esp32s3-elf-gdb build/macro-keyboard.elf
(gdb) target remote :3333
(gdb) mon reset halt
(gdb) continue
```

### VS Code Debugging

Создайте `.vscode/launch.json`:

```json
{
    "version": "0.2.0",
    "configurations": [
        {
            "name": "ESP32-S3 Debug",
            "type": "cppdbg",
            "request": "launch",
            "program": "${workspaceFolder}/firmware/macro-keyboard/build/macro-keyboard.elf",
            "cwd": "${workspaceFolder}",
            "MIMode": "gdb",
            "miDebuggerPath": "${env:HOME}/esp/esp-idf/.espressif/tools/xtensa-esp-elf-gdb/12.1_20221002/xtensa-esp-elf-gdb/bin/xtensa-esp32s3-elf-gdb",
            "miDebuggerServerAddress": "localhost:3333",
            "setupCommands": [
                {"text": "target remote :3333"},
                {"text": "mon reset halt"},
                {"text": "flushregs"}
            ]
        }
    ]
}
```

## Полезные команды

```bash
# Очистить сборку
idf.py fullclean

# Только очистить app (быстрее)
idf.py app-flash

# Стереть flash полностью
idf.py -p /dev/ttyUSB0 erase-flash

# Показать размер прошивки
idf.py size

# Показать размер компонентов
idf.py size-components

# Показать размер файлов
idf.py size-files

# Создать partition table
idf.py partition-table

# Прошить только partition table
idf.py partition-table-flash
```

## Troubleshooting

### Ошибка: Permission denied /dev/ttyUSB0

```bash
# Добавить пользователя в группу dialout
sudo usermod -a -G dialout $USER

# Перелогиниться или выполнить
newgrp dialout

# Или дать права на порт (временно)
sudo chmod 666 /dev/ttyUSB0
```

### Ошибка: Failed to connect to ESP32-S3

1. Проверьте подключение USB
2. Нажмите кнопку BOOT на плате
3. Попробуйте другой USB кабель
4. Проверьте, что используется data-кабель, а не только для зарядки

### Ошибка: ccache not found

```bash
sudo apt-get install ccache
```

### Ошибка: ninja not found

```bash
sudo apt-get install ninja-build
```

### Ошибка: Python packages missing

```bash
cd ~/esp/esp-idf
./install.sh esp32s3
```

## Проверка установки

Выполните эти команды для проверки:

```bash
# 1. Активировать ESP-IDF
. ~/esp/esp-idf/export.sh

# 2. Проверить версию
idf.py --version

# 3. Проверить компилятор
xtensa-esp32s3-elf-gcc --version

# 4. Проверить Python
python --version

# 5. Проверить cmake
cmake --version

# 6. Проверить ninja
ninja --version
```

Все команды должны выполниться без ошибок.

## Быстрая справка по командам

### Основные команды сборки

```bash
# Активировать ESP-IDF
. ~/esp/esp-idf/export.sh

# Перейти в проект
cd /home/andrewp/elgato/firmware

# Собрать
idf.py build

# Прошить
idf.py -p /dev/ttyUSB0 flash

# Прошить и открыть монитор
idf.py -p /dev/ttyUSB0 flash monitor

# Только монитор
idf.py -p /dev/ttyUSB0 monitor

# Очистить сборку
idf.py fullclean

# Конфигурация
idf.py menuconfig

# Размер прошивки
idf.py size
```

### Однострочная команда для быстрой сборки и прошивки

```bash
cd /home/andrewp/elgato/firmware && . ~/esp/esp-idf/export.sh && idf.py build && idf.py -p /dev/ttyUSB0 flash monitor
```

## Следующие шаги

После установки ESP-IDF:

1. Изучите документацию:
   - [`firmware/plans/REQUIREMENTS.md`](plans/REQUIREMENTS.md) - требования
   - [`../plans/architecture.md`](../plans/architecture.md) - архитектура
   - [`../plans/esp_idf_components.md`](../plans/esp_idf_components.md) - готовые компоненты

2. Создайте структуру проекта

3. Начните с базовой инициализации:
   - USB HID
   - GPIO для кнопок
   - SPI для дисплеев

4. Постепенно добавляйте функциональность

## Полезные ссылки

- [ESP-IDF Programming Guide](https://docs.espressif.com/projects/esp-idf/en/latest/esp32s3/)
- [ESP32-S3 Technical Reference](https://www.espressif.com/sites/default/files/documentation/esp32-s3_technical_reference_manual_en.pdf)
- [ESP-IDF Examples](https://github.com/espressif/esp-idf/tree/master/examples)
- [TinyUSB Documentation](https://docs.tinyusb.org/)
- [ESP-IDF VS Code Extension](https://github.com/espressif/vscode-esp-idf-extension)

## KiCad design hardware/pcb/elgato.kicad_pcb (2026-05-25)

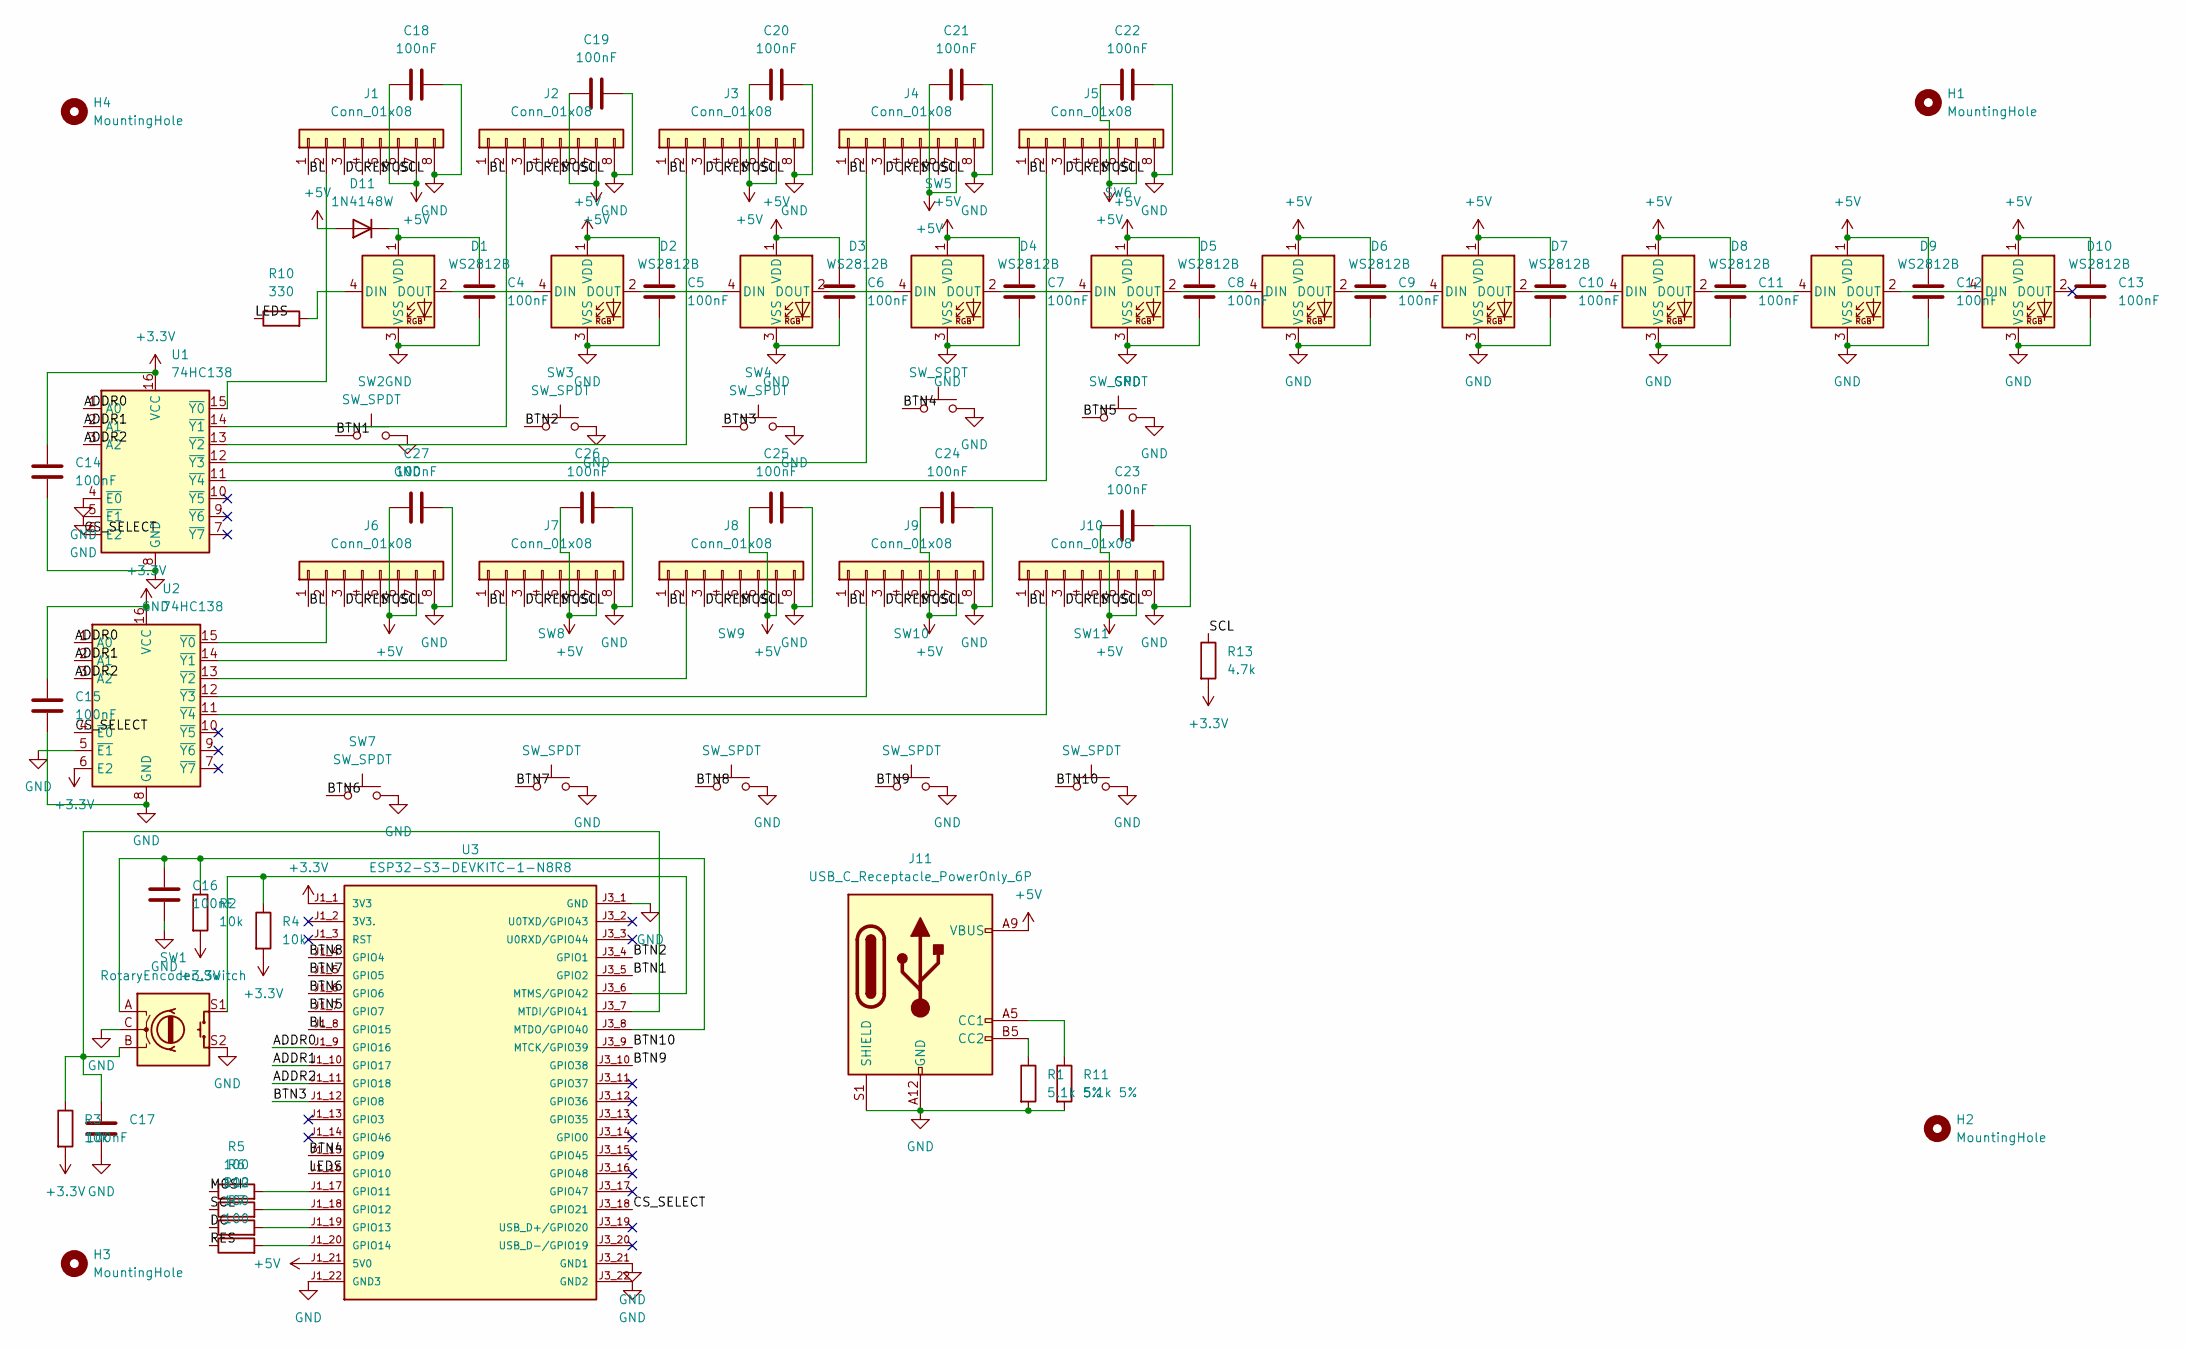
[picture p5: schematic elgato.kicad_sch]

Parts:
C4, C5, C6, C7, C8, C9, C10, C11, C12, C13, C14, C15, C16, C17, C18, C19, C20, C21, C22, C23, C24, C25, C26, C27: 100nF; C_0805_2012Metric; LCSC C710980
D1, D2, D3, D4, D5, D6, D7, D8, D9, D10: WS2812B; LED_WS2812B_PLCC4_5.0x5.0mm_P3.2mm; LCSC C52917433
D11: 1N4148W; D_SOD-123; LCSC C83528
H1, H2, H3, H4: MountingHole; MountingHole_3.2mm_M3
J1, J2, J3, J4, J5, J6, J7, J8, J9, J10: Conn_01x08; PinHeader_1x08_P2.54mm_Vertical
J11: USB_C_Receptacle_PowerOnly_6P; USB_C_Receptacle_HRO_TYPE-C-31-M-17; LCSC C283540
R1, R11: 5.1k 5%; R_0805_2012Metric; LCSC C2912599
R2, R3, R4: 10k; R_0805_2012Metric; LCSC C5123591
R5, R6, R7, R12: 100; R_0805_2012Metric; LCSC C2912614
R10: 330; R_0805_2012Metric; LCSC C2558024
R13: 4.7k; R_Axial_DIN0204_L3.6mm_D1.6mm_P5.08mm_Horizontal
SW1: RotaryEncoder_Switch; RotaryEncoder_Alps_EC11E-Switch_Vertical_H20mm
SW2, SW3, SW4, SW5, SW6, SW7, SW8, SW9, SW10, SW11: SW_SPDT; SW_Cherry_MX_1.00u_PCB
U1, U2: 74HC138; SOIC-16_3.9x9.9mm_P1.27mm; LCSC C6818
U3: ESP32-S3-DEVKITC-1-N8R8

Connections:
+3.3V: C14.1, C15.1, R2.2, R3.2, R4.2, R13.2, U1.16 (VCC), U2.6 (E2), U2.16 (VCC), U3.J1_1 (3V3)
+5V: C5.1, C6.1, C7.1, C8.1, C9.1, C10.1, C11.1, C12.1, C13.1, C18.1, C19.1, C20.1, C21.1, C22.1, C23.1, C24.1, C25.1, C26.1, C27.1, D2.1 (VDD), D3.1 (VDD), D4.1 (VDD), D5.1 (VDD), D6.1 (VDD), D7.1 (VDD), D8.1 (VDD), D9.1 (VDD), D10.1 (VDD), D11.2 (A), J1.7, J2.7, J3.7, J4.7, J5.7, J6.7, J7.7, J8.7, J9.7, J10.7, J11.A9 (VBUS), J11.B9 (VBUS), U3.J1_21 (5V0); also elsewhere on the board
/ADDR0: U1.1 (A0), U2.1 (A0), U3.J1_9 (GPIO16)
/ADDR1: U1.2 (A1), U2.2 (A1), U3.J1_10 (GPIO17)
/ADDR2: U1.3 (A2), U2.3 (A2), U3.J1_11 (GPIO18)
/BL: J1.1, J2.1, J3.1, J4.1, J5.1, J6.1, J7.1, J8.1, J9.1, J10.1, U3.J1_8 (GPIO15)
/BTN1: SW2.1, U3.J3_5 (GPIO2)
/BTN2: SW3.1, U3.J3_4 (GPIO1)
/BTN3: SW4.1, U3.J1_12 (GPIO8)
/BTN4: SW5.1, U3.J1_15 (GPIO9)
/BTN5: SW6.1, U3.J1_7 (GPIO7)
/BTN6: SW7.1, U3.J1_6 (GPIO6)
/BTN7: SW8.1, U3.J1_5 (GPIO5)
/BTN8: SW9.1, U3.J1_4 (GPIO4)
/BTN9: SW10.1, U3.J3_10 (GPIO38)
/BTN10: SW11.1, U3.J3_9 (MTCK/GPIO39)
/CS_SELECT: U1.6 (E2), U2.4 (~E0), U3.J3_18 (GPIO21)
/DC: J1.3, J2.3, J3.3, J4.3, J5.3, J6.3, J7.3, J8.3, J9.3, J10.3, R12.1
/LEDS: R10.1, U3.J1_16 (GPIO10)
/MOSI: J1.5, J2.5, J3.5, J4.5, J5.5, J6.5, J7.5, J8.5, J9.5, J10.5, R5.1
/RES: J1.4, J2.4, J3.4, J4.4, J5.4, J6.4, J7.4, J8.4, J9.4, J10.4, R7.1
/SCL: J1.6, J2.6, J3.6, J4.6, J5.6, J6.6, J7.6, J8.6, J9.6, J10.6, R6.1, R13.1
GND: C4.2, C5.2, C6.2, C7.2, C8.2, C9.2, C10.2, C11.2, C12.2, C13.2, C14.2, C15.2, C16.2, C17.2, C18.2, C19.2, C20.2, C21.2, C22.2, C23.2, C24.2, C25.2, C26.2, C27.2, D1.3 (VSS), D2.3 (VSS), D3.3 (VSS), D4.3 (VSS), D5.3 (VSS), D6.3 (VSS), D7.3 (VSS), D8.3 (VSS), D9.3 (VSS), D10.3 (VSS), J1.8, J2.8, J3.8, J4.8, J5.8, J6.8, J7.8, J8.8, J9.8, J10.8, J11.A12 (GND), J11.B12 (GND), J11.S1 (SHIELD), R1.2, R11.2, SW1.C, SW1.S2, SW2.2, SW3.2, SW4.2, SW5.2, SW6.2, SW7.2, SW8.2, SW9.2, SW10.2, SW11.2, U1.4 (~E0), U1.5 (~E1), U1.8 (GND), U2.5 (~E1), U2.8 (GND), U3.J1_22 (GND3), U3.J3_1 (GND), U3.J3_21 (GND1), U3.J3_22 (GND2); also elsewhere on the board
unnamed: D1.4 (DIN), R10.2
unnamed: D1.2 (DOUT), D2.4 (DIN)
unnamed: C4.1, D1.1 (VDD), D11.1 (K)
unnamed: D2.2 (DOUT), D3.4 (DIN)
unnamed: D3.2 (DOUT), D4.4 (DIN)
unnamed: D4.2 (DOUT), D5.4 (DIN)
unnamed: D5.2 (DOUT), D6.4 (DIN)
unnamed: D6.2 (DOUT), D7.4 (DIN)
unnamed: D7.2 (DOUT), D8.4 (DIN)
unnamed: D8.2 (DOUT), D9.4 (DIN)
unnamed: D9.2 (DOUT), D10.4 (DIN)
unnamed: J1.2, U1.15 (~Y0)
unnamed: J2.2, U1.14 (~Y1)
unnamed: J3.2, U1.13 (~Y2)
unnamed: J4.2, U1.12 (~Y3)
unnamed: J5.2, U1.11 (~Y4)
unnamed: J6.2, U2.15 (~Y0)
unnamed: J7.2, U2.14 (~Y1)
unnamed: J8.2, U2.13 (~Y2)
unnamed: J9.2, U2.12 (~Y3)
unnamed: J10.2, U2.11 (~Y4)
unnamed: J11.A5 (CC1), R11.1
unnamed: J11.B5 (CC2), R1.1
unnamed: R5.2, U3.J1_17 (GPIO11)
unnamed: R6.2, U3.J1_18 (GPIO12)
unnamed: R12.2, U3.J1_19 (GPIO13)
unnamed: R7.2, U3.J1_20 (GPIO14)
unnamed: C17.1, R3.1, SW1.B, U3.J3_7 (MTDI/GPIO41)
unnamed: C16.1, R2.1, SW1.A, U3.J3_8 (MTDO/GPIO40)
unnamed: R4.1, SW1.S1, U3.J3_6 (MTMS/GPIO42)

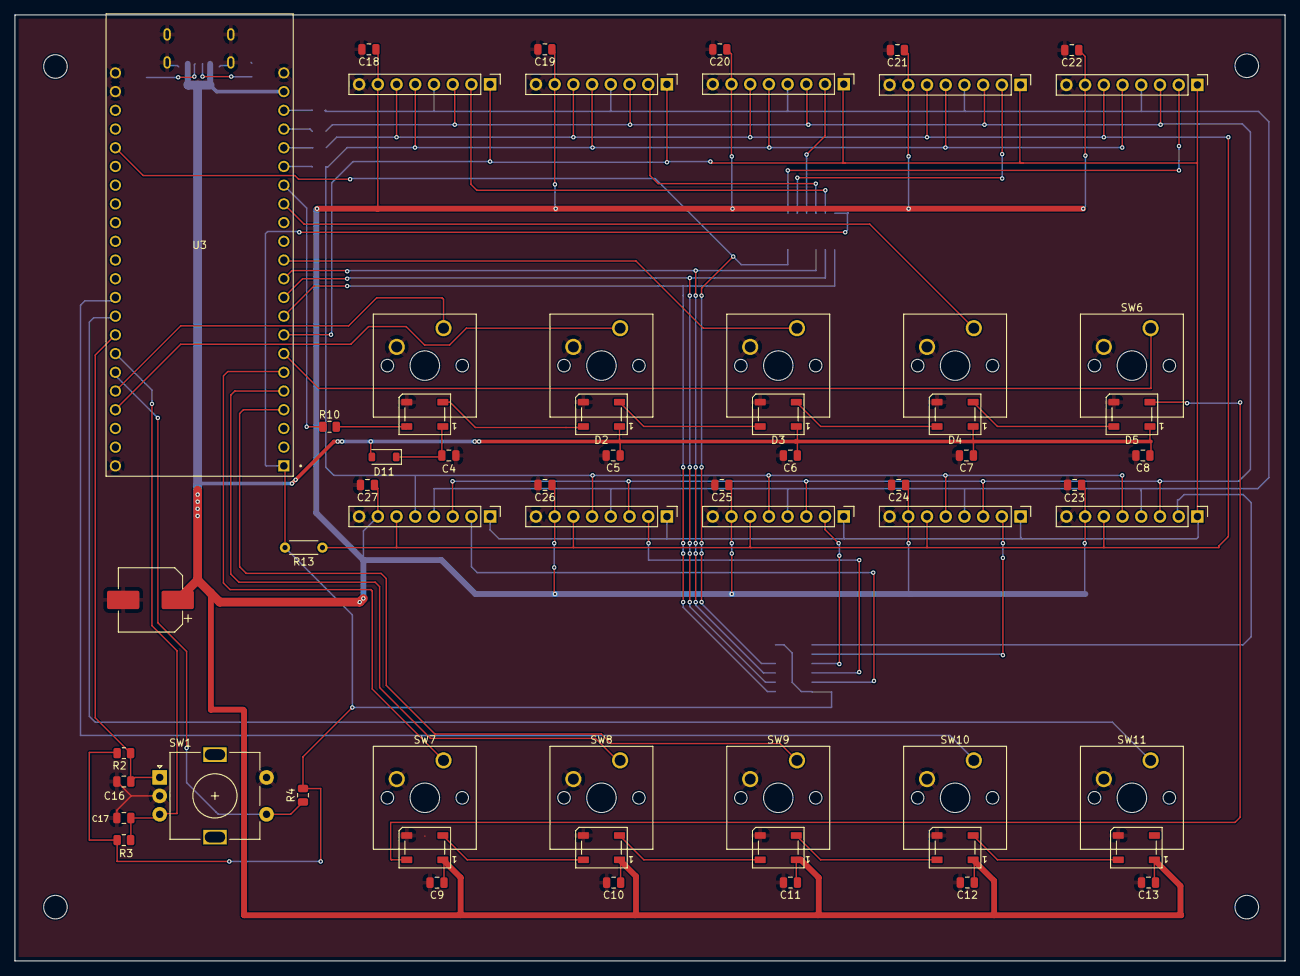
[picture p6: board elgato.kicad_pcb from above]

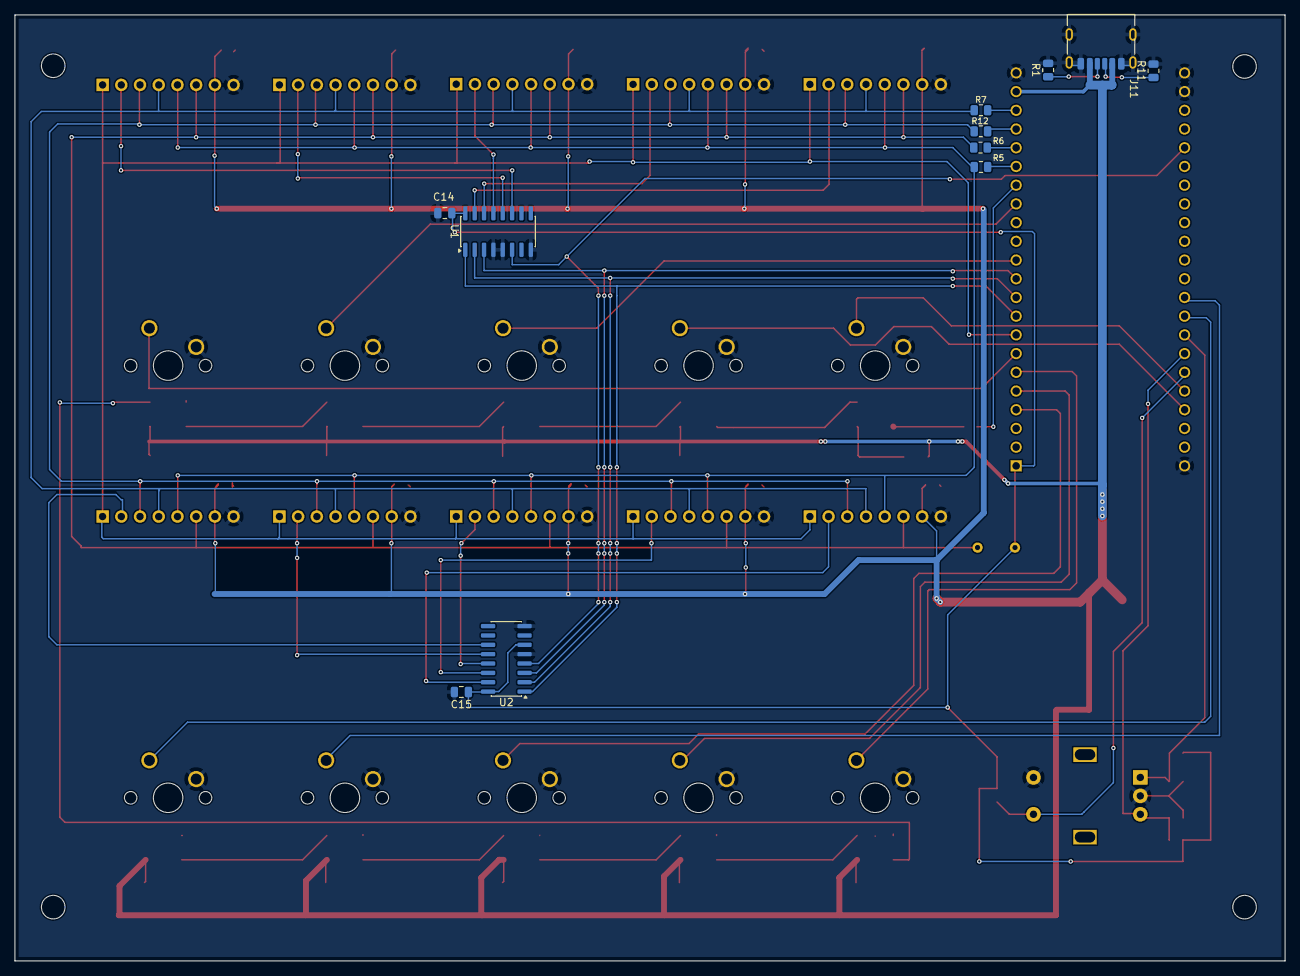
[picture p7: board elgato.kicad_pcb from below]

Board: 2 copper layers, 172.4 x 128.4 mm, 76 parts (11 on the bottom side), 53 nets.

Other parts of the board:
C1: 470uF 10V; CP_Elec_8x10.5

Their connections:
+5V: C1.1; also elsewhere on the board
GND: C1.2; also elsewhere on the board

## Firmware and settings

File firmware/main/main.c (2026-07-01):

/**
 * @file main.c
 * @brief Main entry point for ESP32-S3 Macro Keyboard firmware
 */

#include "common.h"
#include "config.h"
#include "tinyusb.h"
#include "hardware/gc9a01.h"
#include "hardware/display_mux.h"
#include "hardware/display_task.h"
#include "hardware/buttons.h"
#include "hardware/encoder.h"
#include "hardware/leds.h"
#include "usb/usb_hid_keyboard.h"
#include "usb/usb_vendor.h"
#include "protocol/protocol_handler.h"
#include "protocol/heartbeat_task.h"
#include "storage/nvs_manager.h"
#include "storage/profile_storage.h"
#include "storage/image_storage.h"
#include "storage/save_task.h"
#include "profile/profile_manager.h"

static const char* TAG = "MAIN";

// External USB descriptors (defined in usb_descriptors.c)
extern const tusb_desc_device_t desc_device;
extern const uint8_t desc_configuration[];
extern const char *desc_string_arr[];
extern const int desc_string_count;

void app_main(void) {
    esp_err_t ret;
    
    ESP_LOGI(TAG, "===========================================");
    ESP_LOGI(TAG, "  ESP32-S3 Macro Keyboard Firmware v%s", FIRMWARE_VERSION);
    ESP_LOGI(TAG, "===========================================");
    
    // ============================================
    // PHASE 1: Core System Initialization
    // ============================================
    
    ESP_LOGI(TAG, "Phase 1: Core System Init");
    
    // 1.1 Configure log levels
    esp_log_level_set("*", ESP_LOG_INFO);
    esp_log_level_set("MAIN", ESP_LOG_DEBUG);
    esp_log_level_set("PROTOCOL", ESP_LOG_DEBUG);
    esp_log_level_set("USB_HID", ESP_LOG_DEBUG);
    esp_log_level_set("PROFILE", ESP_LOG_DEBUG);
    
    // 1.2 Initialize NVS
    ret = nvs_manager_init();
    if (ret != ESP_OK) {
        ESP_LOGE(TAG, "Failed to initialize NVS: %s", esp_err_to_name(ret));
        return;
    }
    ESP_LOGI(TAG, "✓ NVS initialized");
    
    // 1.3 Initialize SPIFFS
    ret = profile_storage_init();
    if (ret != ESP_OK) {
        ESP_LOGE(TAG, "Failed to initialize SPIFFS: %s", esp_err_to_name(ret));
        return;
    }
    ESP_LOGI(TAG, "✓ SPIFFS initialized");
    
    // 1.4 Initialize image storage (deduplication layer, migrates legacy files)
    ret = image_storage_init();
    if (ret != ESP_OK) {
        ESP_LOGW(TAG, "Image storage init failed: %s (non-fatal)", esp_err_to_name(ret));
    }
    ESP_LOGI(TAG, "✓ Image storage initialized");

    // 1.5 Initialize async save queue (must be before any task creation)
    ret = save_task_init();
    if (ret != ESP_OK) {
        ESP_LOGE(TAG, "Save task init failed: %s", esp_err_to_name(ret));
        return;
    }
    ESP_LOGI(TAG, "✓ Save task initialized");
    
    // ============================================
    // PHASE 2: Hardware Initialization
    // ============================================
    
    ESP_LOGI(TAG, "Phase 2: Hardware Init");
    
    // 2.1 Initialize display multiplexer
    ret = display_mux_init();
    ESP_ERROR_CHECK(ret);
    ESP_LOGI(TAG, "✓ Display multiplexer initialized");
    
    // 2.2 Initialize SPI and GC9D01 displays
    ret = gc9a01_init();
    ESP_ERROR_CHECK(ret);
    ESP_LOGI(TAG, "✓ SPI and display driver initialized");
    
    // 2.2.1 Enable display backlight
    gc9a01_set_backlight(true);
    ESP_LOGI(TAG, "✓ Display backlight enabled");
    
    // 2.3 Initialize all displays (pipelined: one shared 200 ms Sleep-Out wait
    //     for all 10 displays instead of 10 sequential 200 ms waits)
    gc9a01_init_all_displays();
    ESP_LOGI(TAG, "✓ All %d displays initialized", NUM_DISPLAYS);
    
    // 2.4 Initialize buttons
    ret = buttons_init();
    ESP_ERROR_CHECK(ret);
    ESP_LOGI(TAG, "✓ Buttons initialized (%d buttons)", NUM_BUTTONS);
    
    // 2.5 Initialize rotary encoder
    ret = encoder_init();
    ESP_ERROR_CHECK(ret);
    ESP_LOGI(TAG, "✓ Encoder initialized");
    
    // 2.6 Initialize WS2812 LEDs
    ret = leds_init();
    ESP_ERROR_CHECK(ret);
    ESP_LOGI(TAG, "✓ WS2812 LEDs initialized (%d LEDs)", NUM_LEDS);
    
    // ============================================
    // PHASE 3: USB Initialization
    // ============================================
    
    ESP_LOGI(TAG, "Phase 3: USB Init");
    
    // 3.1 Initialize TinyUSB — composite device (HID + Vendor)
    // Device descriptor, config descriptor, and string descriptors are
    // provided via TinyUSB callbacks in usb_descriptors.c.
    // We also pass them here for the esp_tinyusb wrapper.
    tinyusb_config_t tusb_cfg = {
        .port = TINYUSB_PORT_FULL_SPEED_0,
        .task = {
            .size = 4096,
            .priority = 5,
            .xCoreID = 0,
        },
        .descriptor = {
            .device = &desc_device,
            .string = desc_string_arr,
            .string_count = desc_string_count,
            .full_speed_config = desc_configuration,
            .high_speed_config = NULL,
        },
    };

    ret = tinyusb_driver_install(&tusb_cfg);
    if (ret != ESP_OK) {
        ESP_LOGE(TAG, "Failed to initialize TinyUSB: %s", esp_err_to_name(ret));
        ESP_LOGI(TAG, "Continuing without USB...");
    } else {
        ESP_LOGI(TAG, "✓ TinyUSB driver installed (composite: HID + Vendor)");
    }
    
    // 3.2 Initialize USB HID Keyboard interface
    usb_hid_keyboard_init();
    ESP_LOGI(TAG, "✓ USB HID Keyboard ready");
    
    // 3.3 Initialize USB Vendor interface
    usb_vendor_init();
    ESP_LOGI(TAG, "✓ USB Vendor interface ready");
    
    // Brief wait for USB enumeration (non-blocking: device works fine without USB)
    ESP_LOGI(TAG, "Waiting for USB enumeration...");
    int timeout = 10; // 1 second max (USB enum typically takes <500ms)
    while (!tud_mounted() && timeout > 0) {
        vTaskDelay(pdMS_TO_TICKS(100));
        timeout--;
    }
    
    if (tud_mounted()) {
        ESP_LOGI(TAG, "✓ USB enumerated");
    } else {
        ESP_LOGI(TAG, "USB not connected — continuing without host");
    }
    
    // ============================================
    // PHASE 4: Protocol Initialization
    // ============================================
    
    ESP_LOGI(TAG, "Phase 4: Protocol Init");
    
    ret = display_task_init();
    ESP_ERROR_CHECK(ret);
    ESP_LOGI(TAG, "✓ Display task queue initialized");

    ret = protocol_handler_init();
    ESP_ERROR_CHECK(ret);
    ESP_LOGI(TAG, "✓ Protocol handler initialized");
    
    // ============================================
    // PHASE 5: Profile Loading
    // ============================================
    
    ESP_LOGI(TAG, "Phase 5: Profile Loading");
    
    // 5.1 Initialize profile manager
    ret = profile_manager_init();
    if (ret != ESP_OK) {
        ESP_LOGE(TAG, "Failed to initialize profile manager: %s", esp_err_to_name(ret));
        return;
    }
    ESP_LOGI(TAG, "✓ Profile loaded");

    // 5.1.1 Run GC now that the profile is in memory — avoids the redundant
    //       SPIFFS read that image_storage_gc() would otherwise do itself.
    image_storage_gc(profile_get());
    
    // 5.2 Update LEDs from profile (uses BTN_LED_BRIGHTNESS which suppresses
    //     ACTION_TYPE_NONE buttons — same path as night mode exit / folder exit)
    profile_restore_leds();
    ESP_LOGI(TAG, "✓ LEDs configured from profile");
    
    // 5.3 Refresh all button displays (images or text labels) from current profile
    ESP_LOGI(TAG, "Refreshing displays...");
    profile_refresh_displays();
    
    // ============================================
    // PHASE 6: Task Creation
    // ============================================
    
    ESP_LOGI(TAG, "Phase 6: Creating FreeRTOS Tasks");
    
    // 6.1 Create USB Vendor RX task
    xTaskCreatePinnedToCore(usb_vendor_rx_task, "usb_vendor_rx", STACK_SIZE_USB_RX, NULL,
                            TASK_PRIORITY_USB_RX, NULL, 0);
    ESP_LOGI(TAG, "✓ USB Vendor RX task created");
    
    // 6.2 Create button task
    xTaskCreatePinnedToCore(button_task, "button", STACK_SIZE_BUTTON, NULL,
                            TASK_PRIORITY_BUTTON, NULL, 1);
    ESP_LOGI(TAG, "✓ Button task created");
    
    // 6.3 Create encoder task
    xTaskCreatePinnedToCore(encoder_task, "encoder", STACK_SIZE_ENCODER, NULL,
                            TASK_PRIORITY_ENCODER, NULL, 1);
    ESP_LOGI(TAG, "✓ Encoder task created");
    
    // 6.4 Create protocol task
    xTaskCreatePinnedToCore(protocol_task, "protocol", STACK_SIZE_PROTOCOL, NULL,
                            TASK_PRIORITY_PROTOCOL, NULL, 0);
    ESP_LOGI(TAG, "✓ Protocol task created");
    
    // 6.5b Save task (Core 0) — async SPIFFS writes, lower priority than protocol
    xTaskCreatePinnedToCore(save_task_fn, "save", STACK_SIZE_SAVE, NULL,
                            TASK_PRIORITY_SAVE, NULL, 0);
    ESP_LOGI(TAG, "✓ Save task created (Core 0)");

    // 6.5c Heartbeat task (Core 0) — sends EVENT_HEARTBEAT (0xF8) every 2 s so
    //      the host can detect device liveness after a backend restart.  Bypasses
    //      protocol_cmd_queue so it fires even when protocol_task is blocked on I/O.
    xTaskCreatePinnedToCore(heartbeat_task, "heartbeat", STACK_SIZE_HEARTBEAT, NULL,
                            TASK_PRIORITY_HEARTBEAT, NULL, 0);
    ESP_LOGI(TAG, "✓ Heartbeat task created (Core 0)");

    // 6.6 Create display task (Core 1) — SPI draws run independently of protocol_task
    xTaskCreatePinnedToCore(display_task, "display", STACK_SIZE_DISPLAY, NULL,
                            TASK_PRIORITY_DISPLAY, NULL, 1);
    ESP_LOGI(TAG, "✓ Display task created (Core 1)");
    
    // ============================================
    // PHASE 7: System Ready
    // ============================================
    
    ESP_LOGI(TAG, "===========================================");
    ESP_LOGI(TAG, "  System Ready!");
    ESP_LOGI(TAG, "===========================================");
    ESP_LOGI(TAG, "Firmware Version: %s", FIRMWARE_VERSION);
    ESP_LOGI(TAG, "Current Profile: 0");
    ESP_LOGI(TAG, "Free heap: %u bytes", (unsigned int)esp_get_free_heap_size());
    ESP_LOGI(TAG, "Free PSRAM: %u bytes", (unsigned int)heap_caps_get_free_size(MALLOC_CAP_SPIRAM));
    
    // Image deduplication stats
    {
        uint16_t unique_images = 0, total_mappings = 0;
        uint32_t saved_bytes = 0;
        image_storage_get_stats(&unique_images, &total_mappings, &saved_bytes);
        ESP_LOGI(TAG, "Images: %d unique, %d mappings, %lu bytes saved by dedup",
                 unique_images, total_mappings, (unsigned long)saved_bytes);
    }
    
    ESP_LOGI(TAG, "===========================================");
    
    // Send device ready event to PC (defined in protocol_types.h)
    protocol_send_event(0xF4, NULL, 0);  // EVENT_DEVICE_READY = 0xF4
    
    // Main task can now delete itself
    vTaskDelete(NULL);
}

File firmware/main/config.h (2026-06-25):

/**
 * @file config.h
 * @brief Configuration constants for ESP32-S3 Macro Keyboard
 */

#ifndef CONFIG_H
#define CONFIG_H

#include <stdint.h>

// ============================================
// Firmware Version
// ============================================
#define FIRMWARE_VERSION_MAJOR  1
#define FIRMWARE_VERSION_MINOR  0
#define FIRMWARE_VERSION_PATCH  0
#define FIRMWARE_VERSION        "1.0.0"

// ============================================
// Hardware Configuration
// ============================================

// Number of buttons and displays
#define NUM_BUTTONS             10
#define NUM_DISPLAYS            10
#define NUM_LEDS                10

// Display specifications
#define DISPLAY_WIDTH           160
#define DISPLAY_HEIGHT          160
#define DISPLAY_PIXEL_COUNT     (DISPLAY_WIDTH * DISPLAY_HEIGHT)
#define DISPLAY_BUFFER_SIZE     (DISPLAY_PIXEL_COUNT * 2)  // RGB565

// ============================================
// GPIO Pin Definitions
// ============================================

// SPI for displays
#define PIN_SPI_MOSI            11
#define PIN_SPI_CLK             12
#define PIN_SPI_DC              13
#define PIN_SPI_RST             14
#define PIN_DISPLAY_BACKLIGHT   15  // Common backlight control for all displays

// Display multiplexer (74HC138 decoders)
#define PIN_MUX_A0              16
#define PIN_MUX_A1              17
#define PIN_MUX_A2              18
#define PIN_MUX_SEL             21

// Buttons (GPIO pins)
#define PIN_BUTTON_0            2
#define PIN_BUTTON_1            1
#define PIN_BUTTON_2            8
#define PIN_BUTTON_3            9
#define PIN_BUTTON_4            7
#define PIN_BUTTON_5            6
#define PIN_BUTTON_6            5
#define PIN_BUTTON_7            4
#define PIN_BUTTON_8            38
#define PIN_BUTTON_9            39

// Rotary encoder
#define PIN_ENCODER_A           41
#define PIN_ENCODER_B           40
#define PIN_ENCODER_BTN         42

// WS2812 RGB LEDs
#define PIN_LED_DATA            10

// ============================================
// SPI Configuration
// ============================================
#define SPI_HOST                SPI2_HOST
#define SPI_CLOCK_SPEED_HZ      (20 * 1000 * 1000)  // 20 MHz
#define SPI_DMA_CHAN            SPI_DMA_CH_AUTO

// ============================================
// Profile Configuration
// ============================================
#define PROFILE_NAME_MAX_LEN    32
#define BUTTON_NAME_MAX_LEN     32
#define ACTION_DATA_MAX_LEN     51   // Max action blob bytes (protocol payload 56 − 5 header)

// Folder Configuration
#define NUM_FOLDERS             16  // Maximum number of folders per profile
#define FOLDER_STACK_DEPTH      8   // Maximum nesting depth for folders

// ============================================
// Storage Paths
// ============================================
#define STORAGE_BASE_PATH       "/storage"
#define PROFILE_FILE_FMT        "/storage/profile_%d.bin"
#define IMAGE_FILE_FMT          "/storage/img_%d_%d.jpg"

// ============================================
// Protocol Configuration
// ============================================
#define PROTOCOL_PACKET_SIZE    64
#define PROTOCOL_MAGIC          0xEA  // 'EA' for Elgato
#define PROTOCOL_VERSION        0x01

// ============================================
// USB Configuration
// ============================================
#define USB_VID                 0x1209  // pid.codes (Open Source VID)
#define USB_PID                 0x0001  // MacroKeyboard PID
#define USB_MANUFACTURER        "Elgato"
#define USB_PRODUCT             "Stream Deck"
#define USB_SERIAL              "123456"

#define USB_HID_REPORT_SIZE     64

// ============================================
// Task Priorities
// ============================================
#define TASK_PRIORITY_USB_RX    20
#define TASK_PRIORITY_BUTTON    18
#define TASK_PRIORITY_ENCODER   18
#define TASK_PRIORITY_PROTOCOL  15
#define TASK_PRIORITY_DISPLAY   12
#define TASK_PRIORITY_SAVE      8
#define TASK_PRIORITY_HEARTBEAT 6
#define TASK_PRIORITY_MONITOR   3

// ============================================
// Task Stack Sizes
// ============================================
#define STACK_SIZE_USB_RX       4096
#define STACK_SIZE_BUTTON       8192
#define STACK_SIZE_ENCODER      4096
#define STACK_SIZE_PROTOCOL     8192
#define STACK_SIZE_DISPLAY      8192
#define STACK_SIZE_SAVE         4096
#define STACK_SIZE_HEARTBEAT    2048

// ============================================
// Timing Configuration
// ============================================
#define BUTTON_DEBOUNCE_MS      10
#define BUTTON_LONG_PRESS_MS    1000
#define REBOOT_COMBO_BUTTONS    {0, 1, 2}
#define REBOOT_COMBO_LEN        3
#define ENCODER_STEPS_PER_PROFILE 4

// ============================================
// LED Configuration
// ============================================
#define LED_DEFAULT_BRIGHTNESS  80
#define LED_MAX_BRIGHTNESS      100
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

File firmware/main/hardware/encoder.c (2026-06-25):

/**
 * @file encoder.c
 * @brief Rotary encoder driver implementation
 */

#include "encoder.h"
#include "config.h"
#include "esp_log.h"
#include "driver/gpio.h"
#include "esp_timer.h"
#include "profile/action_executor.h"
#include "profile/profile_manager.h"

static const char* TAG = "ENCODER";

QueueHandle_t encoder_event_queue = NULL;

static volatile uint32_t s_isr_fire_count = 0;  // incremented in ISR, logged in task

// Encoder state machine lookup table
static const int8_t encoder_table[16] = {
    0,  // 0000
    1,  // 0001 CW step 1
    -1, // 0010 CCW step 1
    0,  // 0011
    -1, // 0100 CCW step 2
    0,  // 0101
    0,  // 0110
    1,  // 0111 CW step 2
    1,  // 1000 CW step 3
    0,  // 1001
    0,  // 1010
    -1, // 1011 CCW step 3
    0,  // 1100
    -1, // 1101 CCW step 4
    1,  // 1110 CW step 4
    0   // 1111
};

// ISR handler for encoder rotation
static void IRAM_ATTR encoder_rotation_isr(void* arg) {
    static uint8_t prev_state = 0;
    
    uint8_t a = gpio_get_level(PIN_ENCODER_A);
    uint8_t b = gpio_get_level(PIN_ENCODER_B);
    
    uint8_t current_state = (a << 1) | b;
    uint8_t combined = (prev_state << 2) | current_state;
    
    int8_t direction = encoder_table[combined];
    
    s_isr_fire_count++;

    if (direction != 0) {
        BaseType_t xHigherPriorityTaskWoken = pdFALSE;

        encoder_event_t event = {
            .type = ENCODER_ROTATED,
            .direction = (direction > 0) ? ENCODER_CW : ENCODER_CCW,
            .timestamp = esp_timer_get_time(),
        };

        xQueueSendFromISR(encoder_event_queue, &event, &xHigherPriorityTaskWoken);

        if (xHigherPriorityTaskWoken) {
            portYIELD_FROM_ISR();
        }
    }
    
    prev_state = current_state;
}

// ISR handler for encoder button
static void IRAM_ATTR encoder_button_isr(void* arg) {
    BaseType_t xHigherPriorityTaskWoken = pdFALSE;
    
    encoder_event_t event = {
        .type = ENCODER_BUTTON_PRESSED,
        .timestamp = esp_timer_get_time(),
    };
    
    xQueueSendFromISR(encoder_event_queue, &event, &xHigherPriorityTaskWoken);
    
    if (xHigherPriorityTaskWoken) {
        portYIELD_FROM_ISR();
    }
}

esp_err_t encoder_init(void) {
    ESP_LOGI(TAG, "Initializing encoder");
    
    // Create event queue — 32 slots so burst-rotation during button hold doesn't overflow
    encoder_event_queue = xQueueCreate(32, sizeof(encoder_event_t));
    if (encoder_event_queue == NULL) {
        ESP_LOGE(TAG, "Failed to create encoder event queue");
        return ESP_FAIL;
    }
    
    // Configure encoder A and B pins
    gpio_config_t io_conf = {
        .pin_bit_mask = (1ULL << PIN_ENCODER_A) | (1ULL << PIN_ENCODER_B),
        .mode = GPIO_MODE_INPUT,
        .pull_up_en = GPIO_PULLUP_ENABLE,
        .pull_down_en = GPIO_PULLDOWN_DISABLE,
        .intr_type = GPIO_INTR_ANYEDGE,
    };
    
    esp_err_t ret = gpio_config(&io_conf);
    if (ret != ESP_OK) {
        ESP_LOGE(TAG, "Failed to configure encoder pins: %s", esp_err_to_name(ret));
        return ret;
    }
    
    // Configure encoder button pin
    io_conf.pin_bit_mask = (1ULL << PIN_ENCODER_BTN);
    io_conf.intr_type = GPIO_INTR_NEGEDGE;
    
    ret = gpio_config(&io_conf);
    if (ret != ESP_OK) {
        ESP_LOGE(TAG, "Failed to configure encoder button: %s", esp_err_to_name(ret));
        return ret;
    }
    
    // ISR service already installed by buttons_init(), just add handlers
    // gpio_install_isr_service(0);  // Already installed
    
    // Add ISR handlers
    gpio_isr_handler_add(PIN_ENCODER_A, encoder_rotation_isr, NULL);
    gpio_isr_handler_add(PIN_ENCODER_B, encoder_rotation_isr, NULL);
    gpio_isr_handler_add(PIN_ENCODER_BTN, encoder_button_isr, NULL);
    
    ESP_LOGI(TAG, "Encoder initialized");
    return ESP_OK;
}


void encoder_task(void* arg) {
    (void)arg;
    encoder_event_t event;
    int16_t step_accumulator = 0;
    uint32_t last_logged_isr_count = 0;

    ESP_LOGI(TAG, "Encoder task started (pins A=%d B=%d BTN=%d, threshold=%d)",
             PIN_ENCODER_A, PIN_ENCODER_B, PIN_ENCODER_BTN, ENCODER_STEPS_PER_PROFILE);
    ESP_LOGI(TAG, "Initial pin states: A=%d B=%d",
             gpio_get_level(PIN_ENCODER_A), gpio_get_level(PIN_ENCODER_B));

    while (1) {
        if (xQueueReceive(encoder_event_queue, &event, pdMS_TO_TICKS(2000))) {

            // Log ISR fire count whenever it changed — confirms interrupts are arriving
            uint32_t cur = s_isr_fire_count;
            if (cur != last_logged_isr_count) {
                ESP_LOGI(TAG, "ISR fired %lu times total", (unsigned long)cur);
                last_logged_isr_count = cur;
            }

            profile_t* current_profile = profile_get();
            encoder_config_t* enc_cfg = &current_profile->encoder;

            if (event.type == ENCODER_ROTATED) {
                if (event.direction == ENCODER_CW) {
                    step_accumulator++;
                } else {
                    step_accumulator--;
                }

                ESP_LOGI(TAG, "Rotation event: %s, accumulator=%d",
                         event.direction == ENCODER_CW ? "CW" : "CCW", step_accumulator);

                if (abs(step_accumulator) >= ENCODER_STEPS_PER_PROFILE) {
                    bool clockwise = step_accumulator > 0;
                    ESP_LOGI(TAG, "Threshold reached → firing %s action", clockwise ? "CW" : "CCW");

                    if (enc_cfg != NULL && clockwise && enc_cfg->cw_action_type != ACTION_TYPE_NONE) {
                        action_execute_raw(enc_cfg->cw_action_type, enc_cfg->cw_action_data, enc_cfg->cw_action_data_len);
                    } else if (enc_cfg != NULL && !clockwise && enc_cfg->ccw_action_type != ACTION_TYPE_NONE) {
                        action_execute_raw(enc_cfg->ccw_action_type, enc_cfg->ccw_action_data, enc_cfg->ccw_action_data_len);
                    } else {
                        ESP_LOGW(TAG, "No action configured for %s rotation", clockwise ? "CW" : "CCW");
                    }

                    step_accumulator = 0;
                }
            }
            else if (event.type == ENCODER_BUTTON_PRESSED) {
                vTaskDelay(pdMS_TO_TICKS(50));  // debounce

                int level = gpio_get_level(PIN_ENCODER_BTN);
                if (level == 0) {
                    uint64_t press_start = event.timestamp;

                    while (gpio_get_level(PIN_ENCODER_BTN) == 0) {
                        vTaskDelay(pdMS_TO_TICKS(10));
                        if ((esp_timer_get_time() - press_start) >= (BUTTON_LONG_PRESS_MS * 1000ULL)) {
                            break;
                        }
                    }
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

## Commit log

2026-03-26 Compiled but buggy
    [partitions.csv]
2026-04-19 feat: Now this is two-headed device
2026-04-21 fix: Fixed device connect status in UI
2026-04-22 fix: Fixes for HID device + stack overflow
    [action_executor.c, buttons.c]
2026-04-23 Fixing bugs and making plans
    [action_executor.c, profile_manager.c]
2026-04-24 fix: Readme and mux fixes
    [display_mux.c]
2026-05-03 feat: Delete buttonconfig dialog
2026-05-06 feat: Add text if there is no images for button
2026-05-11 fix: Fixing LEDS
2026-05-14 fix: Working TZT + debug
    [display_mux.c, gc9a01.c, image_transfer.c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]
2026-05-15 fix: SPI speed down to 20MHz (because of ringind)
    [config.h, display_mux.c, gc9a01.c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]
2026-05-23 feat: Add SPI brighteness control
2026-05-25 feat: USB library fix + media action
    [action_executor.c, profile_types.h]
2026-05-25 feat: Add hardware related files
    [cover_bottom.scad, cover_bottom.stl, cover_top.scad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]
2026-05-26 fix: Set recursion depth to 8
    [config.h]
2026-05-30 fix: Add encoder setup + text input fix
    [action_executor.c, encoder.c, profile_types.h]
2026-05-30 fix: Fixed USB wait timeout
    [main.c]
2026-06-07 fix: Set brightness in UI to 0-100 instead of 0-255
    [config.h]
2026-06-08 fix: Fixed cover (top and bottom)
    [cover_bottom.scad, cover_bottom.stl, cover_top.scad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]
2026-06-09 feat: Add 45 degrees stand model
    [stand.scad, stand.stl]
2026-06-10 feat: Installer + README + bugfixing
    [cover_bottom.scad, cover_bottom.stl, cover_top.scad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]
2026-06-10 fix: Block back button
2026-06-10 fix: Fixes fot folder-related bugs
    [action_executor.c, config.h, profile_manager.c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]
2026-06-10 fix: Fixes for icons on Launch app button
2026-06-11 fix: Fixes for exec
    [action_executor.c]
2026-06-11 fix: Fixed bug with no reconnects between UI and backend
    [image_transfer.c]
2026-06-11 fix: Fixes for screen-related bugs
    [main.c, profile_manager.c, protocol_handler.c]
2026-06-12 feat: Long press setup + night mode fixes
    [action_executor.c, buttons.c, profile_manager.c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]
2026-06-12 feat: Marks for long press + encoder fix
    [config.h, gc9a01.c, profile_manager.c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]
2026-06-13 fix: Fixes for encoder setup (UI)
2026-06-14 fix: Slightly change long click behaviour
    [buttons.c]
2026-06-15 feat: Screens speedup, folder long press fix + other fixes
    [config.h, image_transfer.c, profile_manager.c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]
2026-06-15 feat: Add buttons swap using drag-n-drop
2026-06-15 fix: Fixes for small visual bugs
    [profile_manager.c]
2026-06-16 fix: Several bugs fixed
    [image_transfer.c, profile_manager.c, protocol_handler.c]
2026-06-17 fix: Several fixes for save profile and image transfer
    [image_transfer.c, protocol_handler.c]
2026-06-17 fix: KB text size update + readme update
    [action_executor.c, protocol_handler.c, text_transfer.c]
2026-06-21 feat: Major changes (see description)
    - change protocol to improve speed and stability
    - change SPI work protocol to improve stability
    - add HomeAssistant plugin to switch entities from macroboard
    [buttons.c, image_transfer.c, main.c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]
2026-06-22 fix: Several stability related fixes + protocol speedup
    [config.h, image_transfer.c, main.c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]
2026-06-25 fix: Fixes for LCDs after refactor
    [action_executor.c, image_transfer.c, profile_manager.c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]
2026-06-25 fix: Fixes for SPIFFS store bugs
    [gc9a01.c, profile_manager.c, save_task.c]
2026-06-29 fix: Fixes for updates from plugin
    [display_mux.c, gc9a01.c, image_transfer.c]
2026-07-01 fix: Image work speedup
    [image_transfer.c, profile_manager.c, save_task.c]
2026-07-01 fix: Init speedup + fixes
    [gc9a01.c, main.c, protocol_handler.c]
2026-07-02 feat: Switch to LittleFS
    [partitions.csv]

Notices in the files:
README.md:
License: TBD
